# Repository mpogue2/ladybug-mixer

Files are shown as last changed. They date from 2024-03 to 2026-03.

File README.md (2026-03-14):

# ladybug-mixer
Second generation, portable, low-cost audio mixer for square dance callers and round dance cuers

**First pics of the LB-202 enclosure (powder-coated, laser-engraved lettering), and inside components**:

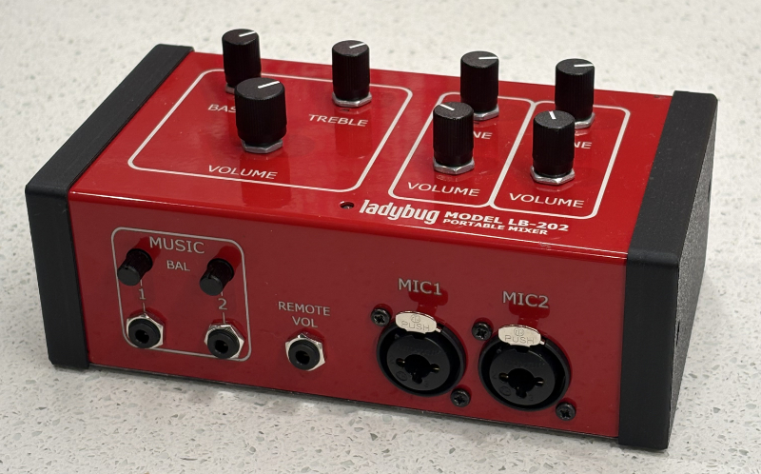
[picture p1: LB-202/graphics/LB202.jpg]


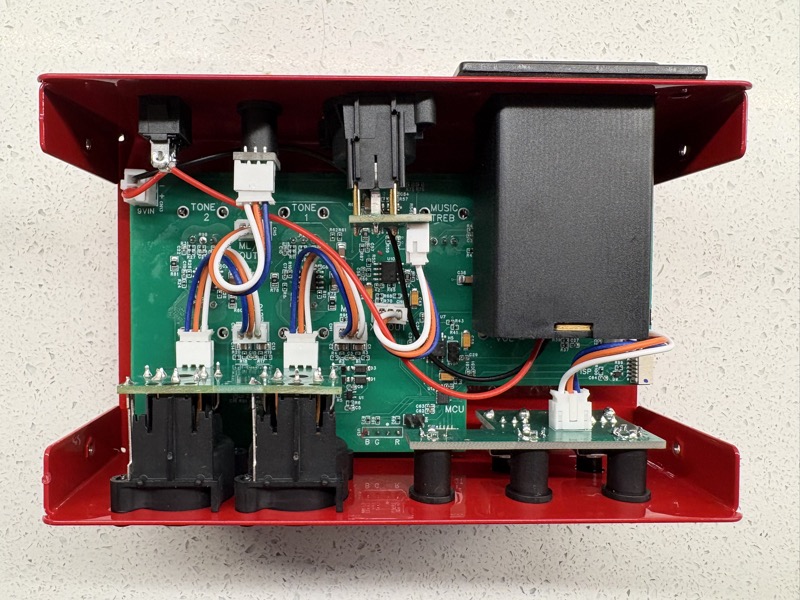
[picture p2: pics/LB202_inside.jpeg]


# Description

The Ladybug LB-202 Mixer is an inexpensive ($150 assembled) compact audio mixer, focused on the needs of beginning and intermediate square dance callers. With the addition of a high-quality dynamic microphone like a [Sennheiser e845 and cable, $100](https://www.amazon.com/Sennheiser-Cardioid-Handheld-Dynamic-Microphone/dp/B07CVK32VV), a [standard XLR mic cable for low-noise output, $10](https://www.amazon.com/dp/B01JNLTTKS), and a powered speaker like an [Alto TS-408, 2000W peak, $275](https://www.amazon.com/Alto-Professional-TS408-Bluetooth-Loudspeaker/dp/B0BB15J4TZ), a caller can provide high-quality sound for 8-10 squares for about $525.  If you have a small-to-medium-sized hall, the [Alto TX-408, 350W peak, $150](https://www.amazon.com/ALTO-Bluetooth-2-Channel-Musicians-Rehearsals/dp/B0DJT7DRHF) also works quite well, and is even less expensive.  These speakers are also chainable, using standard XLR cables, for sounding halls of just about any shape and size.

#### Compatibility with Hilton™-compatible mic cables
For compatibility with existing Hilton™-compatible microphone cables, the Ladybug Mixer provides two features:

1. Two "microphone combo jacks" that let you plug in a Hilton™-compatible 1/4" plug, OR a standard XLR cable (allows for a longer mic cable and best noise suppression, with no "dongle" required).
2. A 1/8" (3.5mm) jack for remote volume control (RVC).  The Ladybug RVC provides two volume-control curves:
    - a "Traditional" curve that matches the volume curve you get with a Hilton™ MA-220, or
    - a "Ladybug" curve that allows you to bring the volume all the way down to zero (MUTE).
   Which curve is in use is selected by using a SIM card tool to press an internal mode-switch button.
   
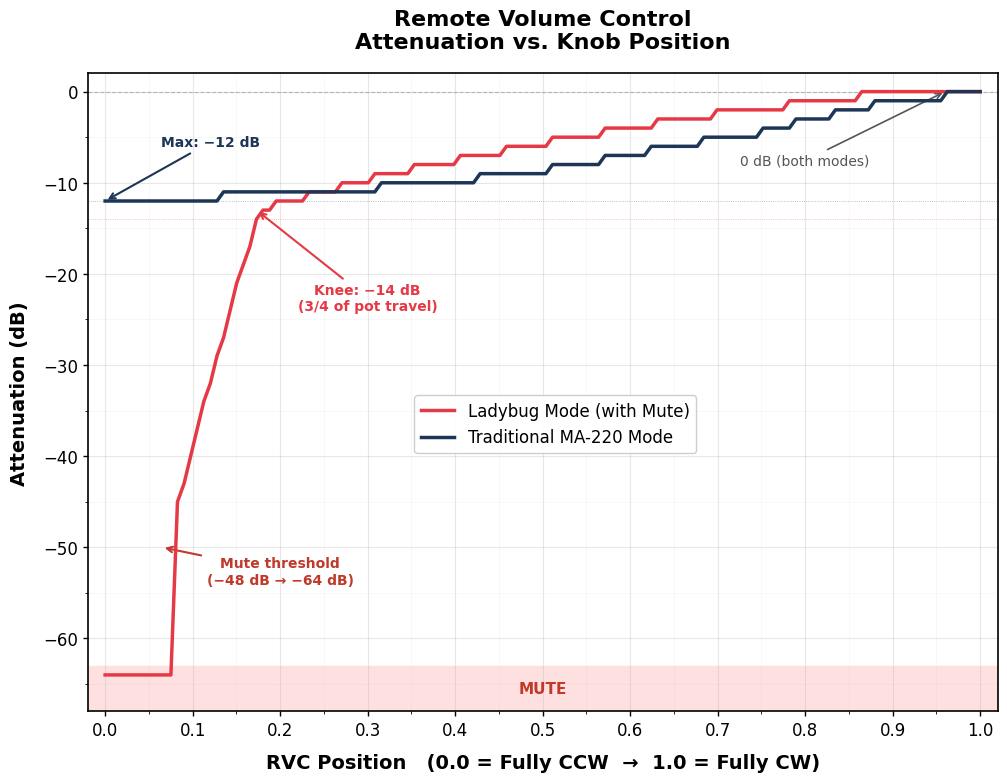
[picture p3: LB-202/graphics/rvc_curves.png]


#### RGB LED modes
The Ladybug LB-202 also provides several LED modes (selectable by using a SIM card tool to press an internal button) for use with the built-in RGB LED:

1. Battery Monitor (normally GREEN, changes to YELLOW, then dims and flashes RED when the battery is low)
2. VU Meter (pulses GREEN with the audio output, and changes to RED when clipping is present)
3. Solid colors (RED, GREEN, BLUE, or WHITE)

#### Long Battery Life
A single 9-volt alkaline battery provides power for lots of dances, and the Ladybug Mixer’s compact size makes it easy to carry. An off-the-shelf 9V alkaline battery ($1.50 from Amazon) will power the Ladybug mixer for about 90 hours (that's a lot of dances!), while a 9V lithium battery ($6.50 from Amazon) will probably last about 150 hours.

#### Open Source Design
The entire Ladybug Mixer design is available under an Open Source License, allowing anybody to modify the design to fit their specific needs. If anybody wants to build these commercially, they can do so, AS LONG AS any modifications they make are passed back to the community under the same licenses.  ***Let the creativity begin!***

> NOTE: The Ladybug LB-202 is a "mixer", and not a "mixer/amplifier".  A Hilton™ MA-220 is both a mixer and an amplifier, so it is able to send 220W of power to UN-powered speakers.  The Ladybug mixer is designed to send a "line-level" signal to speakers that are "powered", that is, the speaker has an amplifier built-in.  There are many popular "powered speakers" available nowadays, like the [Kustom PA-50](https://www.musiciansfriend.com/pro-audio/kustom-pa-pa50-personal-pa-system) (50 watts peak), the [Alto TS-408](https://www.sweetwater.com/store/detail/TS408--alto-ts408-2000-watt-8-inch-powered-speaker) (2000 watts peak), the [Bose L1 column speaker](https://www.bestbuy.com/site/bose-l1-pro8-portable-line-array-system-black) (300 watts peak), and many others.

The LB-202 mixer (shown above) uses a high-quality aluminum case (powder-coated in gloss red, and engraved with a 20W fiber laser), with an aluminum base panel, and black 3D-printed PLA side panels.

#### Differences from the First-generation LB-102 Mixer
| |  LB-102 |  LB-202 |
|---|:-:|:-:|
|  Music 1 vs 2 switch |  ✅ |  ❌ |
|  Music L/R Balance controls |  ❌ |  ✅ for cuers and split tracks |
|  LED |  white |  RGB |
| - VU Meter capability | ❌ | ✅ |
|  Mic tone controls |  12 o'clock position = FLAT EQ |  12 o'clock position matches MA-220 EQ (bass cut + treble boost) |
| Feature control | 2 internal jumpers | 2 user-accessible switches |
| Bottom panel | Black PLA | 5052 Aluminum |
| Firmware flash | Internal 0.1" pin header | Internal JST-SH connector |
| Future experimental features | ❌ | I2C via internal Stemma-QT connector |

# Specs
- 2 Music Inputs (1/8” stereo inputs), with balance controls for each
- 2 Combo Mic Inputs (Lo-Z XLR or Hi-Z [Hilton™-compatible](https://www.hiltonaudio.com/store/c3/Microphone_Cables.html) 1/4“ plug) 
- Remote Volume Control Input (20KΩ [Hilton™-compatible](https://www.hiltonaudio.com/store/c3/Microphone_Cables.html) 1/8” plug)
- Low-noise Balanced Output to powered speaker (XLR, +/- 10 volt differential swing at max volume)
- Separate Music (L) and Voice (R) out (1/8” stereo jack, +/- 2.5 volts swing max)
	- can use Music-only to a monitor speaker
    - can use Voice-only for hearing assist
- Uses a single 9V battery (no power supply to carry around, doesn't need a nearby power outlet)
	- Amazon Basics Alkaline ($1.50 ea. @ AMZN): about 90 hours
	- Tenergy Lithium ($7.00 ea. @ AMZN): about 150 hours
	- USB-rechargeable Lithium ($7.50 ea. @ AMZN): about 50 hours per charge
- RGB LED indicating power ON, battery level (pulses RED when low), and/or audio output level (VU Meter)
- Two pushbutton switches accessible via paperclip from the side, to select Remote Volume Control curve and LED function
- Low noise: -80dBfs
- Wide 3dB Bandwidth: Music 20Hz-20KHz, Voice 50Hz-20KHz
- Small size: about 6.2”W x 2.75”H x 3.8”D (157 x 70 x 97 mm)
- Light weight (with Alkaline battery): about 12.5oz (355g)
- Open Source Hardware, Software, and Mechanical Design (industry-standard open source licenses) = _anybody_ can build, customize, or service devices

# Files available under Open Source licenses
- SCH = schematic
- GERBER = PC board layout
- BOM = Bill of Materials (specifies which parts to place onto the board)
- CPL = "PickAndPlace" file, specifies where to place parts onto the board
- .xcs = xTool Studio files for the laser-engraved top/bottom/back/front
- .f3dz = compressed Fusion 360 files for enclosure and side panels
- .stl = 3D model for the 3D-printed side panels
- .asc/.asy/.pdf = simulation files for LTspice

# Open Source Licenses applying to all contents of this repository
- Hardware = CERN OHL-S (https://ohwr.org/cern_ohl_s_v2.txt)
- Software/Firmware = GNU General Public License version 3 (https://www.gnu.org/licenses/gpl-3.0.txt)
- Documentation = CC BY-SA License (https://creativecommons.org/licenses/by-sa/4.0/legalcode.txt)

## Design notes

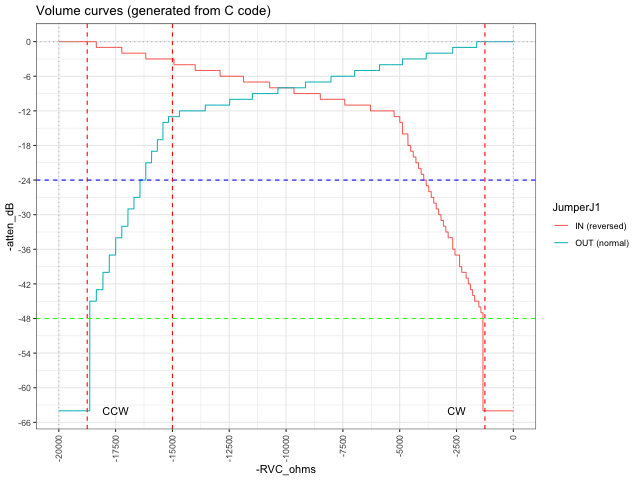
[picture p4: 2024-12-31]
LB-102/V4/Software/MCU_firmware/src/Ladybug RVC Volume Curve Design Target.png

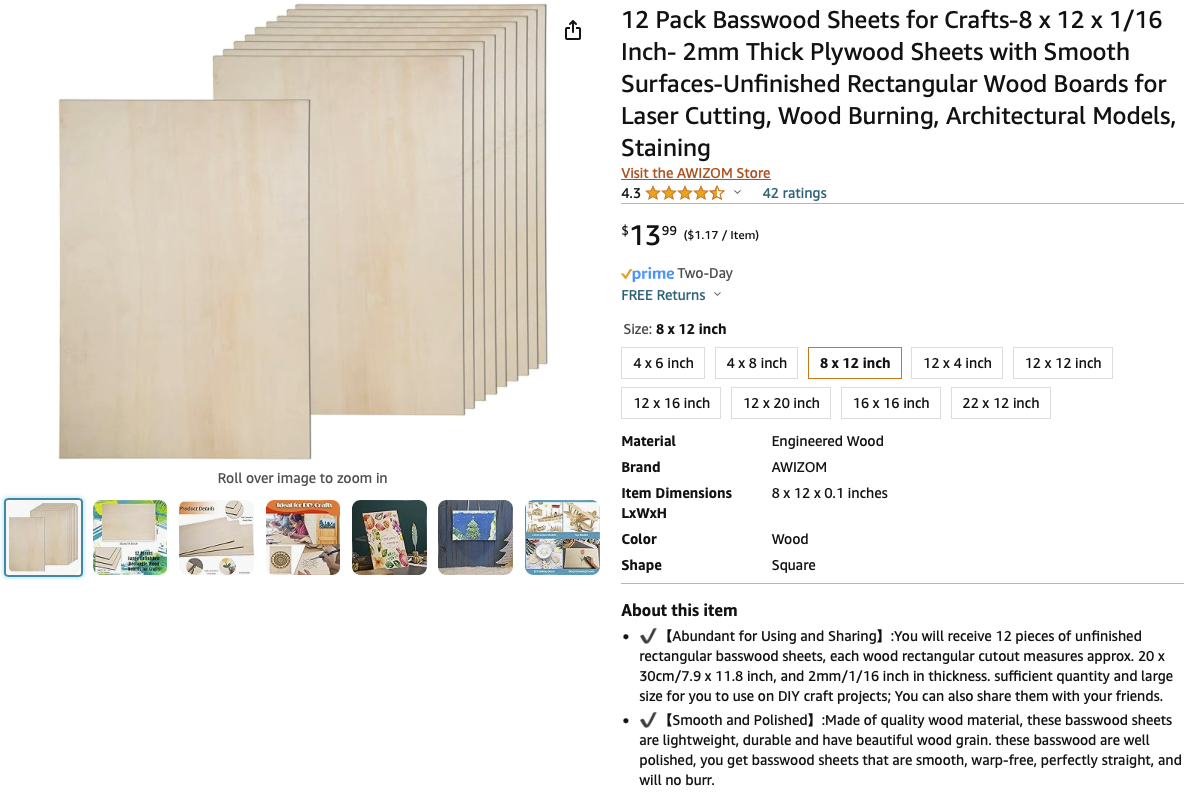
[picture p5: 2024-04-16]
docs/Basswood sheets for laser cut panels.png

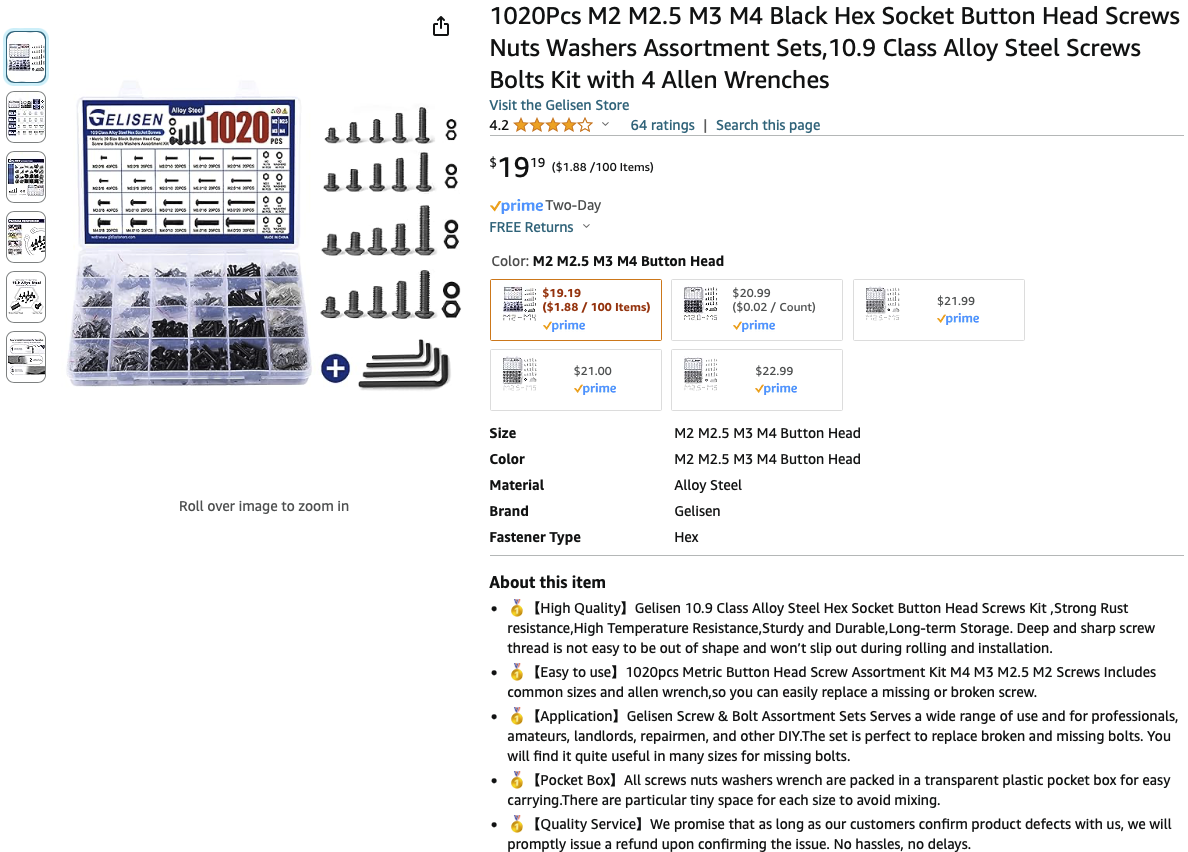
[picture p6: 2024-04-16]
docs/Black hex M2.5 and M2 screws.png

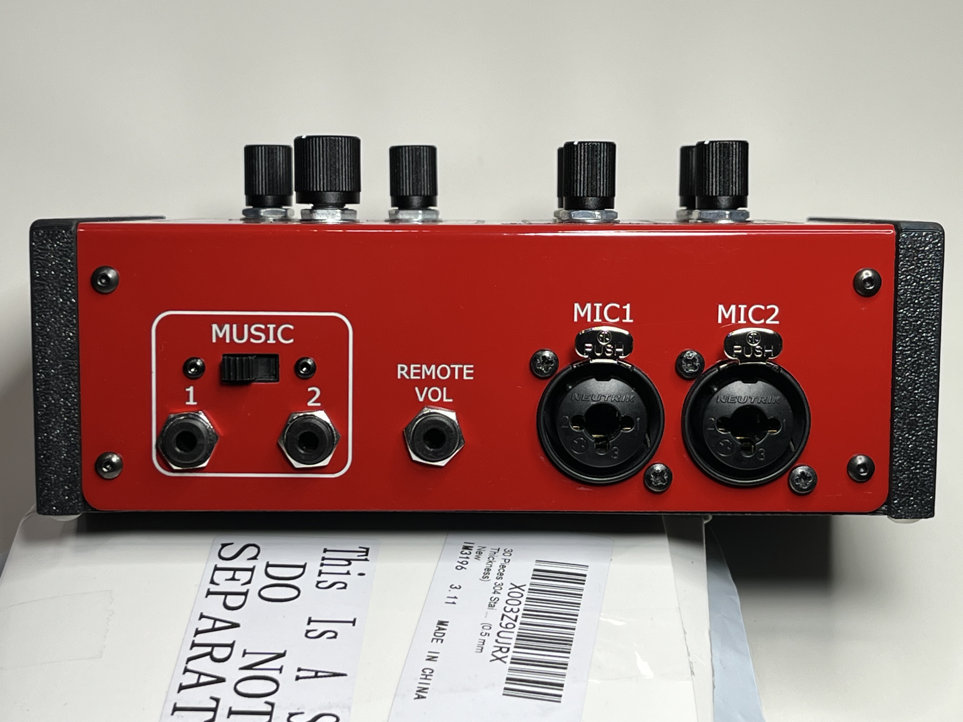
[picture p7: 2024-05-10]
pics/V3_Front.jpeg

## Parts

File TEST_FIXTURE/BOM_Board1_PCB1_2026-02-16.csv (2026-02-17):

No. | Quantity | Comment | Designator | Footprint | Value | Manufacturer Part | Manufacturer | Supplier Part | Supplier | JLCPCB Stock | JLCPCB Price | Add into BOM
1 | 1 | 22uF | C1 | CAP-SMD_L3.2-W1.6 | 22uF | CA45-A-16V-22uF-K | CEC(振华新云) | C782264 | LCSC | 42478 | 0.0231 | yes
2 | 1 | 100nF | C2 | C0402 | 100nF | CL05B104KO5NNNC | SAMSUNG(三星) | C1525 | LCSC | 36001098 | 0.0002 | yes
3 | 12 | 1uF | C3,C4,C5,C6,C15,C16,C17,C18,C19,C20,C21,C22 | C0402 | 1uF | GRM155R61C105KE01D | muRata(村田) | C77007 | LCSC | 587209 | 0.0006 | yes
4 | 8 | 22nF | C7,C8,C9,C10,C11,C12,C13,C14 | C0402 | 22nF | 0402B223K500NT | FH(风华) | C1532 | LCSC | 535509 | 0.0004 | yes
5 | 4 | 47pF | C23,C24,C25,C26 | C0402 | 47pF | 0402CG470J500NT | FH(风华) | C1567 | LCSC | 1735772 | 0.0002 | yes
6 | 4 | SJ-3523-SMT-TR | CN1,CN3,CN4,CN5 | AUDIO-SMD_SJ-3523-SMT-TR |  | SJ-3523-SMT-TR | CUI | C4991872 | LCSC | 880 | 0.2075 | yes
7 | 1 | HC-1.0-5PWT | CN2 | CONN-SMD_5P-P1.00_HCTL_HC-1.0-5PWT |  | HC-1.0-5PWT | HCTL(华灿天禄) | C2845364 | LCSC | 10988 | 0.014 | yes
8 | 1 | 1N5819WS | D1 | SOD-323_L1.8-W1.3-LS2.5-RD |  | 1N5819WS | Hottech(合科泰) | C191023 | LCSC | 2729513 | 0.0013 | yes
9 | 1 | PZ254V-11-02P | H1 | HDR-TH_2P-P2.54-V-M |  | PZ254V-11-02P | XFCN(兴飞) | C492401 | LCSC | 925157 | 0.0019 | yes
10 | 1 | KT-0805G | LED1 | LED0805-R-RD |  | KT-0805G | KENTO | C2297 | LCSC | 2333003 | 0.0024 | yes
11 | 1 | NCD0805R1 | LED2 | LED0805-RD |  | NCD0805R1 | 国星光电 | C84256 | LCSC | 8974619 | 0.002 | yes
12 | 1 | NC3FAH1 | PS1 | CONN-TH_NC3FAH1 |  | NC3FAH1 | NEUTRIK(优曲克) | C368476 | LCSC | 367 | 0.3147 | yes
13 | 1 | 0Ω | R1 | R0603 | 0Ω | 0603WAF0000T5E | UNI-ROYAL(厚声) | C21189 | LCSC | 4484188 | 0.0002 | yes
14 | 3 | 100Ω | R2,R27,R28 | R0402 | 100Ω | 0402WGF1000TCE | UNI-ROYAL(厚声) | C25076 | LCSC | 3925285 | 0.0002 | yes
15 | 9 | 20kΩ | R3,R4,R5,R6,R8,R9,R10,R11,R12 | R0402 | 20kΩ | 0402WGF2002TCE | UNI-ROYAL(厚声) | C25765 | LCSC | 1019773 | 0.0002 | yes
16 | 13 | 10kΩ | R7,R15,R16,R17,R18,R19,R20,R21,R22,R23,R24,R25,R26 | R0402 | 10kΩ | 0402WGF1002TCE | UNI-ROYAL(厚声) | C25744 | LCSC | 8086423 | 0.0002 | yes
17 | 2 | 1kΩ | R13,R14 | R0402 | 1kΩ | 0402WGF1001TCE | UNI-ROYAL(厚声) | C11702 | LCSC | 2605994 | 0.0002 | yes
18 | 1 | TS-1088-AR02016 | SW1 | SW-SMD_L3.9-W3.0-P4.45 |  | TS-1088-AR02016 | XUNPU(讯普) | C720477 | LCSC | 658938 | 0.007 | yes
19 | 1 | STC8G1K08-38I-QFN20 | U1 | TQFN-20L_L3.0-W3.0-P0.40-BL-EP |  | STC8G1K08-38I-QFN20 | STC | C521758 | LCSC | 3989 | 0.0969 | yes
20 | 1 | TPL0501-100DCNR | U2 | SOT-23-8_L3.0-W1.7-P0.65-LS2.8-BL |  | TPL0501-100DCNR | TI(德州仪器) | C131323 | LCSC | 6590 | 0.135 | yes
21 | 2 | NC3MAH | U3,U4 | CONN-TH_NC3MAH |  | NC3MAH | NEUTRIK(优曲克) | C5154126 | LCSC | 175 | 0.2863 | yes

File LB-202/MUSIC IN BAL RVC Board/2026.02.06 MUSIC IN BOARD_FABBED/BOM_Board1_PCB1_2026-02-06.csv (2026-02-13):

No. | Quantity | Comment | Designator | Footprint | Value | Manufacturer Part | Manufacturer | Supplier Part | Supplier | JLCPCB Stock | JLCPCB Price | Add into BOM
1 | 1 | 1nF | C1 | C0402 | 1nF | 0402B102K500NT | FH(风华) | C1523 | LCSC | 487032 | 0.0002 | yes
2 | 2 | 10kΩ | R1,R2 | SW-TH_PTV09A-4015F-B502 | 10kΩ | PTV09A-4220U-B103 | BOURNS | C7328484 | LCSC | 29 | 0.2049 | yes
3 | 2 | 1kΩ | R3,R4 | R0402 | 1kΩ | 0402WGF1001TCE | UNI-ROYAL(厚声) | C11702 | LCSC | 2915378 | 0.0002 | yes
4 | 1 | 47kΩ | R5 | R0402 | 47kΩ | 0402WGF4702TCE | UNI-ROYAL(厚声) | C25792 | LCSC | 2191944 | 0.0002 | yes

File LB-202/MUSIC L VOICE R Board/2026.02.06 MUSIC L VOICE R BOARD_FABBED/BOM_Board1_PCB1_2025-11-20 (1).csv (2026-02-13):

No. | Quantity | Comment | Designator | Footprint | Value | Manufacturer Part | Manufacturer | Supplier Part | Supplier | JLCPCB Stock | JLCPCB Price | Add into BOM
1 | 1 | PJ-31640 | CN1 | AUDIO-TH_XKB_PJ-31640 |  | PJ-31640 | XKB Connectivity(中国星坤) | C2879830 | LCSC | 922 | 0.0645 | yes
2 | 1 | B3B-PH-K-S(LF)(SN) | CN2 | CONN-TH_B3B-PH-K-S |  | B3B-PH-K-S(LF)(SN) | JST | C131339 | LCSC | 146729 | 0.0053 | yes

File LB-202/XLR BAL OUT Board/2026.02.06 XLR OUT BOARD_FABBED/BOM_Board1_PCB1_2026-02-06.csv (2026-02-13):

No. | Quantity | Comment | Designator | Footprint | Value | Manufacturer Part | Manufacturer | Supplier Part | Supplier | JLCPCB Stock | JLCPCB Price | Add into BOM
1 | 1 | B3B-PH-K-S(LF)(SN) | CN1 | CONN-TH_B3B-PH-K-S |  | B3B-PH-K-S(LF)(SN) | JST | C131339 | LCSC | 95840 | 0.0064 | yes
2 | 1 | NC3MAV-0 | PS1 | CONN-TH_NC3MAV-0 |  | NC3MAV-0 | NEUTRIK(优曲克) | C368527 | LCSC | 7 | 0.2969 | yes

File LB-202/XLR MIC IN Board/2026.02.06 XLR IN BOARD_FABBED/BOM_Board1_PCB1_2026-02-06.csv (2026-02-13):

No. | Quantity | Comment | Designator | Footprint | Value | Manufacturer Part | Manufacturer | Supplier Part | Supplier | JLCPCB Stock | JLCPCB Price | Add into BOM
1 | 2 | NCJ6FA-V | PS1,PS2 | CONN-TH_NCJ6FA-V |  | NCJ6FA-V | NEUTRIK(优曲克) | C368485 | LCSC | 103 | 0.4954 | yes

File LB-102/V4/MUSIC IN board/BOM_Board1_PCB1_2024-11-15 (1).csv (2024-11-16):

No. | Quantity | Comment | Designator | Footprint | Value | Manufacturer Part | Manufacturer | Supplier Part | Supplier | JLCPCB Stock | JLCPCB Price | Add into BOM
1 | 2 | PJ-31640 | CN1,CN2 | AUDIO-TH_XKB_PJ-31640 |  | PJ-31640 | XKB Connectivity(中国星坤) | C2879830 | LCSC | 221 | 0.4216 | yes
2 | 1 | B3B-PH-K-S(LF)(SN) | CN3 | CONN-TH_B3B-PH-K-S |  | B3B-PH-K-S(LF)(SN) | JST | C131339 | LCSC | 118662 | 0.0331 | yes
3 | 2 | A2005WV-5P | CN4,CN5 | HDR-TH_5P-P2.00-V-M |  | A2005WV-5P | CJT(长江连接器) | C225257 | LCSC | 275 | 0.0772 | yes

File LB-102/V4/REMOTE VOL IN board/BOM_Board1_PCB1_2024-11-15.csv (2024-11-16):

No. | Quantity | Comment | Designator | Footprint | Value | Manufacturer Part | Manufacturer | Supplier Part | Supplier | JLCPCB Stock | JLCPCB Price | Add into BOM
1 | 1 | PJ-31640 | CN1 | AUDIO-TH_XKB_PJ-31640 |  | PJ-31640 | XKB Connectivity(中国星坤) | C2879830 | LCSC | 221 | 0.4216 | yes
2 | 1 | B2B-PH-K-S(LF)(SN) | CN2 | CONN-TH_B2B-PH-K-S |  | B2B-PH-K-S(LF)(SN) | JST | C131337 | LCSC | 57141 | 0.029 | yes

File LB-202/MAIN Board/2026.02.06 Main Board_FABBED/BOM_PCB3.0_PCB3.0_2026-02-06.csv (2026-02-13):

No. | Quantity | Comment | Designator | Footprint | Value | Manufacturer Part | Manufacturer | Supplier Part | Supplier | JLCPCB Stock | JLCPCB Price | Add into BOM
1 | 4 | 22uF | C1,C2,C13,C14 | C0805 | 22uF | CL21A226MAQNNNE | SAMSUNG(三星) | C45783 | LCSC | 4498354 | 0.0039 | yes
2 | 6 | 10nF | C3,C9,C10,C15,C21,C22 | C0402 | 10nF | CL05B103KB5NNNC | SAMSUNG(三星) | C15195 | LCSC | 2679514 | 0.0003 | yes
3 | 13 | 20pF | C4,C5,C7,C11,C16,C17,C19,C23,C37,C54,C55,C56,C57 | C0402 | 20pF | 0402CG200J500NT | FH(风华) | C1554 | LCSC | 1390048 | 0.0002 | yes
4 | 14 | 100nF | C6,C8,C18,C20,C30,C31,C36,C39,C42,C48,C50,C51,C52,C62 | C0402 | 100nF | CL05B104KO5NNNC | SAMSUNG(三星) | C1525 | LCSC | 37249744 | 0.0002 | yes
5 | 5 | 10uF | C12,C24,C38,C40,C41 | C1206 | 10uF | CL31A106KBHNNNE | SAMSUNG(三星) | C13585 | LCSC | 877474 | 0.0087 | yes
6 | 1 | 47pF | C25 | C0402 | 47pF | 0402CG470J500NT | FH(风华) | C1567 | LCSC | 525192 | 0.0002 | yes
7 | 2 | 1uF | C27,C29 | C0402 | 1uF | CL05A105KA5NQNC | SAMSUNG(三星) | C52923 | LCSC | 5134488 | 0.0005 | yes
8 | 4 | 10uF | C32,C43,C44,C58 | CAP-SMD_L3.2-W1.6-RD-C7171 | 10uF | TAJA106K016RNJ | Kyocera AVX | C7171 | LCSC | 747405 | 0.0197 | yes
9 | 2 | 47nF | C33,C35 | C0603 | 47nF | CL10B473KB8NNNC | SAMSUNG(三星) | C1622 | LCSC | 2765952 | 0.0008 | yes
10 | 1 | 560pF | C34 | C0402 | 560pF | CC0402JRX7R9BB561 | YAGEO(国巨) | C541456 | LCSC | 7396 | 0.0003 | yes
11 | 1 | 10uF | C45 | CASE-B_3528 | 10uF | CA45-B-25V-10uF-K | CEC(振华新云) | C128259 | LCSC | 94160 | 0.0191 | yes
12 | 1 | 100nF | C46 | C0402 | 100nF | CL05B104KB54PNC | SAMSUNG(三星) | C307331 | LCSC | 45539919 | 0.0006 | yes
13 | 3 | 22uF | C47,C49,C53 | CAP-SMD_L3.2-W1.6 | 22uF | CA45-A-16V-22uF-K | CEC(振华新云) | C782264 | LCSC | 23782 | 0.0228 | yes
14 | 2 | 1nF | C61,C63 | C0402 | 1nF | 0402B102K500NT | FH(风华) | C1523 | LCSC | 487597 | 0.0002 | yes
15 | 5 | B3B-PH-K-S(LF)(SN) | CN1,CN2,CN3,CN5,CN6 | CONN-TH_B3B-PH-K-S |  | B3B-PH-K-S(LF)(SN) | JST | C131339 | LCSC | 95840 | 0.0064 | yes
16 | 1 | B2B-XH-A(LF)(SN) | CN13 | CONN-TH_B2B-XH-A-LF-SN |  | B2B-XH-A(LF)(SN) | JST | C158012 | LCSC | 360761 | 0.0054 | yes
17 | 1 | HCZZ0039-4 | CN14 | CONN-SMD_HCZZ0039-4 |  | HCZZ0039-4 | HC(虹成电子) | C7433440 | LCSC | 26349 | 0.0051 | yes
18 | 1 | HC-1.0-5PWT | CN15 | CONN-SMD_5P-P1.00_HCTL_HC-1.0-5PWT |  | HC-1.0-5PWT | HCTL(华灿天禄) | C2845364 | LCSC | 11042 | 0.0138 | yes
19 | 8 | 1N4004W | D1,D2,D3,D4,D5,D6,D7,D8 | SOD-123FL_L2.7-W1.8-LS3.8-RD |  | 1N4004W | R+O(宏嘉诚) | C18199087 | LCSC | 1900 | 0.0013 | yes
20 | 1 | 1N5819WS | D9 | SOD-323_L1.8-W1.3-LS2.5-RD |  | 1N5819WS | Hottech(合科泰) | C191023 | LCSC | 2832716 | 0.0013 | yes
21 | 1 | PZ254V-11-02P | H6 | HDR-TH_2P-P2.54-V-M |  | PZ254V-11-02P | XFCN(兴飞) | C492401 | LCSC | 842723 | 0.0019 | yes
22 | 8 | 160Ω | R1,R2,R3,R4,R17,R18,R19,R20 | R0402 | 160Ω | FRC0402F1600TS | FOJAN(富捷) | C2933075 | LCSC | 92191 | 0.0001 | yes
23 | 4 | 2.2kΩ | R5,R6,R21,R22 | R0402 | 2.2kΩ | 0402WGF2201TCE | UNI-ROYAL(厚声) | C25879 | LCSC | 1011850 | 0.0002 | yes
24 | 2 | 3.3kΩ | R8,R24 | R0402 | 3.3kΩ | 0402WGF3301TCE | UNI-ROYAL(厚声) | C25890 | LCSC | 853337 | 0.0002 | yes
25 | 3 | 15kΩ | R9,R25,R52 | R0402 | 15kΩ | 0402WGF1502TCE | UNI-ROYAL(厚声) | C25756 | LCSC | 437762 | 0.0002 | yes
26 | 4 | 20kΩ | R10,R26,R74,R76 | R0402 | 20kΩ | 0402WGF2002TCE | UNI-ROYAL(厚声) | C25765 | LCSC | 1133604 | 0.0002 | yes
27 | 12 | 22kΩ | R11,R16,R27,R32,R37,R40,R45,R48,R57,R58,R59,R87 | R0402 | 22kΩ | 0402WGF2202TCE | UNI-ROYAL(厚声) | C25768 | LCSC | 428385 | 0.0002 | yes
28 | 16 | 47kΩ | R12,R28,R39,R41,R43,R50,R55,R56,R71,R72,R75,R77,R93,R94,R95,R96 | R0402 | 47kΩ | 0402WGF4702TCE | UNI-ROYAL(厚声) | C25792 | LCSC | 2191869 | 0.0002 | yes
29 | 7 | 5.1kΩ | R14,R15,R30,R31,R73,R91,R92 | R0402 | 5.1kΩ | 0402WGF5101TCE | UNI-ROYAL(厚声) | C25905 | LCSC | 2518781 | 0.0002 | yes
30 | 6 | 1kΩ | R34,R62,R63,R69,R70,R104 | R0402 | 1kΩ | 0402WGF1001TCE | UNI-ROYAL(厚声) | C11702 | LCSC | 2916144 | 0.0002 | yes
31 | 9 | 10kΩ | R42,R47,R60,R61,R65,R66,R67,R68,R100 | R0402 | 10kΩ | 0402WGF1002TCE | UNI-ROYAL(厚声) | C25744 | LCSC | 9312414 | 0.0002 | yes
32 | 1 | 1MΩ | R49 | R0402 | 1MΩ | 0402WGF1004TCE | UNI-ROYAL(厚声) | C26083 | LCSC | 4490471 | 0.0002 | yes
33 | 3 | 11kΩ | R53,R54,R86 | R0805 | 11kΩ | 0805W8F1102T5E | UNI-ROYAL(厚声) | C17429 | LCSC | 113289 | 0.0003 | yes
34 | 1 | 47kΩ | R64 | R0805 | 47kΩ | 0805W8F4702T5E | UNI-ROYAL(厚声) | C17713 | LCSC | 1609920 | 0.0003 | yes
35 | 8 | 0Ω | R78,R79,R80,R81,R82,R83,R84,R85 | R0805 | 0Ω | 0805W8F0000T5E | UNI-ROYAL(厚声) | C17477 | LCSC | 4961409 | 0.0004 | yes
36 | 2 | 100kΩ | R97,R98 | R0402 | 100kΩ | 0402WGF1003TCE | UNI-ROYAL(厚声) | C25741 | LCSC | 6965776 | 0.0002 | yes
37 | 1 | 100Ω | R99 | R0402 | 100Ω | 0402WGF1000TCE | UNI-ROYAL(厚声) | C25076 | LCSC | 3836613 | 0.0002 | yes
38 | 1 | 0Ω | R101 | R0603 | 0Ω | 0603WAF0000T5E | UNI-ROYAL(厚声) | C21189 | LCSC | 5017889 | 0.0002 | yes
39 | 2 | 4.7kΩ | R102,R103 | R0402 | 4.7kΩ | 0402WGF4701TCE | UNI-ROYAL(厚声) | C25900 | LCSC | 6073212 | 0.0002 | yes
40 | 2 | TS-1084-AR03526 | SW1,SW2 | SW-SMD_TS-1084-AR03526 |  | TS-1084-AR03526 | XUNPU(讯普) | C720495 | LCSC | 6627 | 0.0104 | yes
41 | 2 | TLV6741DCKR | U1,U3 | SC-70-5_L2.0-W1.3-P0.65-LS2.1-BR |  | TLV6741DCKR | TI(德州仪器) | C2760465 | LCSC | 5939 | 0.1095 | yes
42 | 5 | MCP6002-I/SN | U2,U4,U5,U9,U10 | SOIC-8_L4.9-W3.9-P1.27-LS6.0-BL |  | MCP6002-I/SN | MICROCHIP(美国微芯) | C116706 | LCSC | 4310 | 0.0499 | yes
43 | 1 | LM1971MX/NOPB | U6 | SOIC-8_L4.9-W3.9-P1.27-LS6.0-BL |  | LM1971MX/NOPB | TI(德州仪器) | C129348 | LCSC | 97 | 0.2921 | yes
44 | 1 | MCP6001T-I/OT | U7 | SOT-23-5_L3.0-W1.7-P0.95-LS2.8-BR |  | MCP6001T-I/OT | MICROCHIP(美国微芯) | C116490 | LCSC | 99885 | 0.034 | yes
45 | 1 | HT7550-1 | U8 | SOT-89_L4.5-W2.5-P1.50-LS4.2-BR |  | HT7550-1 | UMW(友台半导体) | C347189 | LCSC | 410147 | 0.0059 | yes
46 | 1 | STC8G1K08-38I-QFN20 | U12 | TQFN-20L_L3.0-W3.0-P0.40-BL-EP |  | STC8G1K08-38I-QFN20 | STC | C521758 | LCSC | 4006 | 0.0957 | yes

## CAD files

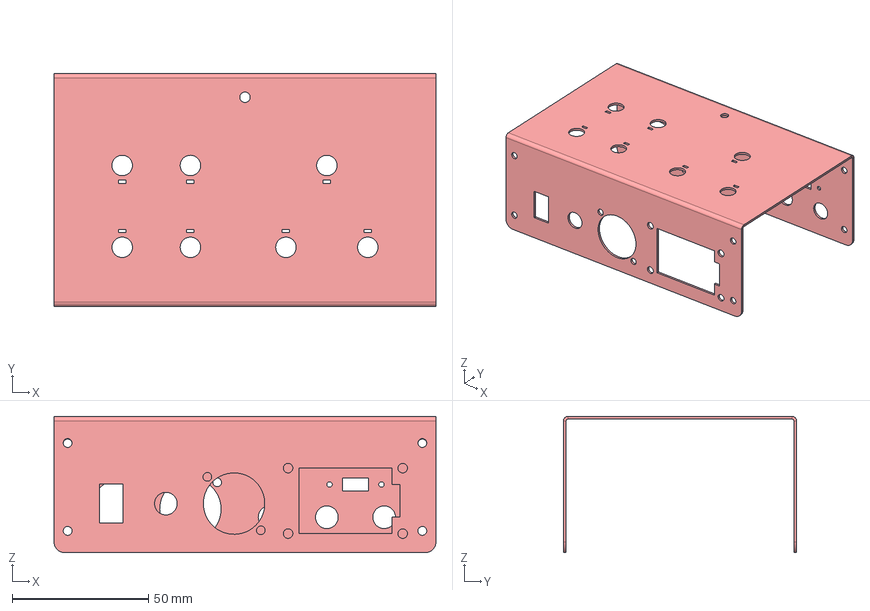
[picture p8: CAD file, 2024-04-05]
LB-102/V4/Enclosure/V3 Enclosure Simple v14_FABBED.step
140.0 x 85.5 x 50.0 mm

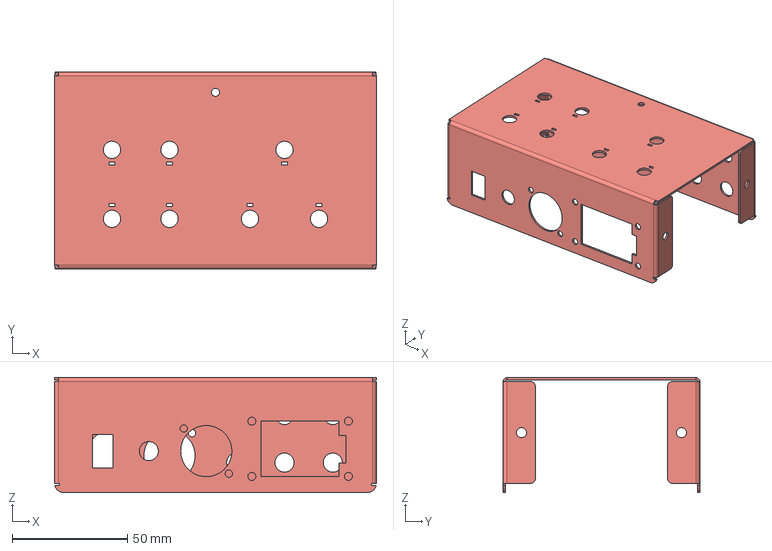
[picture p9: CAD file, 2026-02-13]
LB-202/Enclosure/Fabworks_FABBED/TOP_V11_2026.02.05.step
140.0 x 85.5 x 50.0 mm

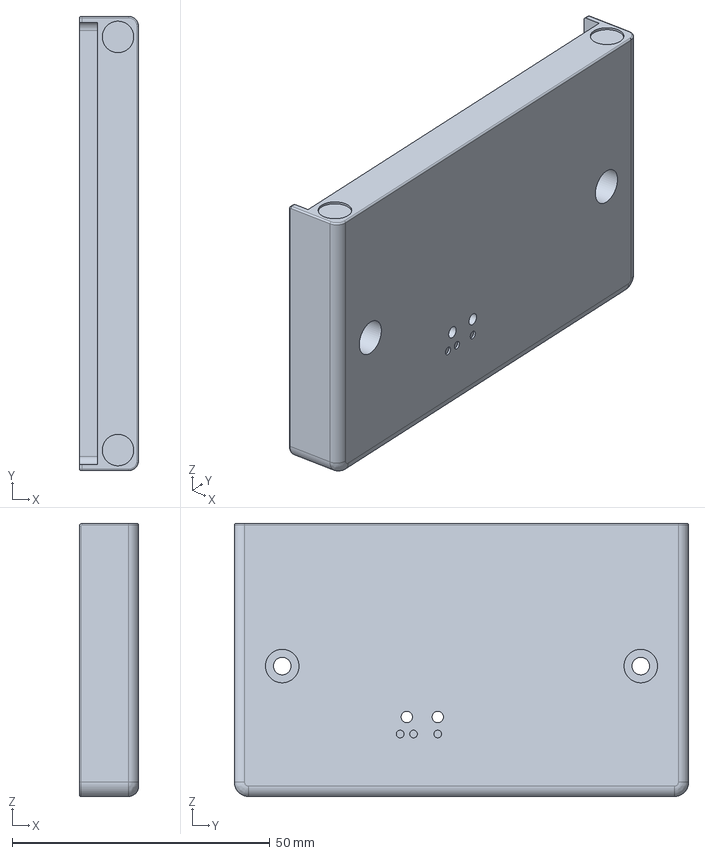
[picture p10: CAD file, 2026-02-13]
LB-202/Enclosure/Side Panels_FABBED/LEFT ENDCAP V18.step
11.5 x 88.1 x 53.0 mm

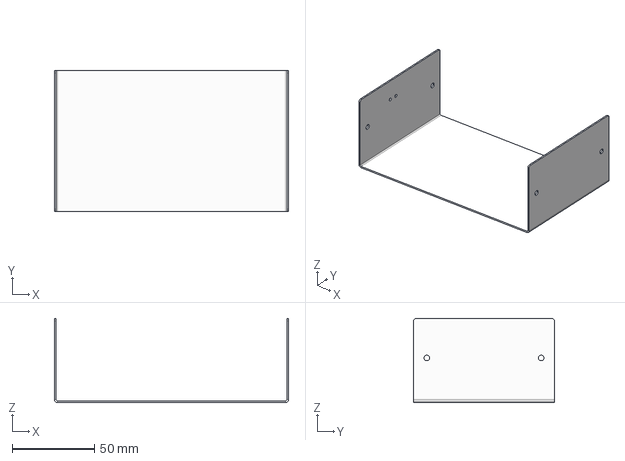
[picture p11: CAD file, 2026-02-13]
LB-202/Enclosure/Fabworks_FABBED/BOTTOM_V11_2026.02.05.step
142.2 x 85.5 x 51.1 mm

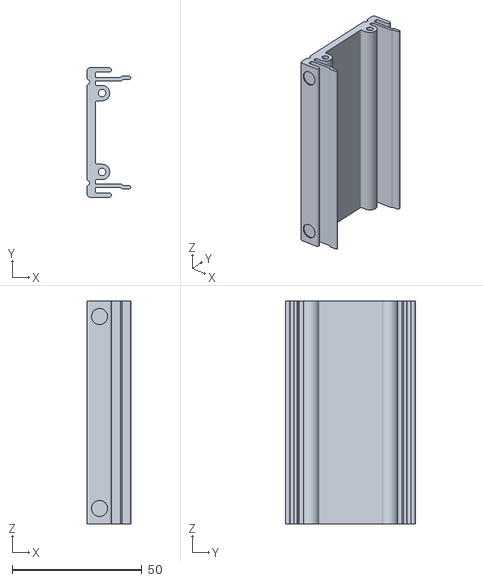
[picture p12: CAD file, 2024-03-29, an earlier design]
LB-102/V2/Enclosure/3DprintedSidePanels/sidePanel_V2 Body4.stl
16.8 x 50.0 x 86.0

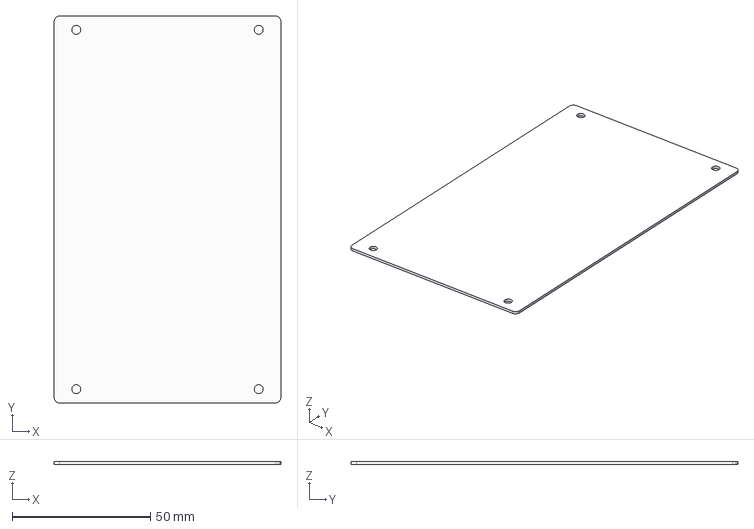
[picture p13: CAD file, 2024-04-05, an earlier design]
LB-102/V3/Enclosure/old/V3 Enclosure BOTTOM v4_FABBED.step
82.0 x 140.0 x 1.02 mm

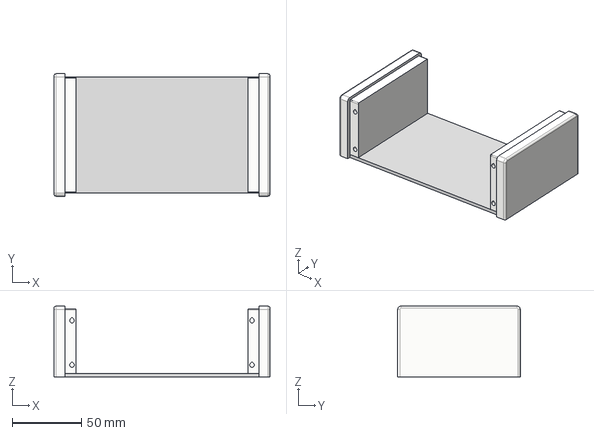
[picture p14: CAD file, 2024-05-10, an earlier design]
LB-102/V3/Enclosure/SidePanels/V3 U-shaped bottom + side panels v5.step
156.0 x 88.5 x 51.1 mm
V3 side panel x 2

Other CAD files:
LB-202/Enclosure/Side Panels_FABBED/RIGHT ENDCAP V9.step
LB-102/V2/Enclosure/3DprintedSidePanels/sidePanel_V2 v9 Fusion.f3d
LB-102/V3/Enclosure/SidePanels/V3 U-shaped bottom + side panels v5.f3z
LB-102/V3/Enclosure/V3 Enclosure Simple v14_FABBED.f3d
LB-102/V3/Enclosure/old/V3 Enclosure BOTTOM v4_FABBED.f3d
LB-102/V4/Enclosure/V3 Enclosure Simple v14_FABBED.f3d
V3/Enclosure/V3 Enclosure BOTTOM v4_FABBED.f3d

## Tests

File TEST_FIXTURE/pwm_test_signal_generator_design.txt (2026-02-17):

PWM Test Signal Generator Design Discussion
============================================
Date: February 16, 2026
Project: Ladybug Mixer Test Fixture

OVERVIEW
--------
Design of a PWM-based test signal generator using an STC8G1 MCU (24MHz)
to produce test tones for the Ladybug audio mixer's mic and music inputs.

MCU: STC8G1 @ 24MHz
PWM: 10-bit (1024 counts) → 23.4kHz PWM frequency
Signal: 1kHz sine tone

================================================================================
MIC OUTPUT SIDE
================================================================================

Target: ~2mV differential balanced output @ 1kHz

Circuit: PWM → 2-stage RC LPF → unbalanced-to-balanced voltage divider → XLR

Components:
  - R136: 10kΩ (filter stage 1)
  - C100: 22nF (filter stage 1)
  - R137: 10kΩ (filter stage 2)
  - C101: 22nF (filter stage 2)
  - R160: 10kΩ (divider, hot leg) — use 1% matched with R161
  - R163: 100Ω (divider, center)
  - R161: 10kΩ (divider, cold leg) — use 1% matched with R160
  - C76: 1µF (coupling cap, hot)
  - C77: 1µF (coupling cap, cold)
  - U15: NC3MAH XLR connector

Filter characteristics:
  - fc ≈ 720Hz per stage
  - Stage 1 attenuation at 1kHz: -4.7dB (×0.58)
  - Stage 2 attenuation at 1kHz (with 20.1kΩ divider load): -6dB (×0.49)
  - Divider ratio: 1/201 (-46dB, ×0.005)
  - Net attenuation: ×0.0014
  - At 56% duty cycle swing → 2mV differential output
  - PWM ripple at 23.4kHz: ~23µV differential (~1% of signal)

Notes:
  - Output impedance ~10kΩ per leg
  - Ladybug balanced mic input impedance ~2.8kΩ
  - Some signal loss to load expected; calibrate actual level with meter
  - Balance won't be perfect due to impedance mismatch, acceptable for functional testing
  - Not suitable for CMRR testing

================================================================================
MUSIC OUTPUT SIDE
================================================================================

Target: ~1-2V p-p unbalanced output @ 1kHz

Circuit: PWM → 2-stage RC LPF → coupling cap → output

Components:
  - Filter resistors: 10kΩ each stage
  - Filter caps: 22nF each stage
  - Coupling cap: 1µF series

Filter characteristics:
  - fc ≈ 720Hz per stage
  - At 1kHz: ~-6dB total (two stages)
  - ~2.5V available at full swing
  - Ladybug music input impedance ~70kΩ (minimal loading)

================================================================================
LADYBUG INPUT CIRCUITS (for reference)
================================================================================

Balanced Mic Input (TLV6741 difference amplifier):
  - Input resistors: R1+R3 = 160+160 = 320Ω per leg
  - Feedback resistors: R5 = R6 = 2.2kΩ
  - Gain: 2.2k/320 = 6.875 (+17dB)
  - Inverting leg impedance: ~320Ω
  - Non-inverting leg impedance: ~2.5kΩ
  - Differential input impedance: ~2.8kΩ

Music/RVC Input (MCP6002 buffer):
  - R34 (1kΩ) + R37 (22kΩ) + R39 (47kΩ) ≈ 70kΩ at audio

================================================================================
PWM RESOLUTION NOTES
================================================================================

STC8G1 PWM options (at 24MHz):
  - 6-bit:  64 counts,  375 kHz    — too few steps
  - 7-bit:  128 counts, 187.5 kHz  — poor resolution
  - 8-bit:  256 counts, 93.75 kHz  — usable
  - 10-bit: 1024 counts, 23.4 kHz  — chosen (good resolution)

At 10-bit:
  - ~82 usable duty cycle steps in ±4% range
  - ~23 samples per 1kHz sine cycle
  - Effective sine resolution: ~6.4 bits
  - THD after filtering: well under 1%

================================================================================
KEY DESIGN DECISIONS
================================================================================

1. 10-bit PWM chosen over 8-bit for better sine quality (82 vs 20 steps)
2. 22nF caps (not 220nF) to avoid excessive attenuation at 1kHz
3. 10kΩ/100Ω/10kΩ divider chosen as compromise between:
   - 100kΩ/1kΩ/100kΩ (too high output impedance for Ladybug input)
   - 1kΩ/10Ω/1kΩ (too much filter loading)
4. Same filter resistors (10kΩ) and caps (22nF) for both mic and music sides
5. Music side needs no voltage divider — just duty cycle adjustment

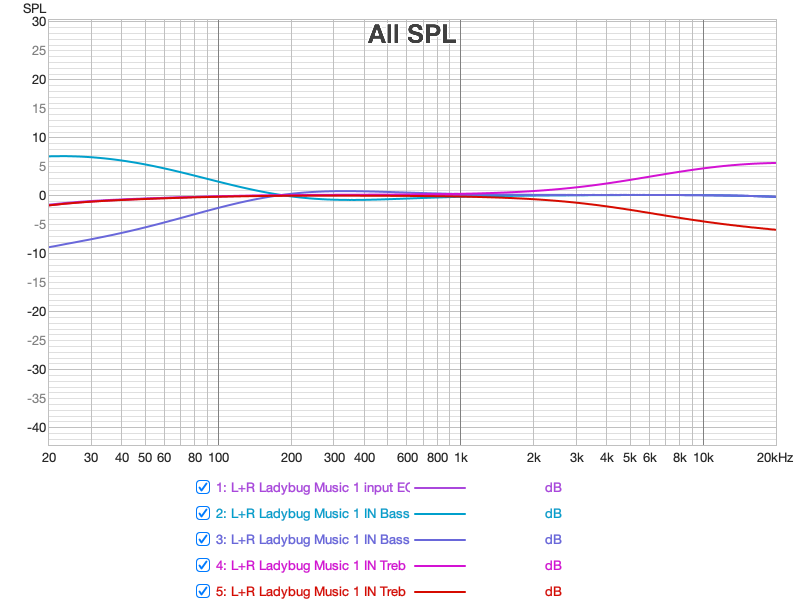
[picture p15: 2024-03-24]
tests/BandwidthAndEQ/V2_Music.png

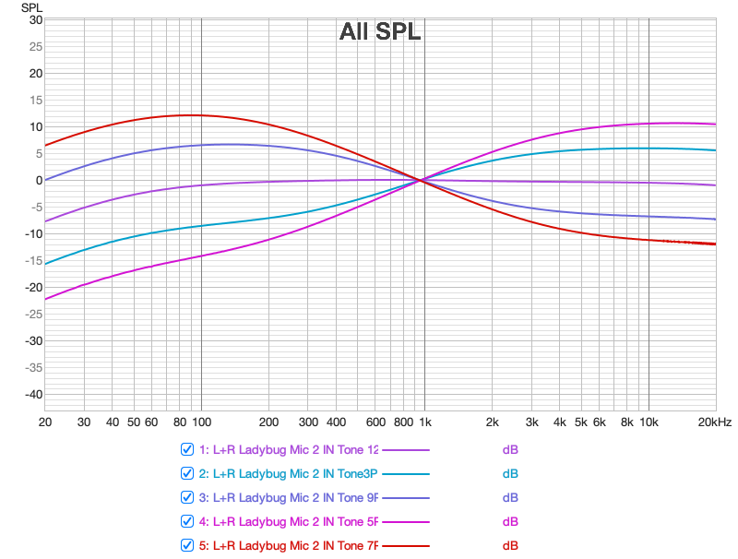
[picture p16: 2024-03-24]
tests/BandwidthAndEQ/V2_Mic2.png

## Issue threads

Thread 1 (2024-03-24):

TODO: V2 items for V3

mpogue2, 2024-03-24:
- add about 6dB of additional amplification (make sure does not exceed ±2.5V output for typical input though) **DONE**
- change tantalums to higher voltage to avoid future explosions  **DONE**
- move pots to after the tone controls to reduce noise when pots at min position  **DONE**
- eliminate JST PH connectors (next version can hard-wire, if appropriate)  **DONE**
- switch to single OP AMP (probably pick MIC 1 op amp, which has 3dB lower noise)  **DONE**
- add some jumpers to tell MCU some config info (might need diodes or resistors here)  **DONE**
  - Remote vol control direction is reversed from normal
  - Remove vol control goes all the way to zero (vs not)
  - LM1971 is not present (can this be figured out without a jumper via I2C -- nope, this cannot)
  - etc
- eliminate test jumpers, replace with pads + surface trace  **DONE**
- finalize the name (LB-102 vs  LB-201 etc.) - yeah, it's now LB-102  **DONE**
- add rear panel pics to the cut sheet

mpogue2, 2024-03-31:
Instead of jumpers, use 0 ohm resistors for test points.

mpogue2, 2024-04-01:
Replace LM1971 with C129348, which costs about $2.60 ea.
These are out of stock, but can be pre-purchased. Delay is <20 working days.  Then I can have them auto-assembled into boards.  I can also "consign" parts, that is, I buy the parts and send to them.

mpogue2, 2024-04-01:
**Pre-order**: https://jlcpcb.com/help/article/53-what-is-jlcpcb-parts-pre-order-service
**Consignment**: https://jlcpcb.com/help/article/245-how-to-consign-parts-to-jlcpcb

mpogue2, 2024-04-05:
LM1971MX/NOPB (Arrow) = Q10+ $1.32 ea.  These are C129348 in JLCPCB's numbering system.
This looks like the best Global Sourcing deal.  Takes 8-15 days, plus 1-2 days for review.
I'm gonna switch to this part, and mark it Do Not Populate for these first prototypes, but this will make it easier to order them for automated assembly next time.

mpogue2, 2024-04-05:
V3 boards (main board and XLR board) have been submitted to JLCPCB for fabrication.  Files have been posted to the repository.  Note that I could not do the manual op amp swap, because it generated an error and refused to populated the MCP6002s.  So, I went with the parts that I had in the schematic that are slightly more expensive, but should be identical.
The parts swap was only for testing (which is not needed for V3) and for cost reduction (minimal, so I gave up on it for V3).

V3 enclosure parts (5052-Al for top and bottom) have been submitted to Fabworks for fabrication. Files have been posted to the repository.

Closing this issue.

Closed 2024-04-05.

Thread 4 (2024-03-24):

Feature: FR-4 box

mpogue2, 2024-03-24:
in process
This will be sturdier than the laser-cut wood panels that I'm now using.  Silk-screened labels are also nice.  Can also use solder mask as part of the design.

mpogue2, 2024-04-05:
I'm gonna skip the FR-4 prototype box, and go right to the 5052-Al box with wood/3D-printed side panels.  It's not that expensive to do so, and it's a lot more sturdy, and more professional-looking.

Closed 2024-04-05.

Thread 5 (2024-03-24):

Feature: aluminum box with wood sides

mpogue2, 2024-03-24:
Like these, but perhaps powder coat in red, with silk screen or engraved labels, and use ebonized ash for the sides.  This should be fairly cheap, if we use one of the online CNC sheet metal houses (e.g. eMachineShop, fab works, SendCutSend, OSHcut, et.al.).  Engraving could be done by me via CNC mill or via laser engraver (MaxerNexus, maybe?).

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

mpogue2, 2024-03-29:
Hammond has some nice looking ones, but they are pricey (about $100 for this one, that is only 7"x5"x2")!
This might be nice for the next prototype, OR I could CNC mill + use Rubio Monocoat on the walnut sides, and have the sheet metal fabricated by one of the above service bureaus.

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

mpogue2, 2024-03-29:
I kinda like powder-coated red for the aluminum, rather than the natural aluminum finish, and perhaps ebonized ash for the sides....lettering would need to be engraved, though, perhaps by laser (unless one of the bureaus can do it)?

mpogue2, 2024-03-29:
**Fabworks**: Ventura, CA, does laser cutting (down to 0.040" 5052 Al), bending, powder coating, PEM insertion; prefers OnShape, but will take Fusion files too

**SendCutSend**: Nevada, laser cutting, bending, powder coating, PEM insertion; prefers SolidWorks, has excellent blog with lots of hints and tips articles, requires 0.063" thickness for powder coating (!)

**OSHcut**: Utah, laser cutting, bending, powder coating, NO PEM INSERTION;

NOTE: Hammond uses 0.040" = 18 gauge Al for their enclosures.

Most of these take DXF (unfolded) or STEP (FabWorks takes it folded, I think).

mpogue2, 2024-03-30:
Did a quick sheet metal mockup in Fusion 360, with holes in approximately the right places.  Quotes do not include wood or 3D-printed side panels, or a bottom aluminum panel.  These are NOT powder-coated, nor do they contain PEM hardware, so these are just cut and bend.

**FabWorks** (STEP format file): $17.12 ea, including shipping, ships in about 5 days
**SendCutSend**:
**OSHcut**:

mpogue2, 2024-03-30:
### Simplified design, without the two extra flanges for the bottom

**FabWorks**: **$12.09 ea Q2** deburred, $21.13 ea Q2 red $18.76 ea Q10 powder-coated
**OSHcut**: **$41 ea Q2** deburred, $93 ea Q2 red $38 ea Q10 powder-coated
**Ponoko**: **$47.42 ea Q2** NOT deburred, $18.21 ea Q10 NOT deburred

mpogue2, 2024-03-30:
**FabWorks** seems like the clear winner here, in terms of price, both for deburred and for red powder-coated aluminum parts.

**Fiber laser** seems like a good idea for making the markings on each side.  See [here](https://www.youtube.com/watch?v=5g_XDGyWqpY).  They use black in this video, but other sources suggested that red works as well.  Will need to test this.

mpogue2, 2024-03-30:
### XY Laser Cutters
**Maker Nexus**: $150/month -- 45W Epilog Helix, 100W Boss Laser LS2440, 100W "Red Laser bed"
**Hacker Dojo**: $150/month -- 100W Thunder Laser

mpogue2, 2024-03-31:
Here's a rendering of the V8 version of the simple (no bottom flanges) version of the V3 box design.
Sides will be 3D printed and/or ebonized ash wood.  This rendering is simulating a red anodized finish.  I'm also looking at a red powder-coated finish to keep the cost down.

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

Note the addition of a slide switch for music 1 vs 2, suggested by Mickey B at Callerlab.  This will prevent callers who are setting up from playing music when there is already a caller calling (yes, I have witnessed this!).

mpogue2, 2024-04-03:
### Wood prices

**Woodcraft** (S2S, 1/2"x3"x24" makes 6 side panels):
- Maple: $14.39
- Bloodwood: $21.79
- Purpleheart: $14.99
- Cherry: $16.79
- Gonzalo Alves: $15.49
- Walnut: $21.99 (about $3.70 each)

**Home Depot** (S4S, 1"x4"x8' times 2 boards):
- Walnut: $109 (makes about 200 side panels, so about $0.50 each))

### Finishes

**Rubio Monocoat** (Pure, 130ml): Amazon $36 (I don't know how much is used per side panel, though, probably not a lot)

mpogue2, 2024-04-06:
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

Fabworks 5052 Al pieces arrived about an hour ago…This is what they look like, with components installed.  These are unfinished, just deburred (checking for fit).

3 of each part, 5052 0.040” Aluminum, $43 and that included shipping.  Order placed Tuesday 4/2 @ 1AM, package arrived Friday 4/5 @ 7PM.  Can’t beat that price or that delivery time.

pkbott, 2024-04-06:
This is looking really goodReady to try something FUN, UNIQUE and ***@***.*** Square Dance Group:  https://www.facebook.com/groups/squaredanceforfun/On Apr 5, 2024, at 11:09 PM, Mike Pogue ***@***.***> wrote:
IMG_4219.jpeg (view on web)
Fabworks 5052 Al pieces arrived about an hour ago…This is what they look like, with components installed.  These are unfinished, just deburred (checking for fit).
3 of each part, 5052 0.040” Aluminum, $43 and that included shipping.  Order placed Tuesday 4/2 @ 1AM, package arrived Friday 4/5 @ 7PM.  Can’t beat that price or that delivery time.

—Reply to this email directly, view it on GitHub, or unsubscribe.You are receiving this because you are subscribed to this thread.Message ID: ***@***.***>

mpogue2, 2024-04-06:
I'm also working on 3D printed side panels, but I really want to make some walnut ones... :-)

mpogue2, 2024-04-06:
Today I also tested using brass threaded inserts into the PLA side panels, as a way to get a tighter screw connection from the front/top/rear/bottom panels into the side panels.

**Notes**:
- Different vendors' inserts needed different hole sizes.
- Inserts on the top require a different hole size (and shape) from inserts on the side of a PLA print.  This is because of the way slicing works -- layers are built up one at a time from bottom up.
- My daughter Amber's threaded inserts had the least squeeze out, and therefore the easiest insertion (no trimming required, took up less space than the threaded inserts I had bought).  I'll try to get a part number for these (box was unbranded).
- All of these results were with Fusion 360 modeling, printed a test block with Black Basic PLA from Bambu.

**Results**:
- For M3xH5.7 screws on the TOP, use a 4.1mm hole.
- For M3xH5.7 screws on the SIDE, use a 3.8mm hole with a teardrop shape (pointy end up, avoids needing supports)
- For M2.5xH6 screws on the TOP, use a 3.3mm hole.
- For M2.5xH6 screws on the SIDE, use a 3.1mm hole.
- For M2xH6 screws on the SIDE, use a 3.0mm hole.
- For all inserts, used a fairly pointy Weller-compatible tip, and 450˚F temperature setting.  I went slow but steady, and did not have a jig (just angled the iron vertically, pushed the insert into the hole, relatively tight fit, and inserted the tip of the iron and pushed straight down slowly, until the head went just under the surface).
- With the right size hole, no trimming was needed.
- I got very weak holes with just 2 loop walls in the slicer (the default).  All the tests above were done with 4 loop walls, which seemed like it resulted in a much stronger and more repeatable part.

Weller tip I used:
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

Amber's inserts:
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

mpogue2, 2024-04-06:
TODO (next version of Aluminum front/top/rear bracket):
- the hole for the LED is a little too big.  Reduce size, or use a plastic.grommet
- the rocker switch is way too loose in the hole.  I think the 0.040" thickness of 5052-Al is probably not the panel thickness this switch is designed for.  Either make the hole smaller, or make 1mm gasket to hold it firmly in place.
- double check for interference with the XLR PCB at front XLR installation time
- consider making the screw holes smaller, since I've now converged on M2.5 screws (instead of M3)

TODO (next version of Aluminum bottom panel):
- the small side needs to be a bit bigger, because the bends took less space away form the top's dimension than expected
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
mpogue2, 2024-05-03:
I got a 20 watt ComMarker B4 fiber laser yesterday, and I ran a couple of tests today.  **There's a clear winner!**

In each case, these are the Ladybug logo (the word "ladybug" is 5.57mm tall), the Model Number (which is 2.5mm tall), the generic name ("PORTABLE MIXER" is 1.5mm tall), and the word "VOLUME" is 3.07mm tall.  In all cases, the laser parameters were:

- 500 mm/sec
- 100% power
- 30KHz frequency
- Fill
- .02 mm line spacing
- 6 passes

Here is that test pattern engraved on Brushed 5052 Aluminum.  This is the best lighting I could do to make it readable.  Many other positions of the light made the light gray color blend into the background, and so the lettering was not legible from all angles!

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

Here is the same engraved on Powder Coated 1018 Steel.  The color of the lettering is grey, so the contrast is not great with the background.  Better than the brushed aluminum, though!

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

Here is same test engraved on Powder Coated 5052 Aluminum.  This one came out nice!  Crisp, clean edges, nice contrast between lettering and background, and readable at all angles.  This is the winner!

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

By the way, in that last picture, if you look at the Material Test over to the left (5x5 matrix of squares), it has letters that are only about 0.5 mm tall!  I can just barely read it without a magnifying glass....this fiber laser marker is pretty amazing!

I have one more test to run here, which is to use the CerMark spray on the Aluminum, and see if I can get dark black lettering.  I could also consider mixing white lettering and black lettering (perhaps for the "bug" part of the logo?)

mpogue2, 2024-05-04:
Did a lot of trial and error with the fiber laser today.  It really likes bolder fonts, and larger fonts.
Thin parts of a glyph don't get really white.  And, the centers of glyphs like "P" and "R" and "A" are
often missing, when the font is small.

After a large number of tries of settings, fonts, and font sizes, I found some combinations that I think will work pretty well.
Hopefully these are the final settings for the fiber laser for this version of the mixer, at least:

Material: 5052-H32 Al with red gloss powder coating, from Fabworks
Settings: 1000/100%/30K/0.02/4 Passes

Font sizes:
- "ladybug": Grayson 7mm
- "MODEL LB-102": Verdana Bold 3.0mm
- "PORTABLE MIXER": Verdana Bold 2.0mm

Result:
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

mpogue2, 2024-05-04:
For the record, at least with the settings I tried, the CerMark test didn't come out all that much better than before with Rich's CO2 laser.  Maybe it needs different settings, but for now, I think the "brushed aluminum" option is tabled.

mpogue2, 2024-05-04:
FYI -- It looks like I can specify a frequency << 20KHz in the Materials Test in Lightburn, and the labels on the resulting set of squares claims to do it.  But, in actuality, this fiber laser can't go below 20KHz.  That explains why all the tiny squares in the image above look about the same.

FYI: Lower KHz frequencies represent more aggressive cutting.

mpogue2, 2024-05-06:
The top of the enclosure is wide enough, that I have to engrave the lettering in 2 passes.  I split into the Left half, and the Right half, and I have "Tool" layers (that don't engrave, they just mark the pot hole locations) to help line up each pass manually.  I decided that I did not need a fancy fixture, just a horizontal plexiglass bar (included with the fiber laser), and a manual slide of the part to horizontally get it to the right position.  I can do something fancier later.

This test plate was powder-coated, but not laser cut, so it has no holes.  It's just for testing the engraving.

Here's how it came out:

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

mpogue2, 2024-05-06:
The bottom panel and side panels are 3D printed right now, using Bambu PLA Matte Black.
Here's what fiber laser (ComMarker B4 w/110mm lens) engraving on the flat bottom panel looks like:

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

It's hard to see in this pic, but the bottom one (2 passes instead of one) has a darker outline, so it's more readable.  However, I do see that this engraving is light-direction-sensitive, so it can be read way better at certain angles, and way worse at others.  Despite that limitation, I think it will be fine for now.

Note: XH = Cross Hatch ON

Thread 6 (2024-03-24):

Feature: PCB for the front XLR connectors

mpogue2, 2024-03-24:
Might make it easier to wire up, at minimal cost.

mpogue2, 2024-04-01:
OK, I designed the PCB for the front XLR Combo jacks.  This will probably save me about 1/2 hour of time per box wiring up the combo jacks (which was a PITA).

Board looks like this (and, JLCPCB can assemble the Neutrik connectors too!):

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

The JST PH connectors are NOT populated in the shipped version.  Will just be stranded wires from those pads to the main PCB, saving a bit of cost.

The price for the connectors is pretty good, too, compared to Full Compass.
**JLCPCB**: $91 FOR 10 boards (including 20 connectors and assembly) and shipping and tax = **$9.10 per board**
**Full Compass components price**: $38 for 20 connectors alone, plus shipping and tax is about $20, so $58 roughly.

And, just for the boards and having _me_ do assembly would be about:
**Full Compass + me doing assembly**: 58 + $4 (5 boards) = **$5.90 per board**

So, the added cost for just the added PCB is about $4/5 = ~$1 per device, but it saves about 1/2 hour of assembly time per device.  Well worth it, I think.

mpogue2, 2024-04-01:
I don't think it's worth it to make a PCB for the output XLR connector, since it's just 3 wires, with no funky wiring between the pins (as is done for the front XLR combo jacks).

mpogue2, 2024-04-05:
Submitted for fabrication and assembly at JLCPCB.  The added cost for assembling them there was pretty minimal.

Therefore, closing this issue.

Closed 2024-04-05.

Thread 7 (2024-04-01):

Problem: JLCPCB is out of the header pins

mpogue2, 2024-04-01:
Can't reorder either of the previous main boards, because of this shortage.  I have plenty of those here, it's just the time it takes to solder them, and the time to remove those pins from the BOM.

mpogue2, 2024-04-05:
They are out of the 2-pin headers, but the 2x2 and the 1x4 headers are still very in-stock.
Designed out the 2-pin headers, and replaced with 0805 0Ω resistors, acting as removable jumpers and test points.

Closed 2024-04-05.

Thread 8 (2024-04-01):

TODO: run battery test on the Tencent lithium 9V battery

mpogue2, 2024-04-01:
Test is running now...I expect it will run for about 2 weeks or so.

mpogue2, 2024-05-09:
Done.  It's about 300 hours.

pkbott, 2024-05-09:
Is this continuous use?Ready to try something FUN, UNIQUE and ***@***.*** Square Dance Group:  https://www.facebook.com/groups/squaredanceforfun/On May 9, 2024, at 5:08 AM, Mike Pogue ***@***.***> wrote:
Done.  It's about 300 hours.

—Reply to this email directly, view it on GitHub, or unsubscribe.You are receiving this because you are subscribed to this thread.Message ID: ***@***.***>

mpogue2, 2024-05-09:
@pkbott Yes.  Here is the graph of my testing, done with 3 different battery technologies.  These were run continuously, while recording the battery voltage every 2 minutes.  I consider a battery "done", when it gets down to 5.5 volts.  The mixer will still run below that voltage, but you'll start to get audio clipping at higher volumes.

This is the reason why I removed the 12V jack (for an external wall-wart style power supply).  When a single alkaline battery lasts 170 hours (that's probably about 50 dances), it doesn't make sense to have to plug it into an outlet.  I worked very hard to keep the power consumption this low, and excellent battery life is the result! :-) :-)

Remember that this is a mixer, and the signal must be sent to a powered speaker (which has the power amplifier inside).
So, the mixer part doesn't actually need much power at all!

I'm also investigating some very inexpensive power amplifiers, perhaps for a future version.  Adding a power amp would definitely require using an external power supply.

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

The horizontal red dashed line is where I declare the battery to be "done".  The horizontal dotted green line is where I start notifying the user of low battery, by starting to blink the LED on the front panel.  The lower the battery voltage, the longer the front panel LED will be OFF.  When the battery gets down to the horizontal dotted red line, the front panel LED is on only 1/10 of the time, indicating that battery should be replaced soon.  The LED won't go lower than off 9/10 + on 1/10 of the time, just to make sure that the user sees that the battery is low.  This is all done in software by the microprocessor, which monitors the battery voltage and controls the LED.

Closed 2024-10-04.

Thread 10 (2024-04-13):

BUGS/FEATURES: Main Mixer Board V2.2

mpogue2, 2024-04-13:
Bugs found (or other changes needed) for the Main Mixer Board V2.2 will be added here in this ticket.

### Bugs:
- **Missing a trace from ground to R72, C49, C50**
  - this wire was accidentally deleted at some point from the PCB (it was obviously there before)
  - it was not discovered, because it appears that I didn't do a final DRC, which DID detect the problem
  - temporary fix (until next PCB spin): solder a small wire between pin 1 (GND) of U8 to the - pin of C49.

### Features or other changes to make:
- **make the order of the wires match the order of the XLR board**, so that wires don't cross (minor)

mpogue2, 2024-10-04:
FIXED in V2.4

Closed 2024-10-04.

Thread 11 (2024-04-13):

FEATURE: bringup progress on Mixer Board V2.2

mpogue2, 2024-04-13:
- **MIC inputs**
  - MIC1 and MIC 2 generate reasonable output with XLR cable [PASS]
  - MIC1 and MIC 2 generate reasonable output with Hilton-compatible cable [PASS]
  - MIC vol and EQ controls work reasonably [PASS]
- **MUSIC inputs**
  - MUSIC1 and MUSIC2 generate reasonable output [PASS]
  - MUSIC vol and EQ controls work reasonably [PASS]
  - can switch between MUSIC1 and MUSIC2 with slide switch [PASS]
- **Output signals**
  - Balanced output to Alto TS-408 works [PASS]
  - 3.5mm output jack signal is reasonable
    - Music L [PASS]
    - Voice R [PASS]
  - very little pop when powering on mixer [PASS]
- **MCU programming**
  - ISP programming works reliably [PASS]
- **Jumpers**
  - MCU can sense the jumpers (J1 and J2) at power-on time, and can decode them correctly [PASS]
- **Remote Volume Control**
  - MCU can sense the remote volume control pot correctly [PARTIAL PASS; design was 0 - 2.5V to ADC3, and I'm getting 0 - 4.7V, possibly the 4.1K resistor is turned on by accident? The math works out for that...It does seem reliable right now, although it might be consuming slightly more power than expected.]
  - LM1971 is installed [YES]
  - MCU can control the LM1971 for remote volume control [PASS]
  - Volume is down at least 60dB in the MUTE state [PASS, 60dB is as low as Audacity can measure]
  - Volume changes are without audible pops [PASS, for regular music and a sine wave]
  - Volume goes to FULL, when there is no Remote Vol Control plugged in [PASS]

mpogue2, 2024-04-14:
TO BE FIXED for next version of the main board:
- add in the GND wire for U8, re-run ground plane update, and re-run DRC
- add a 10µF 6 to 10VDC cap for the Vrefin on the LM1971 (I can prototype this, because I have the caps in 0805 form)

mpogue2, 2024-10-04:
This is all DONE.

Closed 2024-10-04.

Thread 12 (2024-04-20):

FEATURE: next generation feature list

mpogue2, 2024-04-20:
Now that the first generation is almost complete, it's time to start thinking about the second generation mixer design:

### Possible next gen features:
- 4 mic channels (up from 2)
- 4 remote volume controls (up from 1)
- 4 mute controls (up from 0)
- balance and overall gain controls (up from 0)
- USB interface
  - for power
  - for recording/playback to/from a laptop
  - for control of a music player from a bluetooth dongle
- 2 balanced outputs (up from 1; one for the powered speaker, one for connecting to a Williams transmitter)
- 2 LEDs (up from 1)
  - red peak-reading LED
  - white normal peak-reading LED
  - or a VU-meter style LED array
  - or a small bright display
- 32-bit MCU (e.g. STM32)
  - compression/decoding to/from an SD card
- boost power supply (e.g. 9V -> +/-15V) for increased output
- separate Treble/Bass for Mic channels (e.g. concentric pots)

mpogue2, 2024-05-10:
From Ett:
- Is it possible to add-on a USB plug both the USB C the usb traditional rectangular so we can charge our devices while using this mixer? (This idea would require powering from a wall socket...)

mpogue2, 2025-01-04:
NOTES:  STM32G431CBU6 looks pretty good.

- WeAct Studio has a nice module that is about $3.  JLCPCB carries it for a couple of dollars.
- This STM32 is 32-bit, up to 170Mhz, has FPU, has ADC and DAC, lots of GPIO.
- Has [platform.io support](https://github.com/platformio/platform-ststm32/tree/master/examples?utm_source=platformio.org&utm_medium=docs), with several platforms:
    - Arduino
    - CMSIS (which has DSP functions)
    - libopencm3
    - mbed
    - stm32cube
    - Zephyr

mpogue2, 2025-01-04:
### Various STM32 resources

- Tutorial on [setting up CMSIS-DSP in the STM32Cube IDE](https://community.st.com/t5/stm32-mcus/configuring-dsp-libraries-on-stm32cubeide/ta-p/49637).

- Tutorial on [getting started with I2C on STM32](https://wiki.st.com/stm32mcu/wiki/Getting_started_with_I2C#Generate_source_code_and_edit_main-c)

- [Datasheet](https://www.st.com/resource/en/datasheet/stm32g431c6.pdf) on the CPU

- CMSIS [main page](https://arm-software.github.io/CMSIS_5/General/html/index.html), includes RTOS, DSP, etc.

mpogue2, 2025-01-04:
- [Getting Started](https://junctionbyte.com/getting-started-with-stm32cubeide-and-stm32g4/) guide

pkbott, 2025-02-03:
1.  Bluetooth capabilities for cordless usage with computer.
2. Amplified option that is cost effective with passive speakers.

mpogue2, 2025-02-03:
@pkbott What kind of passive (non-powered) speakers do you have?  A lot of callers have Yaks, or Hilton Directors, or Linn-Ron's.

pkbott, 2025-02-03:
Just sold my Director and using a Palmetto Pak from Joe Arnold regularly. Ready to try something FUN, UNIQUE and ***@***.*** Square Dance Group:  https://www.facebook.com/groups/squaredanceforfun/On Feb 3, 2025, at 3:56 AM, Mike Pogue ***@***.***> wrote:
@pkbott What kind of passive (non-powered) speakers do you have?  A lot of callers have Yaks, or Hilton Directors, or Linn-Ron's.

—Reply to this email directly, view it on GitHub, or unsubscribe.You are receiving this because you were mentioned.Message ID: ***@***.***>

mpogue2, 2025-02-05:
Got another vote for a power amplifier, for people wanting to keep their Yaks, but travel lighter than with an MA-220.

Another suggestion was for a three-position switch to be able to play (L, R) or (R, L) or (L+R, L+R).  Cuers might want to reverse the channels, if their software doesn't do it.

Another vote was to remember to do hearing enhancement.  With what I'm thinking, it would be something a little better than what we have now (Music L/Voice R), e.g. a three-position switch that would do (Music L/Voice R) or (Music R/Voice L) or (Music+Voice/Music+Voice).

pkbott, 2025-02-06:
Interesting comment above about making it modular.  I'm not sure how I feel about that but it may work out well.  I just worry about to many components to carry around personally.  I love the idea of a smaller lighter version of the MA-220.  Of course it should be red too!  I also think that maybe having BlueTooth might be a good option for less cords to the computer.

mpogue2, 2025-03-10:
From Parkers:
Be able to connect two units (with more than a 1/8" cable?) to link them.
One rvc per mic.
Make the mic tone controls more like MA (center position is 4dB treble boost and 8dB bass cut)

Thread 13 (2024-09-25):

DOCS: how to build and flash

mpogue2, 2024-09-25:
Output of the BUILD step:

```
 *  Executing task in folder BlinkTest: platformio run

Processing STC8G1K08A (platform: intel_mcs51; board: STC8G1K08A)
-------------------------------------------------------------------------------------------
Verbose mode can be enabled via `-v, --verbose` option
CONFIGURATION: https://docs.platformio.org/page/boards/intel_mcs51/STC8G1K08A.html
PLATFORM: Intel MCS-51 (8051) (2.1.0) > Generic STC8G1K08A
HARDWARE: STC8G1K08A 11MHz, 1.25KB RAM, 8KB Flash
PACKAGES:
 - toolchain-sdcc @ 1.40200.0 (4.2.0)
LDF: Library Dependency Finder -> https://bit.ly/configure-pio-ldf
LDF Modes: Finder ~ chain, Compatibility ~ soft
Found 1 compatible libraries
Scanning dependencies...
Dependency Graph
|-- FwLib_STC8
Building in release mode
Compiling .pio/build/STC8G1K08A/src/main.rel
Compiling .pio/build/STC8G1K08A/liba4a/FwLib_STC8/fw_adc.rel
Compiling .pio/build/STC8G1K08A/liba4a/FwLib_STC8/fw_i2c.rel
Compiling .pio/build/STC8G1K08A/liba4a/FwLib_STC8/fw_mem.rel
Compiling .pio/build/STC8G1K08A/liba4a/FwLib_STC8/fw_spi.rel
Compiling .pio/build/STC8G1K08A/liba4a/FwLib_STC8/fw_sys.rel
Compiling .pio/build/STC8G1K08A/liba4a/FwLib_STC8/fw_tim.rel
Compiling .pio/build/STC8G1K08A/liba4a/FwLib_STC8/fw_uart.rel
Compiling .pio/build/STC8G1K08A/liba4a/FwLib_STC8/fw_usb.rel
Compiling .pio/build/STC8G1K08A/liba4a/FwLib_STC8/fw_util.rel
Archiving .pio/build/STC8G1K08A/liba4a/libFwLib_STC8.lib
Indexing .pio/build/STC8G1K08A/liba4a/libFwLib_STC8.lib
Linking .pio/build/STC8G1K08A/firmware.hex
Checking size .pio/build/STC8G1K08A/firmware.hex
Advanced Memory Usage is available via "PlatformIO Home > Project Inspect"
Flash: [=         ]  13.6% (used 1112 bytes from 8192 bytes)
=============================== [SUCCESS] Took 1.37 seconds ===============================
 *  Terminal will be reused by tasks, press any key to close it.
```

mpogue2, 2024-09-25:
Output of the UPDATE (flash) step:

TBP

mpogue2, 2024-09-25:
Hardware needed:
STC Auto Programmer USB-TTL

```
GROUND: pin 1 on STC programmer goes to ISP connector pin 4 (next to the ISP label)
RxD: pin 3 on STC programmer goes to ISP connector pin 2
TxD: pin 5 on STC programmer goes to ISP connector pin 3 (through a DPST switch)
+5: pin 7 on STC programmer goes to ISP connector pin 1 (through a DPST switch)
```

The DPST switch is needed to interrupt power going to the MCU from the STC programmer, which keeps it in RUN mode, instead of powering up in PROGRAM mode.

To flash:
- Start with those two pins DISCONNECTED/INTERRUPTED
- start the Upload from Visual Studio Code
- flip the switch to CONNECT those 2 pins
- wait 5 seconds for flashing to finish
- NOTE: if there's an LED installed in the board, it will start flashing, telling you that the battery voltage is low, in this case from the STC programmer)
- flip the switch to turn off power to the MCU
- disconnect from the STC programmer.

mpogue2, 2024-09-25:
Setup needed in Visual Studio Code's view of `platformio.ini`
- do `ls -al /dev/tty.usb*` to find the STC programmer's name
- put it into L18 of `platformio.ini`, like this: `upload_port = /dev/tty.usbserial-110`
- hit Save
- Flashing should now work, and won't give you a port error

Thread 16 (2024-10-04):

Feature: Could lower power consumption more (SLEEPY mode messes up ADC)

mpogue2, 2024-10-04:
Symptoms:
- I don't get 0x3X or 0x4X values if SLEEPY mode is on.
- The voltage is higher than I expected (with 20K resistor), get 4.4V instead of 2.5V, as if there's a 4.7K pull-up enabled (there isn't near as I can tell.  Measured with Fluke right across the terminals of the RVC jack.

Turning off SLEEPY mode changes power consumption from 4.4mA to 7.5mA, which decreases battery life from about 130 hrs to about 76 hrs.  But, then the ADC works as expected.  So, I've turned it off for now.

It would be good to fix this to get power consumption back down.

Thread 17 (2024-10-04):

Feature: dynamically find the MAX ADC value

mpogue2, 2024-10-04:
There is a tolerance on the Hilton pot's resistance.  That's gonna shift the zero dB point up and down.
Right now, the algorithm is:

max(min(80 - (ADC/3), 64),0)

The max/min gives us some tolerance for pots that aren't exactly 20K, but maybe we should dynamically see what the actual max is, and always be rescaling to that?

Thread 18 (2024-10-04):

Feature: reprogram without opening the case

mpogue2, 2024-10-04:
Right now it's 8 screws, and a specialized programmer dongle.  It would be nice to be able to reprogram on the fly, without opening the case.

Perhaps USB, or USB + button to get into programming mode (accessible through a small hole?)

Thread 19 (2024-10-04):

Bug: hole in ADC space

mpogue2, 2024-10-04:
Gives us a sudden jump in volume, when in NORMAL (not Left-handed) mode.

Turns out, this is related to SLEEPY mode, which causes the ADC to act really weird.

mpogue2, 2024-10-04:
Fixed by: 73daf3f3223871cb7561f735e8664252fe7807b9

mpogue2, 2024-12-27:
Music output when changing the RVC still not quite as smooth as I would like it to be.

Right now, with the latest version of firmware, a rapid move of the RVC will cause the step size to be between 2 and 3dB, which is more audible than necessary.

**Current firmware:**
- checks every 70ms: a sleepy-like delay of 50ms and worktime of 20ms (no actual CPU sleep time)
- if during the check there is a change of more than 1 step, make all the steps sequentially, separated by 50µs delay.

**OPTION A:**
- check continuously, every ~20ms (zero delay in sleepUntilTimeToWakeup())
- need to readjust battery slot sizes, but that's not a big deal
- PRO: all steps would probably be 1dB, which makes the steps more frequent, and each one would be 1/2 to 1/3 the disruption of the waveform compared to now
- PRO: can't increase battery usage, because we are already running at 100% (due to the SLEEPY problem that messes up the ADC, the 50ms delay in sleepUntilTimeToWakeup() is CPU active time)

**OPTION B:**
- if a volume change is detected, check continuously every ~20ms (zero delay in sleepUntilTimeToWakeup()), until there is no volume change.  Then change 20ms to 50ms.
- need to readjust battery slot sizes, but that's not a big deal
- PRO: almost all steps would probably be 1dB
- CON: first step could be large, if the RVC was moved quickly
- PRO: can't increase battery usage, because we are already running at 100% (due to the SLEEPY problem that messes up the ADC, the 50ms delay in sleepUntilTimeToWakeup() is CPU active time)

**OPTION C:**
- same as OPTION B, but actually put the CPU to sleep when the RVC is not in use (this is non-trivial, due to the ADC problem)
- PROS/CONS: same as OPTION B (still has one potentially-larger step size)
- PRO: lowers power consumption (if we can solve the ADC problem)

For now, OPTION A looks to be the best short-term approach.

**Longer term OPTION D:**
- do all dB changes at a zero crossing (requires a HW change to monitor the music output)
- true CPU sleep
- This option is probably best left for LB-104, which will use a different CPU that has more ADC channels.

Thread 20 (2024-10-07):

Comments from Jubilee

mpogue2, 2024-10-07:
1. Remote Volume Control has about the right sensitivity.
2. Remote Volume Control is too sensitive.
3. RVC goes down all the way to Mute (which Hilton doesn't do) is good.
4. RVC goes down all the way to Mute is not good.  Allows user to have no output, and not know why.
5. Tone control for mics is not exactly like Hilton, seems either muffled or too brassy.
6. It would be nice to have buttons on the mic side to control laptop.
7. Oooh, it's really small!

mpogue2, 2024-10-07:
8. Wouldn't it be nice to have a soft zipper bag for each one?

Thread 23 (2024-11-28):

Bug: need to put 1.5mm hole in middle of PCB for 3.5mm jacks

mpogue2, 2024-11-28:
JLCPCB forgot to do so, so this needs to be done manually.

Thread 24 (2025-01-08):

Bug/feature request: 60Hz pickup with long unused cable

mpogue2, 2025-01-08:
If the music switch is set to Music 1 or 2, and that jack has a cable in it that is NOT plugged into a laptop,
the cable seems to act like an antenna, and it picks up 60Hz noise.  We might be able to do some suppression of this pickup in the next version of Ladybug.

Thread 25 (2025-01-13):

Feature: Cases for Ladybug LB-102

mpogue2, 2025-01-13:
I'm looking at some from Aliexpress:

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

mpogue2, 2025-01-13:
I also really like the idea of Shadow Foam (aka Kaizen Foam, aka Laminated Foam):

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

or

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

mpogue2, 2025-01-13:
Or here:

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

pkbott, 2025-01-13:
Personally, I like a case that has room for a microphone and cable as well as maybe a few extra cables/cords that I might need. The perfect case for me would also hold my laptop so it's all in one.

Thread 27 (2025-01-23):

Shielding technologies for the PLA base

mpogue2, 2025-01-23:
To better shield the base to protect from cell phone interference (e.g. within 6").

Regular PLA base (no shielding): about $2

Copper tape:
- 3" x 275" = $15 => 23 bases = + $0.65/base
- base is 3.25", so need to test whether 3" of coverage helps enough

MG 831WB (water-based) coating:
- 150ml = 5370 cm**2 => 832 in**2 => 21 bases => + $2/base
- can be painted edge-to-edge
- if 2 coats required, + $4/base

Aluminum base:
- Fabworks: + $9 ea

Conductive PLA:
- test: https://www.osti.gov/servlets/purl/1464468
- Cryfokt (1.4 ohm-cm) = $32 for 200gm = 2 bases (minus $2 for unshielded base) = + $14/base

mpogue2, 2025-02-08:
Some results from testing with copper tape (75mm wide, with conductive adhesive):

I ran a bunch of tests with and without Cu foil, and with and without a 4mm gap at front and back.
In my first test I turned the Ladybug upside down, and laid the phone directly on top of it, which seemed to create LOTS of pickup.   In a second test, I tried to maximize the pickup, and found it highest when I held the phone vertically near the Left side.

Below are all relative measurements.

**TEST 1:**
without Cu foil + phone laid directly on bottom = let’s call this our first reference (0dB)
with 75mm foil + phone laid directly on bottom = about 30 dB down from this first reference
with 83mm foil + phone laid directly on bottom = about 30 dB down from this first reference (maybe it’s a bit better than that, hard to tell)

**TEST 2:**
without Cu foil + phone vertical on LHS = let’s call this our second reference (0dB)
with 83mm foil + phone vertical on LHS = about 20dB down from the second reference

CONCLUSIONS:
So, I’d say that Cu foil on the inside of the base gives us “about 20-30dB of attenuation of the cell signal”.

WiFi didn’t seem to be a problem, it was always the reconnect-to-cell-tower that seemed to cause the noise.  I figured this out by turning off Wi-Fi, and putting the iPhone in and out of Airplane Mode.  When it reconnected to the cell tower, I would see noise pickup, which would then calm down after about 10 seconds.

20-30dB measured above represents 3 to 5 doublings of distance.  So, for example, if somebody places their iPhone such that they get pickup at a distance of 12 inches or less WITHOUT Cu foil, they should be able to get as close as (1/8 to 1/32) * 12” = let’s just call it “roughly 1 inch”, before they’ll get the same level of pickup WITH Cu foil.

ACTION:
I'll be adding Cu tape to future 3D printed bases, just to prevent most stray pickup from cell phones.  Most callers won't notice, but there are a few callers who use their cell phone as music player, with a very short cable (say 6"), who will likely hear pickup (depending on where they are relative to their cell towers).

I'll also investigate going to sheet aluminum bases for future designs.

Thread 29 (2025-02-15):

Future: STM32 tests

mpogue2, 2025-02-15:
Test STM32G474CEU6 Core Board (Long version)

- Follow instructions at https://junctionbyte.com/getting-started-with-stm32cubeide-and-stm32g4/
  - Download and Install STM32CUBE IDE on M1 MacBook Air
  - setup clock tree as shown
  - type in Blinky code
  - Build (for debug)
- Follow instructions at https://www.youtube.com/watch?v=VlCYI2U-qyM
  - Download and install STM32 CUBE Programmer
- Download code to Core Board
  - Connect USB C cable, press BOOT0 and RESET, let RESET go, wait 1s, let BOOT0 go (blue LED on solid and dim)
  - Navigate to workspace_1.17.0/BlinkTest1/Debug
  - Open File: BlinkTest1.elf
  - click DOWNLOAD
  - press RESET button on core board
- Expected: blue LED blinks slowly, but when PC13 pressed, blue LED blinks quickly

mpogue2, 2025-02-15:
STM32 Tutorial on DSP/CMSYS/FMAC/etc:

https://www.youtube.com/watch?v=SVT7n7hSzJU

mpogue2, 2025-02-18:
**Test setup:**
- M1 MacBook Air
- UGREEN 4-port USB C Hub (soon)
- Digilent Discovery 3 + Digilent Breadboard Adapter (2ch waveform generator + 2ch scope)
- WeAct Long Type STM32G474CEU6
- ST-Link V2 (automatic download to device + live debugging, unlike the USB connection)
- JSAUX USB C to USB 3.0 Adapter
- STM32CUBEIDE + CMSIS DSP

**Test Software:**
- 1ch ADC @ 44.1KHz -> IIR_LPF(1KHz) -> 1ch DAC @ 44.1KHz
- 170Mhz default CPU clock
- T7 prescaler/counter = 15/257 --> 44.1KHz
- LPF design: https://arachnoid.com/BiQuadDesigner/index.html
- LPF: filter goes direct from ADC -> DAC buffer (not a DC-blocking filter right now)

mpogue2, 2025-02-20:
Dual mode output from DAC1 (this will be used for Music L and Voice R:

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

The blue trace is the RIGHT half of the word (12b R-justified in the RIGHT 16-bit half word), and the orange trace is the LEFT half of the word (12b R-justified in the LEFT 16-bit half word).

This is DAC1 only, no ADC1 input (although that is correctly running in parallel during this test).

mpogue2, 2025-02-21:
Perhaps something like this:

```
static inline float int_to_subnormal(uint32_t val) {
    // Mask to ensure only bottom 12 bits are used (OPTIONAL)
    val &= 0xFFF;

    // Extract whether val >= 2048 into a mask (all 1s or all 0s)
    uint32_t high_mask = -((val >> 11) & 1);

    // For high values (>=2048): we want (val - 2048)
    // For low values (<2048): we want (2047 - val)
    uint32_t mantissa = ((val - 2048) & high_mask) | ((2047 - val) & ~high_mask);

    // Sign bit is 1 for low values, 0 for high values
    uint32_t sign_bit = (~high_mask) & 0x80000000;

    union {
        uint32_t I;
        float f;
    } u;

    u.i = sign_bit | mantissa;

    return u.f;
}
```

I suppose we could also scale it on the way in, to avoid losing precision for small values of the filter coefficients, and we would only lose a cycle or two.  But, only up to 4 bits of shift, otherwise, we might make the converse harder to implement?

And maybe this is the converse:

```
static inline uint16_t subnormal_to_int(float f) {
    union {
        float f;
        uint32_t i;
    } u;
    u.f = f;

    // Extract sign bit and mantissa
    uint32_t sign = u.i >> 31;
    uint32_t mantissa = u.i & 0x7FF;

    // If sign is 1 (negative), output is 2047 - mantissa
    // If sign is 0 (positive), output is mantissa + 2048
    uint32_t result = ((2047 - mantissa) & -sign) | ((mantissa + 2048) & ~-sign);

    return (uint16_t)result;
}
```

mpogue2, 2025-02-21:
And here's a saturating converse, again with bit operations and no branches, so it should be pretty fast.

static inline uint16_t subnormal_to_int(float f) {
    union {
        float f;
        uint32_t i;
    } u;
    u.f = f;

    // Extract sign bit and full mantissa (23 bits)
    uint32_t sign = u.i >> 31;
    uint32_t mantissa = u.i & 0x7FFFFF;

    // Check if mantissa has any bits set beyond bit 11
    // This creates all 1s if any high bits are set, all 0s if not
    uint32_t overflow = -((mantissa & 0x7FFFF800) >> 11);

    // For non-overflow case, use only lower 11 bits of mantissa
    uint32_t normal_result = ((2047 - (mantissa & 0x7FF)) & -sign) |
                            (((mantissa & 0x7FF) + 2048) & ~-sign);

    // Saturate to 4095 for positive overflow, 0 for negative overflow
    uint32_t saturated = (4095 & ~-sign) | (0 & -sign);

    // Select between normal result and saturated value
    uint32_t result = (normal_result & ~overflow) | (saturated & overflow);

    return (uint16_t)result;
}

mpogue2, 2025-02-22:
Time to process 2 channels (1 MIC + 1 MUSIC) of 96 samples (@ 44.1KHz) for subnormal numbers vs regular floats:

| segment | reg float (µs) |      subnormal float (µs)      |
|---------|:--------------:|:------------------------------:|
| 1       |       320      |               110              |
| 2       |       25       |               25               |
| 3       |       25       |               25               |
| 4       |       40       |               40               |
| 5       |       300      |               130              |
| TOTAL   |       710      |               330              |
| Out of  |      2200      |              2200              |
| %CPU    |       33%      | 15% (roughly a doubling of battery life) |

mpogue2, 2025-02-22:
**Binary sizes (128K available):**
- Debug: 40K
- Release (-Os): 30K
- Release (-O3): 32K

mpogue2, 2025-02-23:
Time to process 2 channels (1 MIC + 1 MUSIC) of 96 samples (@ 44.1KHz) for subnormal numbers vs regular floats:

| segment | subn+comb4/5+-O3+forceInline's (µs) |
|:---------|:--------------:|
| 1       |       **20**      |
| 2       |       22       |
| 3       |       22       |
| 4       |       ---       |
| 5       |       **55**      |
| TOTAL   |       120      |
| Out of  |      2200      |
| %CPU    |       5.4% (6X battery life)      |

mpogue2, 2025-02-23:
Example of 2ch input and 2ch output (output shown, stair stepping is due to the DAC having no output filtering):

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

mpogue2, 2025-02-24:
Initial power measurements:
39mA 170Mhz + no sleep
20mA 170Mhz + w/Sleep

Current 170MHz clocks:

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

Timer7 (170MHz clocks):

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

mpogue2, 2025-02-24:
16MHz low power clock:
==> 5.1mA with sleepytime

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

Timer7:
(prescalar: 3) + (counter: 121) = 16 / 3 / 121 = 44077Hz (0.05% off from 44.1KHz)

mpogue2, 2025-02-24:
When putting it to 16MHz or back to 170MHz, I had to flash it a couple of times AND press the NRST button.  Then it worked.

mpogue2, 2025-02-24:
Expanding segment 1 by manually loop unrolling (see below) time for that segment goes up from 18µs to 41µs.

```
#define M1(x) mic_buffer[MIC0][start + x] = int32_to_myfloat(*p++);
#define M2(x) music_buffer[MUSIC0][start + x] = int32_to_myfloat(*p++);
#define M(x) M1(x) M2(x)

	M(0) // ---
	M(1)
	M(2)
	M(3)
	M(4)

```

mpogue2, 2025-02-24:
No savings to partial unrolling:

```
	for (int i = start; i < start + length; i+=2) {
		mic_buffer[MIC0][i] =     int32_to_myfloat(*p++);
		music_buffer[MUSIC0][i] = int32_to_myfloat(*p++);
		mic_buffer[MIC0][i+1] =     int32_to_myfloat(*p++);
		music_buffer[MUSIC0][i+1] = int32_to_myfloat(*p++);
	}

```

mpogue2, 2025-02-24:
This is slower (23µs):

```
	// METHOD C:
	for (int i = start; i < start + length; i++) {
		mic_buffer[MIC0][i] =     int32_to_myfloat(*p);
		p += 2;
	}
	uint32_t *p3 = &adc_buffer[start][1];  // point at very first sample in the block (12bR format) for music
	for (int i = start; i < start + length; i++) {
		music_buffer[MUSIC0][i] = int32_to_myfloat(*p3);
		p3 += 2;
	}

```
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
mpogue2, 2025-03-04:
Can we use PWM channels for the LED's?  I bet we can.  And, I can probably offset their phases, so that we smooth out access to the battery.

mpogue2, 2025-03-04:
Fraction saving for fixed point: https://github.com/ARM-software/CMSIS_5/issues/477

mpogue2, 2025-03-08:
Today I built a pipeline using Qt Creator C++ to simulate what will run on the STM32G474, to make sure that:
- my conversion to and from subnormal floats was working properly, and
- my SVF filter was working properly

**So far:**
- simulates 4X over-sampling (14-bits per sample)
- creates a 384K sample per second chirp, from 20Hz to 20KHz
- runs low and high shelf filters, using subnormal floats (float32_t), and with variable Fcorner and gain
- outputs 12-bits, scaled-to-16-bits-needed-by-WAV to a WAV file, which is then used with an R script to generate a Bode plot

Outputs look like this:

**LOW SHELF**

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

**HIGH SHELF**

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

I am going with SVF so that I can retain stability and correctness while changing the filter parameters in real time (biquads would struggle with that).  Timing is almost identical to a biquad.

mpogue2, 2025-03-08:
**Ideas:**
- I can use the PGA in the STM32 to ensure that we are using the full 16-bits of the ADC, even when the input is at a low level, and we can scale it back at the DAC conversion stage to the 12-bit output required.  This is because I know what the volume pot is set to (it's probably discrete 0.25 or 0.5dB steps), and I know what all the EQ knobs are set to (also probably discrete 0.25 or 0.5dB steps), so I can adjust the PGA gain accordingly by calculation to ensure no clipping.  So, I don't have to use a scale factor of 0.25 all the time, just so that we don't clip with 4 mics active -- with only 1 mic in use, we get full-scale ADC, and with 2/3/4 mics etc.
- And, note that mics that have VOL == 0 don't have to be digitized at all, thereby saving lots of CPU cycles (and increasing battery life).  The 90% case is probably 1 mic.
- I could also do dynamic compression.  Knowing what the max was in the previous 5ms frame, I could reduce the volume to avoid clipping in the next 5ms frame, and make it up at the DAC output stage.  This would benefit distortion, at the expense of some possible surprising effects if the user turns the eq way up, expecting clipping/overload.  Let's say that the bass is turned up way high, which would normally clip.  With this kind of compression, the bass would stop increasing and further turning it up would decrease the treble.

mpogue2, 2025-03-08:
**TODO (Simulator):**
- add noise shaping
- add dither (is this needed?)

**TODO (STM32):**
- live input instead of a chirp
- live pots to control low/high-shelf gains
- live output

mpogue2, 2025-03-09:
Added noise shaping (fraction saving). Cost was 2 SLOC.

I'm gonna skip adding dither for now, because I suspect we have more than 1 LSB of gaussian noise on the ADC side already, which should be equivalent to adding a dither manually.

mpogue2, 2025-03-09:
Hmmm...with 14-bit subnormals and the Cytomic 2021 equations (as well as with the Cytomic 2013 equations), there is some choppiness at very low frequencies:

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

that is not present when floats are used:

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

mpogue2, 2025-03-09:
This "choppiness" goes away when I oversample 16X instead of 4X.

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

So, I'll try to oversample by 16X to get 16-bit samples.  This might require bumping up the clock speed, which will be a tradeoff with battery life.

mpogue2, 2025-03-10:
Added a single pot (B100K: 3V3, GND, wiper to PC4).  At SysClk of 170Mhz, it takes 360ns to sample the pot's value to 12bR.

mpogue2, 2025-03-24:
Tested SVF @ 170MHz, and with a single SVF the processing time is about 53µs.  This is consistent with what I was seeing before @ 16Mhz with biquads.

I tested both High and Low Shelf filters, and they both seem to be working correctly.

But, the updatePotentiometers() is taking a lot longer now, probably because it's setting up the SVF, and that involves taking a square root.  I'll at least optimize so that if the pot value has not changed, we will skip that.

mpogue2, 2025-03-24:
Changed sqrt() to sqrtf() and the time to process the SVF_highShelf() went from 126µs to 116µs.

mpogue2, 2025-03-24:
Should I be using subnormal floats at all, if it takes only a single cycle to convert from uint to float32_t?

mpogue2, 2025-03-24:
Stairstepping at DAC output, need an RC or an RCRC filter:

**RC filter, 10dB per decade**
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

**RCRC filter, 20dB per decade**

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

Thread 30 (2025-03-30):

DAC Reconstruction filter

mpogue2, 2025-03-30:

mpogue2, 2025-03-30:
This is a 3rd order Sallen-Key filter, with fc = 15KHz, gain = 1.0, designed here:
http://sim.okawa-denshi.jp/en/Sallen3tool.php

We might want to move that corner frequency even a little lower, because the attenuation of HF @ 15KHz is only about 1dB (and nobody in our age bracket can hear a 1dB difference @ 15KHz anyway).

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

mpogue2, 2025-03-31:
### I decided to go with a Multiple Feedback LPF.

It's with unity gain because LPFs need 40dB of BW above their gain to function properly.  Therefore because MCP600X has GBW = 1MHz, it has much less than 40dB available at 15KHz, when we use it for 25dB of gain (25dB for Stage 1, 25dB for Stage 2 is what I was shooting for).  So, I might as well use a second MCP600X (same as LB-102) just for gain, and then use a unity gain filter for the ADC filter going into the STM32.

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

### The resulting mic channel looks like this:

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

### And the Bode plot then looks like this:

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

### VOLUME POT FOR THE MIC CHANNEL
NOTE: The volume pot needs to go between Stage 1 and Stage 2, because after stage 2, if there is clipping, the volume control can't be backed off to stop it.  But, between Stage 1 and Stage 2, the signal is about 2mV + 22dB = 2mV * 12.5 = 25mV.  After Stage 2, we have about 25mV + 26dB = 500mV, which is well under the 3V max of the ADC input.

Conversely, if we have a 10mV mic, we end up with 10mV + 48dB = 2.5V swing, which is about the max we can take without clipping.

mpogue2, 2025-03-31:
TODO: Can we stick a PGA on the ADC input from the mic channel?  One more factor of 2 here might be good.

mpogue2, 2025-04-01:
And, here it is with the Mic Volume control added (with an added resistor to approximate log response curve):

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

Current schematic for the Mic Channel:

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

I think I want to pull in the corner frequency a bit, so that suppression of the 44.1KHz steps is higher than now.  This will compromise us a bit at the high end near 20KHz, but nobody can hear that anyway.... :-)

mpogue2, 2025-04-01:
Frequency response of the Sennheiser e945 is about 10dB down at 15KHz, so we can probably afford to cut a lot of the frequencies beyond 15KHz:

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

And, here's what human voices use in terms of frequencies.  Nothing beyond 15KHz is needed:

https://flypaper.soundfly.com/produce/eqing-vocals-whats-happening-in-each-frequency-range-in-the-human-voice/

mpogue2, 2025-04-01:
### ADC Anti-aliasing filter design

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

### Resulting Bode plot, with corner freq pulled way in to 8KHz (approx 3dB BW remaining = 15Hz - 15KHz)

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

### Schematic (QSpice simulator)

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

### Design notes

- Max gain is about 50dB, which is about right: 2mV * 316 = 632mV; 10mV * 316 = 3.16V (clips at 3V)
- It's impossible to clip at the input to the volume control
- Volume control has about 40dB of range, and it's roughly logarithmic (which sounds correct to the ear)
- This is for each Mic channel, so we can detect clipping just by looking at the ADC input (if it hits 0 or 4095).

mpogue2, 2025-04-01:
### Power supplies adjusted to ±1.5v, 10mV sine wave applied, time domain simulation

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

### Time domain plot, clipping expected at higher volume levels

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

mpogue2, 2025-04-01:
#### White noise BEFORE DAC reconstruction filter

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

#### White noise AFTER DAC reconstruction filter (approximately the same Y axis)

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

#### White noise AFTER DAC reconstruction filter (full range Y axis)

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

mpogue2, 2025-04-04:
Choices for the initial buffer amp:

| Part    | uA | noise (nV/sqrt(Hz) | 1st stage SNR (dB vs 2mV mic signal) | GBW (MHz) | Qavail |
| -------- | ------- | -------- | ----- | ----- | --- |
| TLV6741  | 890    | 3.5 | 73 | 10 | 225 |
| TLV9061 | 540     | 10 | 64 | 10 | 18K |
| LMV651  | 120    | 17 | 60 | 12 | 1K |
| MCP6001 | 100  | 28 | 55 | 1.0 | 10K |

Per mic channel current (affects battery life):
- Option A (today): 1 * TLV6741 + 2 * MCP6001 = 890 + 2*100 = 1090uA (72dB SNR)
- Option B: 1 * TLV9061 + 2 * MCP6001 = 740uA (64dB SNR)
- Option C: 1 * LMV651 + 2 * MCP6001 = 320uA (60dB SNR)
- Option C: 3 * MCP6001 = 300uA (55dB SNR)

I think I will stick with the TLV6741 for now, to keep noise low, and I'll live with the decreased battery life compared to the other options.

mpogue2, 2025-10-07:
Yes, as of 10/06/25, it looks like LMV651 + 2 * MCP6001 is still a good choice for mic channel.
Other options looked at:
- LM321 = 100uA, 1.2MHz, 48nV/aqrt(Hz)
- OPA196 = 140uA, 2.5MHz, 15nV/sqrt(Hz)
- OPA837 = 600uA, 50MHz, 4.7nV/sqrt(Hz)

mpogue2, 2025-10-07:
Probably should switch to Butterworth (fc = 18Khz), instead of Bessel (fc = 8Khz).  I chose 8KHz to line up the Bessel with the attenuation of the Butterworth for the higher frequencies.

Pros:
- Butterworth has a much sharper corner, and so has a flatter passband out to 18KHz
- Butterworth heads downward sooner (right at corner frequency) vs Bessel

Cons:
- Butterworth has more of a frequency-dependent phase delay (Bessel is more focused on time domain/phase preservation)

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

Claude:

This reveals a crucial trade-off:
Looking at the graph, you can see that the Bessel (purple) and Butterworth filters now have similar attenuation in the transition region (around 18-30 kHz), BUT:

The Bessel had to be set to 8 kHz - less than half the Butterworth's 18 kHz cutoff
Lost passband: Everything from 8-18 kHz is being attenuated by the Bessel, even though it's still "passband" for the Butterworth
Same stopband attenuation requires sacrifice: To get similar high-frequency rejection, the Bessel gives up a huge chunk of usable bandwidth

Real-world implication: If you need to pass audio up to 18 kHz cleanly while rejecting ultrasonic noise:

Butterworth @ 18kHz: Audio passes cleanly, ultrasonic gets rejected
Bessel @ 8kHz: You'd lose the upper audio range (8-18kHz gets attenuated)
Bessel @ 18kHz: Audio passes with excellent phase, but poor ultrasonic rejection

This is why Bessel filters are chosen when phase linearity matters MORE than frequency selectivity (like video or pulse signals), while Butterworth is preferred when you need good frequency separation (like audio crossovers or anti-aliasing).

mpogue2, 2025-10-07:
```
import React, { useState } from 'react';
import { LineChart, Line, XAxis, YAxis, CartesianGrid, Tooltip, Legend, ResponsiveContainer } from 'recharts';

const RCFilterGraph = () => {
  const [r1, setR1] = useState(884);
  const [c1, setC1] = useState(0.00000001); // 10nF
  const [multiplier, setMultiplier] = useState(10);

  // Calculate frequency response
  const calculateResponse = () => {
    const data = [];

    // Stage values with multiplier scaling
    const r2 = r1 * multiplier;
    const r3 = r2 * multiplier;
    const c2 = c1 / multiplier;
    const c3 = c2 / multiplier;

    // Corner frequencies for each stage
    const fc1 = 1 / (2 * Math.PI * r1 * c1);
    const fc2 = 1 / (2 * Math.PI * r2 * c2);
    const fc3 = 1 / (2 * Math.PI * r3 * c3);

    // For Butterworth, use the same cutoff frequency as the RC filter
    const fcButterworth = fc1;

    // Frequency range from 10 Hz to 100 kHz (logarithmic)
    for (let i = 1; i <= 500; i++) {
      const f = Math.pow(10, 1 + (i / 500) * 4); // 10 Hz to 100 kHz

      // RC Filter Transfer function for each stage: H(jω) = 1 / (1 + jωRC)
      // Magnitude: |H| = 1 / sqrt(1 + (ωRC)²)
      const omega = 2 * Math.PI * f;

      const h1 = 1 / Math.sqrt(1 + Math.pow(omega * r1 * c1, 2));
      const h2 = 1 / Math.sqrt(1 + Math.pow(omega * r2 * c2, 2));
      const h3 = 1 / Math.sqrt(1 + Math.pow(omega * r3 * c3, 2));

      // Total RC response is product of all stages
      const hTotal = h1 * h2 * h3;

      // 3rd-order Butterworth filter response
      // |H(jω)| = 1 / sqrt(1 + (ω/ωc)^(2n)) where n=3
      const omegaC = 2 * Math.PI * fcButterworth;
      const hButterworth = 1 / Math.sqrt(1 + Math.pow(omega / omegaC, 6));

      // 4th-order Butterworth filter response - same cutoff as RC filter
      // |H(jω)| = 1 / sqrt(1 + (ω/ωc)^(2n)) where n=4
      const fcButterworth4 = fc1;
      const omegaC4 = 2 * Math.PI * fcButterworth4;
      const hButterworth4 = 1 / Math.sqrt(1 + Math.pow(omega / omegaC4, 8));

      // 3rd-order Bessel filter response - LOWER cutoff (8 kHz) to match Butterworth transition
      // For 3rd-order Bessel, denominator polynomial: 15 + 15s + 6s² + s³
      // At s = jω, we need to evaluate the magnitude
      const fcBessel = 8000; // 8 kHz - lower than other filters
      const omegaCBessel = 2 * Math.PI * fcBessel;
      const s = omega / omegaCBessel;

      // For s = jω: s² = -ω², s³ = -jω³
      const s2 = -s * s;  // s² becomes negative (imaginary squared)
      const s3 = -s * s * s; // s³ becomes negative imaginary

      // Real part of denominator: 15 + 6s²
      const realPartBessel = 15 + 6 * s2;
      // Imaginary part of denominator: 15s + s³
      const imagPartBessel = 15 * s + s3;

      // Magnitude: |D(jω)| = sqrt(real² + imag²)
      const magSquaredBessel = realPartBessel * realPartBessel + imagPartBessel * imagPartBessel;
      const hBessel = 15 / Math.sqrt(magSquaredBessel);

      // 2nd-order Sallen-Key (unity gain Butterworth) - same cutoff as RC filter
      // This is a single 2nd-order stage, Q = 0.707 (Butterworth)
      // Transfer function: H(s) = ωc² / (s² + √2·ωc·s + ωc²)
      // Magnitude: |H(jω)| = 1 / sqrt((1 - (ω/ωc)²)² + 2(ω/ωc)²)
      const fcSallenKey = fc1;
      const omegaCSK = 2 * Math.PI * fcSallenKey;
      const omegaRatio = omega / omegaCSK;
      const hSallenKey = 1 / Math.sqrt(Math.pow(1 - omegaRatio * omegaRatio, 2) + 2 * omegaRatio * omegaRatio);

      // Convert to dB
      const hTotalDb = 20 * Math.log10(hTotal);
      const h1Db = 20 * Math.log10(h1);
      const h2Db = 20 * Math.log10(h2);
      const h3Db = 20 * Math.log10(h3);
      const hButterworthDb = 20 * Math.log10(hButterworth);
      const hButterworth4Db = 20 * Math.log10(hButterworth4);
      const hBesselDb = 20 * Math.log10(hBessel);
      const hSallenKeyDb = 20 * Math.log10(hSallenKey);

      data.push({
        frequency: f,
        total: hTotalDb,
        butterworth: hButterworthDb,
        butterworth4: hButterworth4Db,
        bessel: hBesselDb,
        sallenkey: hSallenKeyDb,
        stage1: h1Db,
        stage2: h2Db,
        stage3: h3Db,
        fc1: fc1,
        fc2: fc2,
        fc3: fc3
      });
    }

    return data;
  };

  const data = calculateResponse();
  const fc1 = data[0]?.fc1 || 0;
  const fc2 = data[0]?.fc2 || 0;
  const fc3 = data[0]?.fc3 || 0;

  const formatXAxis = (value) => {
    if (value >= 1000) return `${(value / 1000).toFixed(0)}k`;
    return value.toFixed(0);
  };

  // Generate X-axis tick values: 10k, 20k, 30k, ..., 100k
  const generateXTicks = () => {
    const ticks = [];
    for (let i = 10000; i <= 100000; i += 10000) {
      ticks.push(i);
    }
    return ticks;
  };

  const xAxisTicks = generateXTicks();
  const yAxisTicks = [-80, -75, -70, -65, -60, -55, -50, -45, -40, -35, -30, -25, -20, -15, -10, -5, 0, 5];

  return (
    <div className="w-full h-full p-6 bg-gray-50">
      <div className="bg-white rounded-lg shadow-lg p-6">
        <h2 className="text-2xl font-bold mb-4 text-gray-800">3-Stage Cascaded RC Low-Pass Filter</h2>
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

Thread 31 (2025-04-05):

LEDs

mpogue2, 2025-04-05:
### Brightness
With both 5mm and kybd LEDs, they seem to be plenty bright when driven by 3v3 with 2.2K ohm resistors.  They are plenty bright, and can probably be further dimmed down further with PWM.

### Evenness of illumination
The 5mm RGB LEDs are OK for displaying a single at a time, but with more than 1 active LED color, the dome is not evenly illuminated.  You can't see this in a photograph of the LED, but it's clearly visible to the human eye.  It's kind of an interesting rainbow effect, but that's not what I'm looking for here.

The domes of the "mechanical keyboard LEDs" appear to be fairly evenly illuminated, no matter which LEDs are on.

### Current consumption
Both 5mm and kybd LEDs draw about 0.5mA per color.  The 5mm are marked 2-2.2V (R), 3-3.2V (B/G) @ 20mA, and I suspect that the same die are used in the kybd LEDs.  0.5mA * 2.2K = about 1.1V, so with 2.2K resistors we're driving R/G/B all at about 2.1V.

### Mechanical considerations
The kybd LEDs are 3mm (vs the 5mm LEDs above), so they will take up less space than the 5mm.

Only disadvantage of the kybd LEDs (that I can think of) is that they appear to be designed to sit in pairs right next to each other and so each dome has a tiny flat spot on one side. The flat spot is not very visible from the top of the powder-coated Ladybug LB-102 enclosure when I tried it.  But, the current power LED hole is just a tiny bit too small for the dome to be seated all the way.  The current power LED hole is 3.2mm.  So, for the Mechanical Kybd LEDs we should try 3.3mm.

mpogue2, 2025-04-08:
Charlieplexing (https://en.wikipedia.org/wiki/Charlieplexing) can reduce the number of pins needed and the number of traces, but at the cost of not being able to use the STM32's PWM drivers.

However, PWM on the STM32G431 is only 8 channels max, so we could not assign one PWM channel per LED anyway, even if we went down to 2 LEDs per channel (R and G).

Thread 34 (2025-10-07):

NEXT GEN: Bass suppression for some powered speakers

mpogue2, 2025-10-07:
Kip suggests:

- Since Ladybug is used with a lot of powered speakers that have TOO MUCH BASS, provide a way
to suppress that:
  - for example, tilt both Music and Voice channels away from the bass

This might be better done with the DSP approach, which won't be in LB-202, but might be in LB-204.

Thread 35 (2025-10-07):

NEXT GEN: lower aluminum section of enclosure

mpogue2, 2025-10-07:
How to make prototype enclosures out of 0.032 chipboard.  Good!

https://www.youtube.com/watch?v=kMjmMJSLYhk

We might do something like this to increase shielding.

mpogue2, 2025-10-07:
Source for chipboard:

- https://www.amazon.com/Craftelier-Chipboard-Thickness-Lignin-Free-Scrapbooking/dp/B0DKXTKK6F
- $20 for 50 12x12" (304x304mm) sheets, 1mm thick

NOTE: LB-102 sheet metal size: 182x140mm = 7.2"H x 5.5"W

So a base or a top should be doable with a single 12x12" sheet of chipboard.
Using 1mm thick chipboard is the same thickness as the actual aluminum enclosure for LB-102.

We can use this to prototype LB-104, too.  Each additional microphone channel adds 25mm to the 140mm number.
So, LB-104 sheet metal will be (approximately) aluminum 0.040" (1mm) 182 x 190mm = 7.2"H x 7.5" wide, which fits on a 12x12" chipboard sheet.

mpogue2, 2025-10-07:
GOOD U-shaped enclosure (exactly what we need): https://www.youtube.com/watch?v=aYnfChI_G9g

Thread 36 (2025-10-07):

NEXT GEN: Non-DSP solution

mpogue2, 2025-10-07:
<head></head><p style="caret-color: rgb(0, 0, 0); color: rgb(0, 0, 0); font-style: normal; font-variant-caps: normal; font-weight: 400; letter-spacing: normal; orphans: auto; text-align: start; text-indent: 0px; text-transform: none; white-space: normal; widows: auto; word-spacing: 0px; -webkit-text-stroke-width: 0px; text-decoration: none;">Ah! Now I understand! You're using the TLV6741 in a<span class="Apple-converted-space"> </span><strong>differential amplifier configuration</strong><span class="Apple-converted-space"> </span>with the RC HPF integrated into the feedback network. That's clever!</p><p style="caret-color: rgb(0, 0, 0); color: rgb(0, 0, 0); font-style: normal; font-variant-caps: normal; font-weight: 400; letter-spacing: normal; orphans: auto; text-align: start; text-indent: 0px; text-transform: none; white-space: normal; widows: auto; word-spacing: 0px; -webkit-text-stroke-width: 0px; text-decoration: none;">Let me address this properly:</p><hr style="font-style: normal; font-variant-caps: normal; font-weight: 400; letter-spacing: normal; orphans: auto; text-align: start; text-indent: 0px; text-transform: none; white-space: normal; widows: auto; word-spacing: 0px; -webkit-text-stroke-width: 0px; text-decoration: none;"><h2 style="caret-color: rgb(0, 0, 0); color: rgb(0, 0, 0); font-style: normal; font-variant-caps: normal; letter-spacing: normal; orphans: auto; text-align: start; text-indent: 0px; text-transform: none; white-space: normal; widows: auto; word-spacing: 0px; -webkit-text-stroke-width: 0px; text-decoration: none;"><strong>Understanding Your Current Design:</strong></h2><p style="caret-color: rgb(0, 0, 0); color: rgb(0, 0, 0); font-style: normal; font-variant-caps: normal; font-weight: 400; letter-spacing: normal; orphans: auto; text-align: start; text-indent: 0px; text-transform: none; white-space: normal; widows: auto; word-spacing: 0px; -webkit-text-stroke-width: 0px; text-decoration: none;"><strong>You have a single TLV6741 configured as:</strong></p><ul style="caret-color: rgb(0, 0, 0); color: rgb(0, 0, 0); font-style: normal; font-variant-caps: normal; font-weight: 400; letter-spacing: normal; orphans: auto; text-align: start; text-indent: 0px; text-transform: none; white-space: normal; widows: auto; word-spacing: 0px; -webkit-text-stroke-width: 0px; text-decoration: none;"><li>Differential amplifier (balanced input)</li><li>With RC high-pass filtering in the feedback</li><li>+17 dB gain</li><li>All in ONE op-amp!</li></ul><p style="caret-color: rgb(0, 0, 0); color: rgb(0, 0, 0); font-style: normal; font-variant-caps: normal; font-weight: 400; letter-spacing: normal; orphans: auto; text-align: start; text-indent: 0px; text-transform: none; white-space: normal; widows: auto; word-spacing: 0px; -webkit-text-stroke-width: 0px; text-decoration: none;"><strong>This is possible and common!</strong></p><hr style="font-style: normal; font-variant-caps: normal; font-weight: 400; letter-spacing: normal; orphans: auto; text-align: start; text-indent: 0px; text-transform: none; white-space: normal; widows: auto; word-spacing: 0px; -webkit-text-stroke-width: 0px; text-decoration: none;"><h2 style="caret-color: rgb(0, 0, 0); color: rgb(0, 0, 0); font-style: normal; font-variant-caps: normal; letter-spacing: normal; orphans: auto; text-align: start; text-indent: 0px; text-transform: none; white-space: normal; widows: auto; word-spacing: 0px; -webkit-text-stroke-width: 0px; text-decoration: none;"><strong>The Problem: 2nd-Order HPF with Differential Amp</strong></h2><p style="caret-color: rgb(0, 0, 0); color: rgb(0, 0, 0); font-style: normal; font-variant-caps: normal; font-weight: 400; letter-spacing: normal; orphans: auto; text-align: start; text-indent: 0px; text-transform: none; white-space: normal; widows: auto; word-spacing: 0px; -webkit-text-stroke-width: 0px; text-decoration: none;"><strong>You're right - this is NOT straightforward!</strong></p><p style="caret-color: rgb(0, 0, 0); color: rgb(0, 0, 0); font-style: normal; font-variant-caps: normal; font-weight: 400; letter-spacing: normal; orphans: auto; text-align: start; text-indent: 0px; text-transform: none; white-space: normal; widows: auto; word-spacing: 0px; -webkit-text-stroke-width: 0px; text-decoration: none;"><strong>Standard Sallen-Key requires:</strong></p><ul style="caret-color: rgb(0, 0, 0); color: rgb(0, 0, 0); font-style: normal; font-variant-caps: normal; font-weight: 400; letter-spacing: normal; orphans: auto; text-align: start; text-indent: 0px; text-transform: none; white-space: normal; widows: auto; word-spacing: 0px; -webkit-text-stroke-width: 0px; text-decoration: none;"><li>Two op-amps (or complex single-stage topology)</li><li>Single-ended input</li><li>Doesn't integrate well with differential configuration</li></ul><p style="caret-color: rgb(0, 0, 0); color: rgb(0, 0, 0); font-style: normal; font-variant-caps: normal; font-weight: 400; letter-spacing: normal; orphans: auto; text-align: start; text-indent: 0px; text-transform: none; white-space: normal; widows: auto; word-spacing: 0px; -webkit-text-stroke-width: 0px; text-decoration: none;"><strong>Options for balanced 2nd-order HPF:</strong></p><h3 style="caret-color: rgb(0, 0, 0); color: rgb(0, 0, 0); font-style: normal; font-variant-caps: normal; letter-spacing: normal; orphans: auto; text-align: start; text-indent: 0px; text-transform: none; white-space: normal; widows: auto; word-spacing: 0px; -webkit-text-stroke-width: 0px; text-decoration: none;"><strong>Option A: Accept 1st-Order RC (Your Current Design)</strong></h3><pre style="caret-color: rgb(0, 0, 0); color: rgb(0, 0, 0); font-style: normal; font-variant-caps: normal; font-weight: 400; letter-spacing: normal; orphans: auto; text-align: start; text-indent: 0px; text-transform: none; widows: auto; word-spacing: 0px; -webkit-text-stroke-width: 0px; text-decoration: none;"><code>Balanced XLR → [TLV6741 Differential + RC HPF, +17dB] → Stage 2

Pros:
✅ One op-amp (PCB space limited!)
✅ True balanced input
✅ Excellent noise (3.5 nV/√Hz)
✅ Simple, works great
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

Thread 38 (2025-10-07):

NEXT GEN: Design for Manufacturability

mpogue2, 2025-10-07:
It was about 4 hours per device of my time in Batch #1.  Gotta get that down to 1/2 hour per device MAX.

- use DTP UV printing instead of laser engraving for the enclosure (it's multi-color, too!)
- sides 3D printed should be smaller, if the underside is now aluminum
- Fewer screws for the enclosure (8 -> 6)
- Use 3-pin JST-SH everywhere, instead of soldering all those tiny boards and stripping and soldering all those tiny wires
- Maybe replace the slide switch with a push button switch + 2 LEDs, and have a small board to hold them all?

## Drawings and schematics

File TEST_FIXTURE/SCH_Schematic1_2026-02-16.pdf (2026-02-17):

# MUS 1 OUT

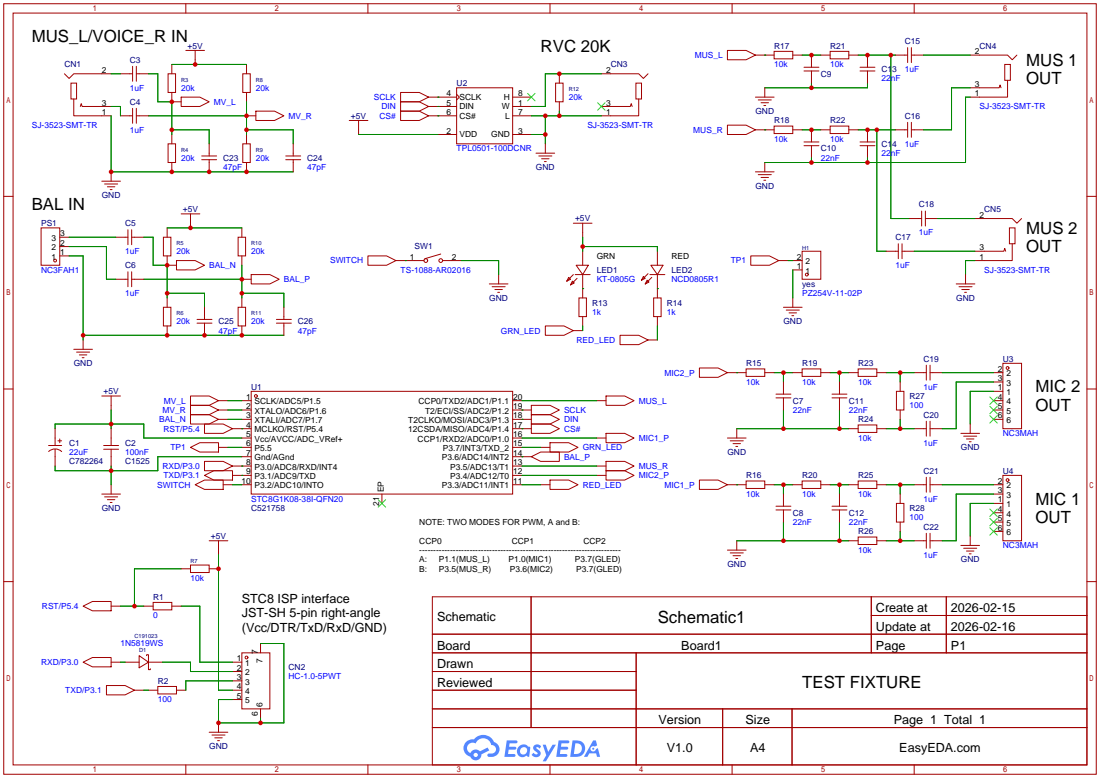
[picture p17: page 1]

NOTE: TWO MODES FOR PWM, A and B:

STC8 ISP interface
JST-SH 5-pin right-angle
(Vcc/DTR/TxD/RxD/GND)

Schematic | Schematic1 | Create at | 2026-02-15

Update at | 2026-02-16

Board | Board1 | Page | P1

Version | Size | Page 1 Total 1
V1.0 | A4 | EasyEDA.com

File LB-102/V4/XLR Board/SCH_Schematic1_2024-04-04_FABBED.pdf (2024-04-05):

# XLR wiring PCB

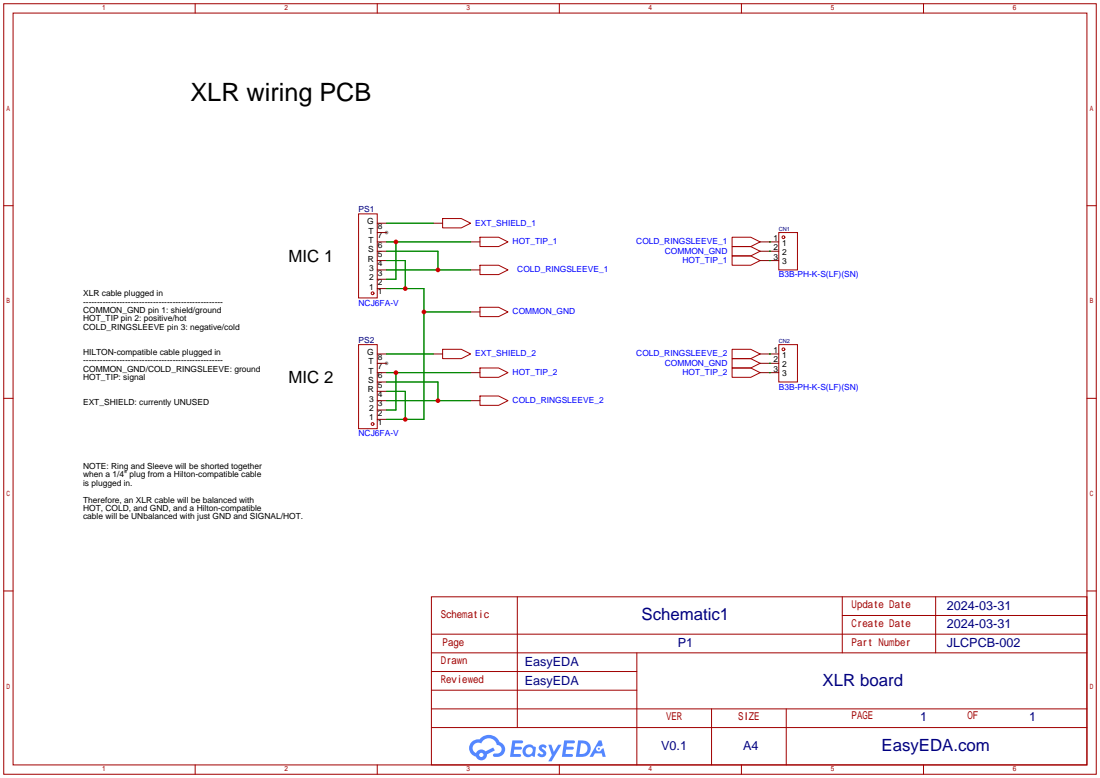
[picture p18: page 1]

XLR cable plugged in
COMMON_GND pin 1: shield/ground
HOT_TIP pin 2: positive/hot
COLD_RINGSLEEVE pin 3: negative/cold

NOTE: Ring and Sleeve will be shorted together
when a 1/4" plug from a Hilton-compatible cable
is plugged in.
Therefore, an XLR cable will be balanced with
HOT, COLD, and GND, and a Hilton-compatible
cable will be UNbalanced with just GND and SIGNAL/HOT.

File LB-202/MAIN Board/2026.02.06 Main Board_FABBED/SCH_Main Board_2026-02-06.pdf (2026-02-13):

# Microphone preamp, Mic #1

# Single "Tilt" (+/-16dB) with pre-tilt

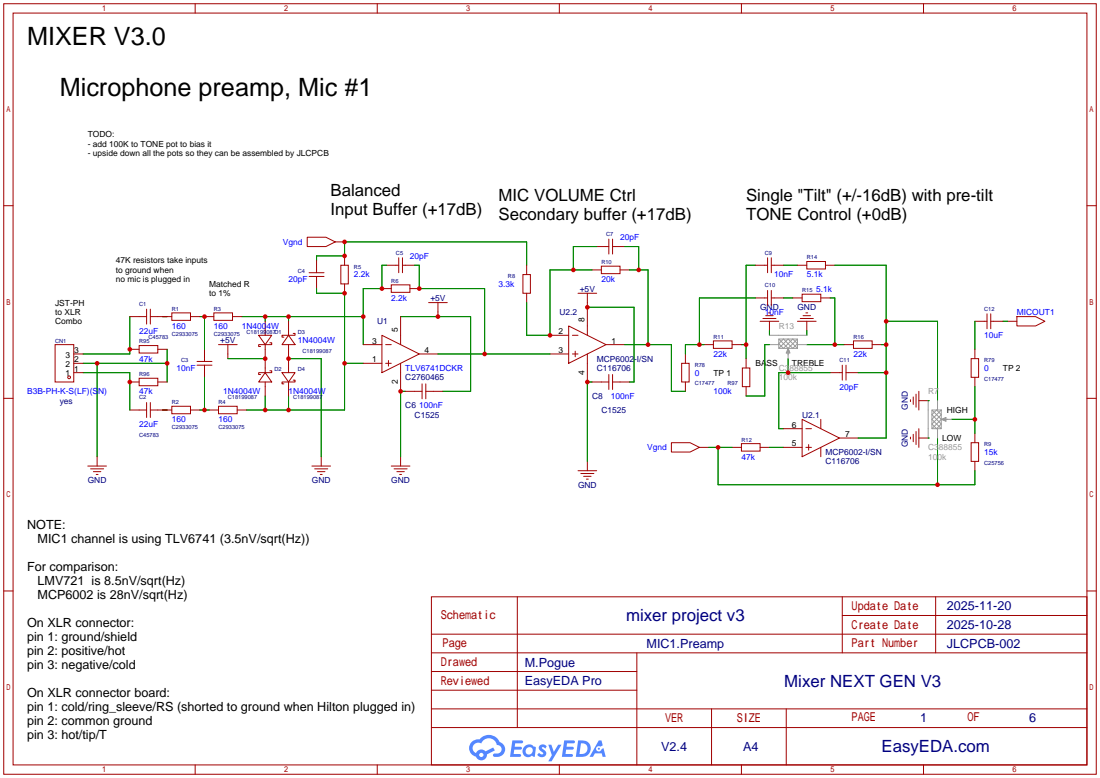
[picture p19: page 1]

TODO:
- add 100K to TONE pot to bias it
- upside down all the pots so they can be assembled by JLCPCB

47K resistors take inputs
to ground when
no mic is plugged in

NOTE:
MIC1 channel is using TLV6741 (3.5nV/sqrt(Hz))
For comparison:
LMV721 is 8.5nV/sqrt(Hz)
MCP6002 is 28nV/sqrt(Hz)
On XLR connector:
pin 1: ground/shield
pin 2: positive/hot
pin 3: negative/cold
On XLR connector board:
pin 1: cold/ring_sleeve/RS (shorted to ground when Hilton plugged in)
pin 2: common ground
pin 3: hot/tip/T

# Microphone preamp, Mic #2

# MIC VOLUME Ctrl

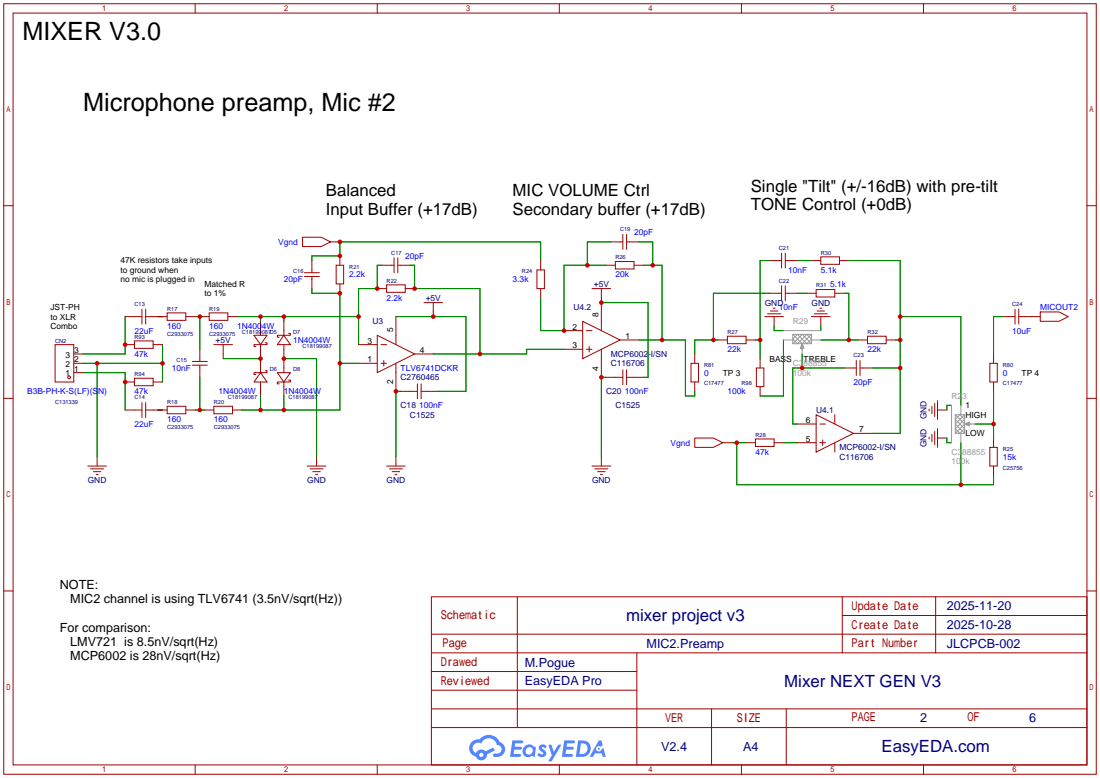
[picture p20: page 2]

Single "Tilt" (+/-16dB) with pre-tilt
TONE Control (+0dB)

47K resistors take inputs
to ground when
no mic is plugged in

NOTE:
MIC2 channel is using TLV6741 (3.5nV/sqrt(Hz))
For comparison:
LMV721 is 8.5nV/sqrt(Hz)
MCP6002 is 28nV/sqrt(Hz)

# Music Mixer/Preamp/Remote Vol/Main Vol Control

(source: https://www.ti.com/lit/ug/tidu034/tidu034.pdf, https://sound-au.com/project01.htm,

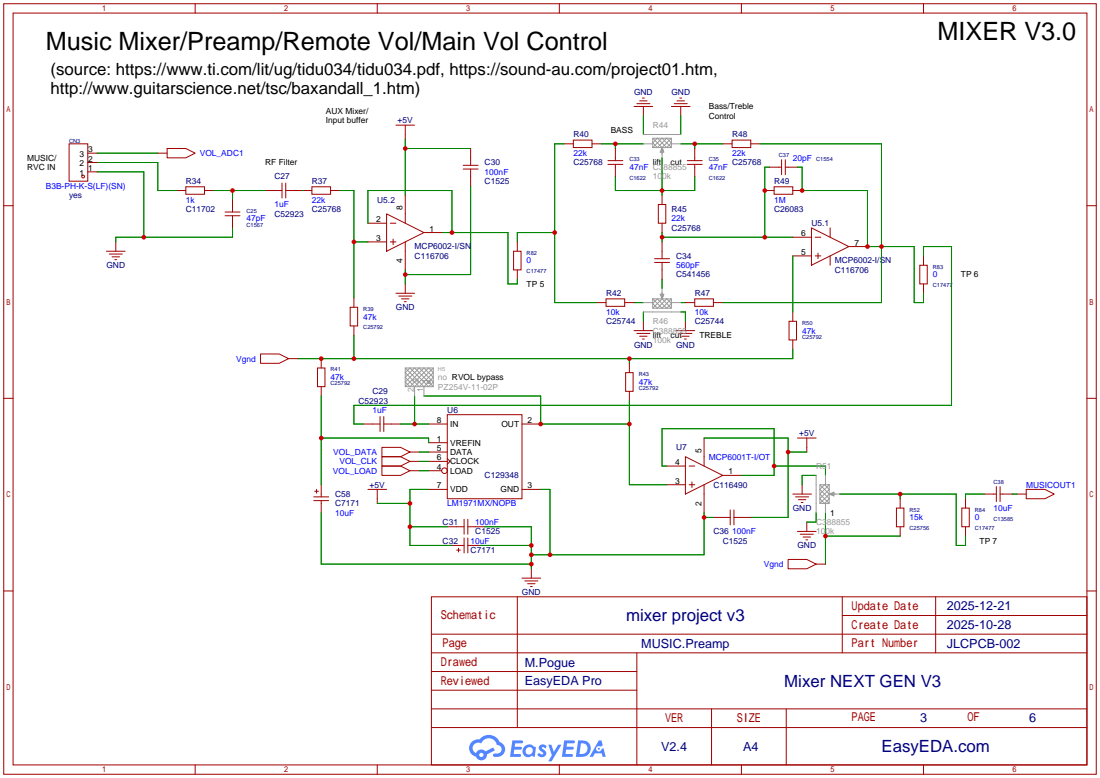
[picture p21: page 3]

http://www.guitarscience.net/tsc/baxandall_1.htm)

# Final Mixer/Balanced output driver

# Voice/Music Mixer Voice Mixer &

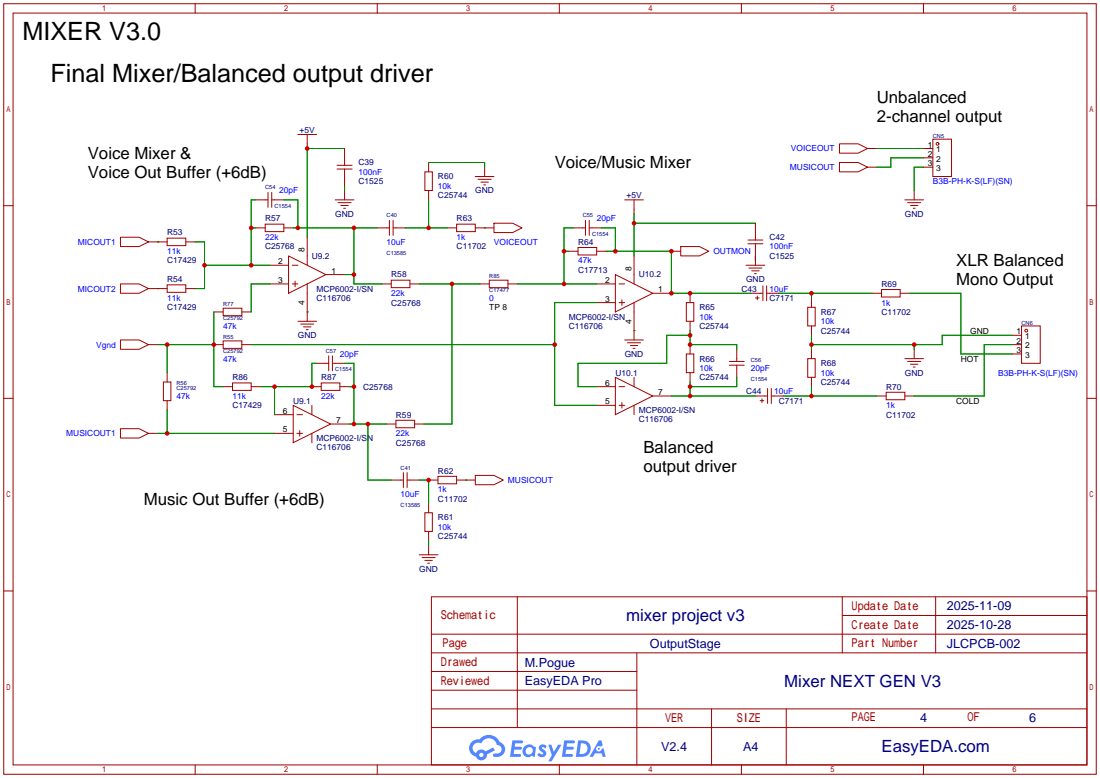
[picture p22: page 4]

# Input Power Management

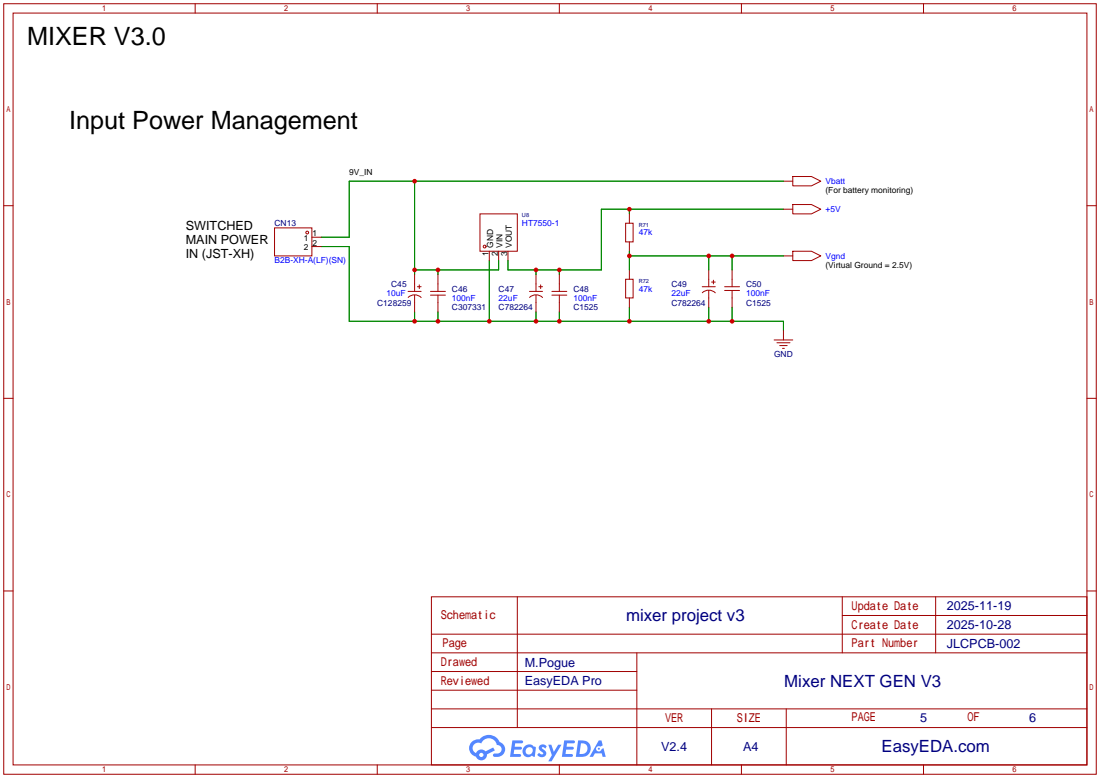
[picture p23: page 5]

# MCU (Battery Monitor, Remote Vol Ctrl)

## Battery

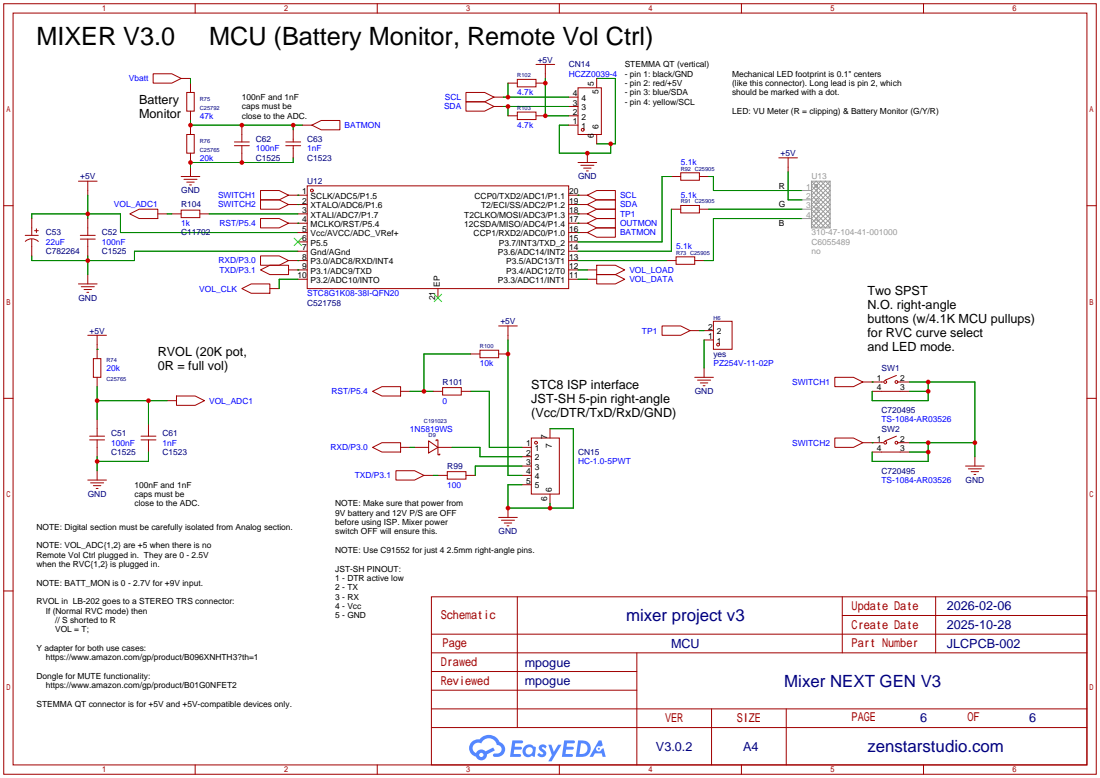
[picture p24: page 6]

Mechanical LED footprint is 0.1" centers
(like this connector). Long lead is pin 2, which
should be marked with a dot.
LED: VU Meter (R = clipping) & Battery Monitor (G/Y/R)

100nF and 1nF
caps must be
close to the ADC.

Two SPST
N.O. right-angle
buttons (w/4.1K MCU pullups)
for RVC curve select
and LED mode.

STC8 ISP interface
JST-SH 5-pin right-angle
(Vcc/DTR/TxD/RxD/GND)

NOTE: Make sure that power from
9V battery and 12V P/S are OFF
before using ISP. Mixer power
switch OFF will ensure this.
NOTE: Use C91552 for just 4 2.5mm right-angle pins.
JST-SH PINOUT:
1 - DTR active low
4 - Vcc
5 - GND

NOTE: Digital section must be carefully isolated from Analog section.
NOTE: VOL_ADC{1,2} are +5 when there is no
Remote Vol Ctrl plugged in. They are 0 - 2.5V
when the RVC{1,2} is plugged in.
NOTE: BATT_MON is 0 - 2.7V for +9V input.
RVOL in LB-202 goes to a STEREO TRS connector:
If (Normal RVC mode) then
// S shorted to R
VOL = T;
Y adapter for both use cases:
https://www.amazon.com/gp/product/B096XNHTH3?th=1
Dongle for MUTE functionality:
https://www.amazon.com/gp/product/B01G0NFET2
STEMMA QT connector is for +5V and +5V-compatible devices only.

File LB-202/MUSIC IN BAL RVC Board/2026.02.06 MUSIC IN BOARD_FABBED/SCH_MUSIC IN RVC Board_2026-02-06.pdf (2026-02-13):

# MUSIC IN

V3.0

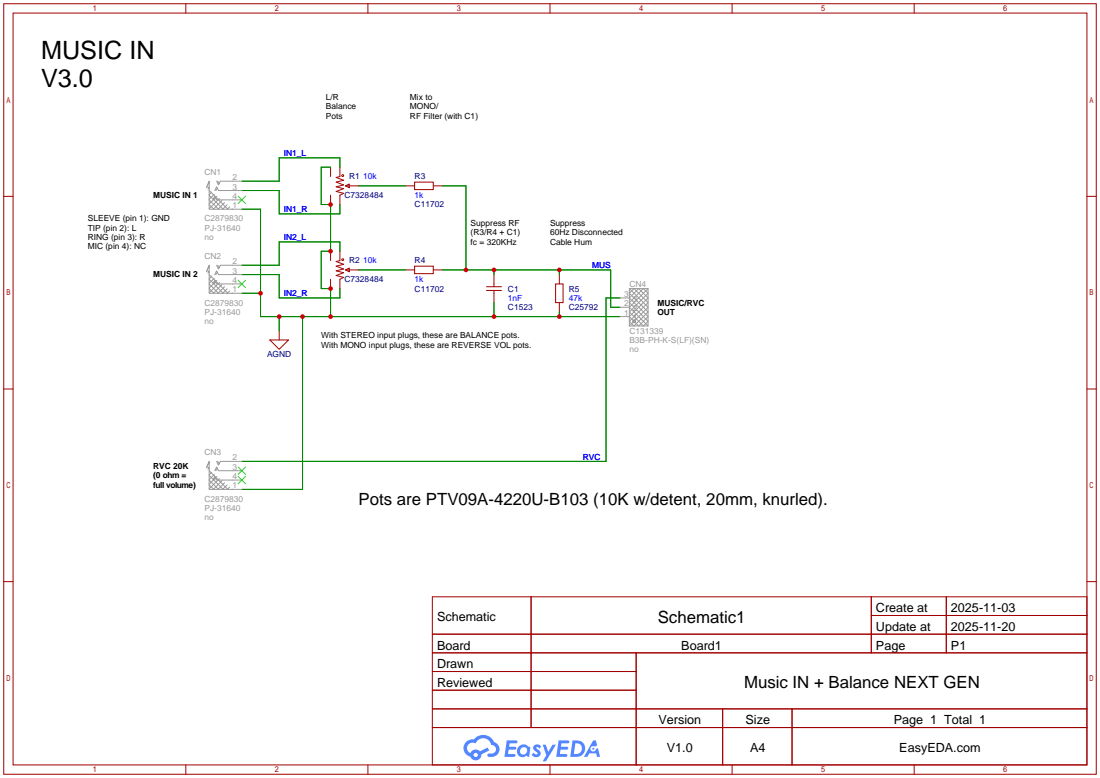
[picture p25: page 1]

With STEREO input plugs, these are BALANCE pots.
With MONO input plugs, these are REVERSE VOL pots.

Pots are PTV09A-4220U-B103 (10K w/detent, 20mm, knurled).

Schematic | Schematic1 | Create at | 2025-11-03

Update at | 2025-11-20

Board | Board1 | Page | P1
Drawn | | Music IN + Balance NEXT GEN
Reviewed

Version | Size | Page 1 Total 1
V1.0 | A4 | EasyEDA.com

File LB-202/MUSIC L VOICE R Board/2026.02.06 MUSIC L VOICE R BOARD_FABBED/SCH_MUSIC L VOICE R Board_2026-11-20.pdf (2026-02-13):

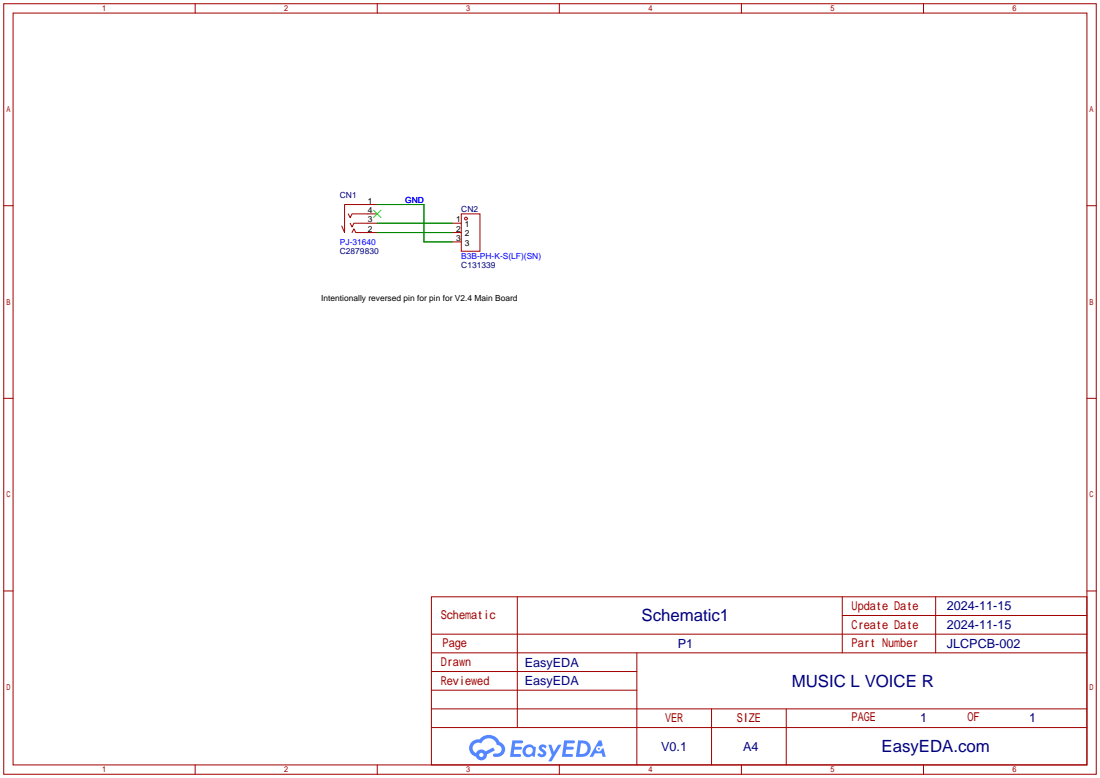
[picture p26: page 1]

Intentionally reversed pin for pin for V2.4 Main Board

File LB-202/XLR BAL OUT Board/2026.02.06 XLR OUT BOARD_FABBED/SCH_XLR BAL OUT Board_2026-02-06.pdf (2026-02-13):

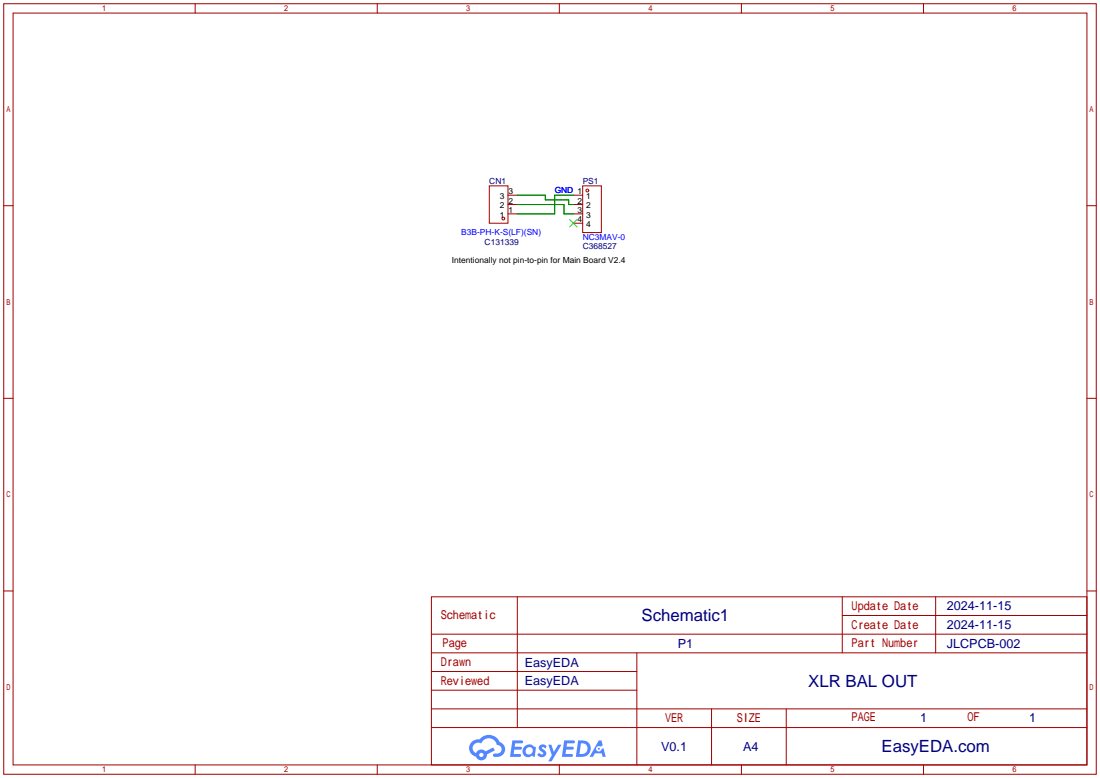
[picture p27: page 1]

Intentionally not pin-to-pin for Main Board V2.4

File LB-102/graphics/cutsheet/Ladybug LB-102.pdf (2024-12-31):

Ladybug LB-102 PORTABLE MIXER

The Ladybug LB-102 Mixer is an inexpensive (about $100), compact audio mixer, focused on the needs of beginning and intermediate square dance callers. It works with all powered speakers (those that have a built-in amplifier).
Add a dynamic microphone ($80), 2 XLR cables ($10 ea.), and an Alto TX308 powered speaker (350W, $120), to can provide high-quality sound for up to 4 squares for about $225. Or, swap in an Alto TS408

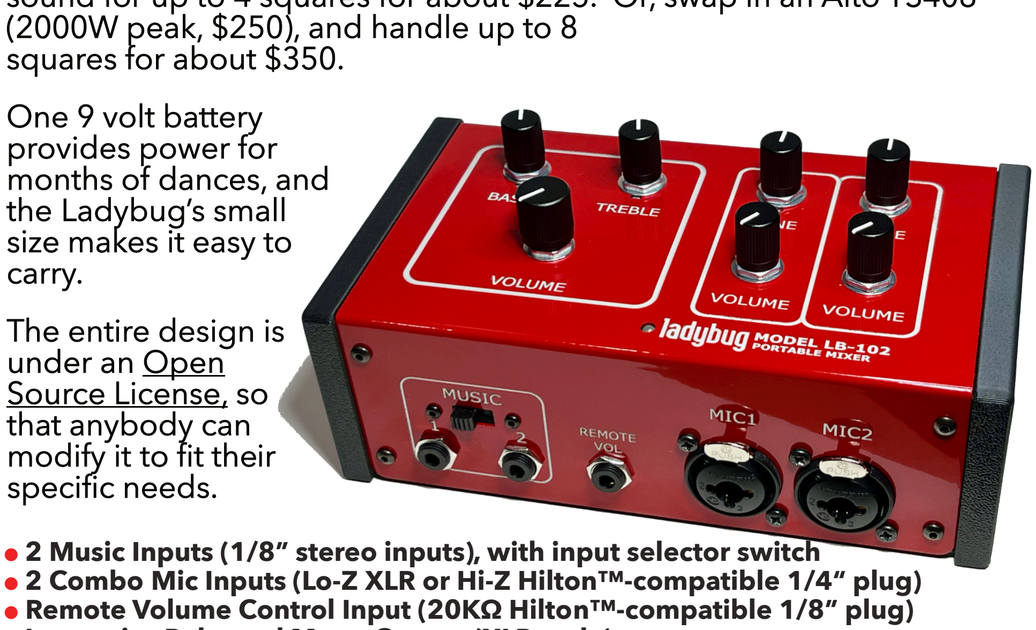
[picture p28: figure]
(2000W peak, $250), and handle up to 8 squares for about $350. One 9 volt battery provides power for months of dances, and the Ladybug’s small size makes it easy to carry. The entire design is under an Open Source License, so that anybody can modify it to fit their specific needs.

- 2 Music Inputs (1/8” stereo inputs), with input selector switch
- 2 Combo Mic Inputs (Lo-Z XLR or Hi-Z Hilton™-compatible 1/4“ plug)
- Remote Volume Control Input (20KΩ Hilton™-compatible 1/8” plug)
- Low-noise Balanced Mono Output (XLR male)
- Separate Music (L) and Voice (R) out (1/8” stereo jack)
- Music-only for a monitor speaker, or use Voice-only for hearing assist
- Uses a single 9V battery
- Amazon Basics Alkaline ($1.50): about 90 hours, OR
- Tenergy Lithium ($6.50): about 150 hours
- Low noise: -80dBfs
- Wide 3dB Bandwidth: Music 20Hz-20KHz, Voice 50Hz-20KHz
- Small size: 6.9”W x 2.5”H x 3.75”D (175 x 65 x 95 mm)
- Light weight (with battery): 12.5oz (355g)
- Open Source Hardware, Software, and Mechanical Design

https://github.com/mpogue2/ladybug-mixer

Follow the project progress at:

V1.2

## Typical 2-caller setup for large hall

Hiltontm Mic Cable; XLR; 3.5mm stereo audio cable; Dynamic microphone #1; Laptop computer #1; FRONT; TOP; REAR; Laptop computer #2; Dynamic microphone #2; Standard XLR Mic Cable; Ladybug LB-102 Mixer; XLR Female; XLR Male

one XLR mic cable + one Hiltontm-compatible mic cable
TS408 powered speaker (2000W peak output)

Standard XLR Mic Cable


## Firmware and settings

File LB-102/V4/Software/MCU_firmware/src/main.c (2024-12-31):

// +-----------------------------------------------+
// | BLINKTEST: Firmware for Mixer Board V2.4      |
// |                                               |
// | Copyright (c) 2024, Michael Pogue             |
// | License: GPL V3                               |
// +-----------------------------------------------+

#include <stdbool.h>
#include <stdint.h>
#include <stdio.h>

#include "fw_hal.h"

// GLOBALS =============================
int LEDCounter = 0;

uint8_t firmwareMajorVersion = 1; // NOTE: Increments infrequently
uint8_t firmwareMinorVersion = 2; // NOTE: Increments every new version

uint8_t jumperADC = 0;
bool    jumperJ1_IN = false; // if IN, then REVERSE DIRECTION on Remote Volume Ctrl
bool    jumperJ2_IN = false; // unassigned right now

uint8_t res = 0;          // attenuation result
uint8_t previousRes = 0;  // previous attenuation result

// SLEEPY: minimize power, but doesn't allow automatic Upload from programmer @ CTL-OPT-U time
// NOTE: Sleepy currently messes up the ADC, so turning it OFF for now
//#define SLEEPY 1

// DEBUG_OUTPUT: enable UART, uses power and cpu cycles, but easier to debug
//  On Mac, use SerialTools set to usbserial-110 (or similar), 115200/8/N/1.
//  NOTE: we have to click Disconnect in SerialTools before we can program the MCU via ISP.
// #define DEBUG_OUTPUT

// ==========================================================
// UTILS ================================
#define nop() __asm__(" nop");

// ==========================================================
// JUMPER READ AT POWER ON TIME =============================
#define ADCCHANNEL_JUMPER 0x01

void initJumperRead() {
    // one-time read of the jumper ADC value, which tells us which
    //   of J1/J2 are in/out.  After read at powerup time, 
    //   we don't need to access ADC1 anymore.

    // NOTE: IF THE STC PROGRAMMER IS CONNECTED, THE ADC READ WILL
    //  ALWAYS BE HIGH, AND BOTH JUMPERS WILL APPEAR TO BE IN.

    // init ADC for JUMPER READ, P3.1/ADC1 -----
    GPIO_P3_SetMode(GPIO_Pin_1, GPIO_Mode_Input_HIP);  // Set ADC1(GPIO P3.1) HIP
    ADC_SetClockPrescaler(0x01);    // ADC Clock = SYSCLK / 2 / (1+1) = SYSCLK / 4
    ADC_SetResultAlignmentLeft();   // Left alignment, high 8-bit in ADC_RES
    ADC_SetPowerState(HAL_State_ON); // Turn on ADC power

    // READ ADC1 value --------
    ADC_SetChannel(ADCCHANNEL_JUMPER);  // Channel: ADC1
    ADC_Start();
    nop();
    nop();

    while (!ADC_SamplingFinished());  // WAIT...

    ADC_ClearInterrupt();
    jumperADC = ADC_RES;

    //             measured
    // J1     J2     out     threshold
    // ===============================
    // out    out     77
    //                   ----- 95
    // out     in    112
    //                   ----- 120
    //  in    out    129
    //                   ----- 140
    //  in     in    150
    //
    // therefore threshold values to split 
    //   into 4 buckets are:  95, 120, 140
    //
    // NOTE: IF THE STC PROGRAMMER IS CONNECTED, THE ADC READ WILL
    //  ALWAYS BE HIGH, AND BOTH JUMPERS WILL APPEAR TO BE IN.
    
    jumperJ1_IN = false;
    jumperJ2_IN = false;
    if (jumperADC > 120) {
        jumperJ1_IN = true;
        if (jumperADC > 140) {
            jumperJ2_IN = true;
        }
    } else {
        // we know that J1 is OUT
        if (jumperADC > 95) {
            jumperJ2_IN = true;
        }
    }
}

// ==========================================================
// BATTERY MONITOR AND LED ==================================
#define PIN_LED P55
#define PIN_BATTMON P54
#define ADCCHANNEL_BATTMON 0x04

#define TURN_LED_ON(x)  { PIN_LED = RESET; }
#define TURN_LED_OFF(x) { PIN_LED = SET;   }

void initBatteryMonitorAndLED() {
    // init LED -----
    GPIO_P5_SetMode(GPIO_Pin_5, GPIO_Mode_InOut_OD); // LED = open drain
    TURN_LED_OFF()

    // init ADC for Battery Monitor -----
    GPIO_P5_SetMode(GPIO_Pin_4, GPIO_Mode_Input_HIP);  // Set ADC4(GPIO P5.4) HIP
    ADC_SetClockPrescaler(0x01);    // ADC Clock = SYSCLK / 2 / (1+1) = SYSCLK / 4
    ADC_SetResultAlignmentLeft();   // Left alignment, high 8-bit in ADC_RES
    ADC_SetPowerState(HAL_State_ON); // Turn on ADC power
}

void showFirmwareVersion() {
    // Flash the LED "firmwareMinorVersion" number of times
    //  to indicate which version we are running...
    // Right now, we're NOT going to flash for firmwareMajorVersion (that's
    //   for future expansion)
    TURN_LED_OFF()
    SYS_Delay(500); // wait 1/2 sec (in total) for everything to settle

    // NOTE: one extra flash for reversed RVC -------
    uint8_t numFlashesAtPowerup = firmwareMinorVersion + (jumperJ1_IN ? 0 : 1); // IN/NORM = 2, OUT/REV = 3 flashes
    for (uint8_t i = 0; i < numFlashesAtPowerup; i++) {
        // blink
        SYS_Delay(100);
        TURN_LED_ON()
        SYS_Delay(100);
        TURN_LED_OFF()
    }
    SYS_Delay(500); // wait 1/2 sec (in total) for everything to settle
}

inline void serviceBatteryMonitorAndLED() {
    // READ ADC4 value --------
    ADC_SetChannel(ADCCHANNEL_BATTMON);  // Channel: ADC4
    ADC_Start();
    nop();
    nop();

    while (!ADC_SamplingFinished());  // WAIT...

    ADC_ClearInterrupt();
    uint8_t result = ADC_RES;

    // battery voltage = 0 - 12vdc, divider = 20Kohm/67Kohm = 0.3
    //   so, battery voltage 12v maps to (12 * 0.3)/5 * 255 => 184
    //   so, battery voltage  9v maps to ( 9 * 0.3)/5 * 255 => 138

    //   so, battery voltage  7v maps to ( 7 * 0.3)/5 * 255 => 107
    //   so, battery voltage  6v maps to ( 6 * 0.3)/5 * 255 =>  91
    
    //   so, battery voltage  4.6v maps to ( 4.6 * 0.3)/5 * 255 => 70 ( I get 70!) <-- USB Stick case

    // Here's our design choice:
    // 107 ==> 7.0V = HIGH WATER MARK = LED ON (below this, light starts flashing)
    //  91 ==> 6.0V = LOW WATER MARK = LED OFF 90%/ON 10%

    // actually measured on the Mixer V2.2 board: flashing starts at 7.2V (which is fine,
    //   there's always a little uncertainty in the ADC measurement)
    //
    // Measurements predict that once flashing begins, 
    //   the AMZN Alkaline will die in about 40 hours
    //   the Tencent Lithium will die in about 18 hours
    // As battery exhaustion gets closer, the LED will be on less and less.
    //
    // NOTE: the rechargeable USB lithium batteries will die without any warning!

    // // DEBUG DEBUG DEBUG JUMPER ************
    // if (!jumperJ1_IN) {
    //     if (!jumperJ2_IN) {
    //         result = 0; // both out
    //     } else {
    //         result = 110; // just J2 in
    //     }
    // } else {
    //     if (!jumperJ2_IN) {
    //         result = 120;  // just J1 in
    //     } else {
    //         result = 130; // both in
    //     }
    // }
    // // DEBUG DEBUG DEBUG JUMPER ************

    // LED ----------------------
    // counter goes from slot 0 - 9 over 2 seconds (200ms per slot)
    int lastSlot; // slot (0-9) which is last ON slot, others are OFF
    if (result < 91) {
        lastSlot = 0;  // this is as low as we can go, LED is never fully OFF
                       // but, LED dims and MCU stops working at Battery = 3.0VDC
    } else if (result > 108) {
        lastSlot = 10; // always ON
    } else {
        // result = 91 to 108 maps to => 0 - 17 maps to => lastSlot = 1 to 9
        // 0/1 = 1
        // 2/3 = 2
        // 4/5 = 3
        // 6/7 = 4
        // 8/9 = 5
        // 10/11 = 6
        // 12/13 = 7
        // 14/15 = 8 // flashing starts here at 91+15 = 106 => 7.0 volts
        // 16/17 = 9 // still fully ON
        lastSlot = ((result - 91) >> 1) + 1; // fast integer division by 2
    }

    // example: if lastSlot is 8, turn OFF if we're in slot 9.
    if (LEDCounter > lastSlot) {
        TURN_LED_OFF()
    } else {
        TURN_LED_ON()
    }

    // LEDCounter = 0 - 9
    if (++LEDCounter >= 10) {
        LEDCounter = 0;
    }

#ifdef DEBUG_OUTPUT
    // PRINT IT -----
    // UART1_TxString("ADC=0x");
    // UART1_TxHex(result & 0xFF);
    UART1_TxHex(jumperADC & 0xFF); // print out the jumper value
    // UART1_TxString("\r\n");
    UART1_TxString(",");
#endif
}

// ==========================================================
// REMOTE VOLUME CONTROL ===========================
// ADC3 on P3.3
// VOL_CLK on P3.0
// VOL_DATA on P3.1
// VOL_LOAD on P3.2

#define PIN_ATTEN_CLK  P30
#define PIN_ATTEN_DATA P31
#define PIN_ATTEN_LOAD P32

// --------------------------------------------------------
// 0 = 0dB attenuation, >=63 = MUTE
void setAttenuation(uint8_t attenInDB) {
    // Expanding all loops so that the entire cycle takes the minimal time
    //   to set the attenuation.  This completely eliminates popping!
    // This also allows us to return from servicing ASAP, to reduce power consumption.
    PIN_ATTEN_CLK = 0;
    PIN_ATTEN_DATA = 0;
    PIN_ATTEN_LOAD = 0; // SPEC: CLOCK must go down before LOAD goes down (2 cycles = 84ns)
    nop();
    nop();
    nop();
    nop();
    nop();
    nop();

    // ADDRESS = 0x00 ----------------------
    // SPEC: LOAD LOW to CLOCK HIGH >200ns ( 6 * 42 = 252ns)
    // SPEC: DATA VALID to CLOCK HIGH > 100ns ( 7 * 42 = 294ns)
    PIN_ATTEN_CLK = 1; // A7 
    nop(); // these might not be strictly necessary, but it makes them more visible on Saleae
    PIN_ATTEN_CLK = 0;
    nop();
    PIN_ATTEN_CLK = 1; // A6
    nop();
    PIN_ATTEN_CLK = 0;
    nop();
    PIN_ATTEN_CLK = 1; // A5
    nop();
    PIN_ATTEN_CLK = 0;
    nop();
    PIN_ATTEN_CLK = 1; // A4
    nop();
    PIN_ATTEN_CLK = 0;
    nop();
    PIN_ATTEN_CLK = 1; // A3
    nop();
    PIN_ATTEN_CLK = 0;
    nop();
    PIN_ATTEN_CLK = 1; // A2
    nop();
    PIN_ATTEN_CLK = 0;
    nop();
    PIN_ATTEN_CLK = 1; // A1
    nop();
    PIN_ATTEN_CLK = 0;
    nop();
    PIN_ATTEN_CLK = 1; // A0
    nop(); // SPEC: DATA HOLD TIME > 50ns (2 cycles = 84ns)

    // DATA -----------------------------
    PIN_ATTEN_CLK = 0; // CLK low
    PIN_ATTEN_DATA = (attenInDB & 0x80) >> 7;
    nop();
    nop();
    nop(); // SPEC: DATA SETUP TIME > 100ns ( 3 cycles = 120ns)
    PIN_ATTEN_CLK = 1; // CLK high <-- data on positive edge
    nop(); // SPEC: DATA HOLD TIME > 50ns (2 cycles = 84ns)

    PIN_ATTEN_CLK = 0; // CLK low
    PIN_ATTEN_DATA = (attenInDB & 0x40) >> 6;
    nop();
    nop();
    nop(); // SPEC: DATA SETUP TIME > 100ns ( 3 cycles = 120ns)
    PIN_ATTEN_CLK = 1; // CLK high <-- data on positive edge
    nop(); // SPEC: DATA HOLD TIME > 50ns (2 cycles = 84ns)

    PIN_ATTEN_CLK = 0; // CLK low
    PIN_ATTEN_DATA = (attenInDB & 0x20) >> 5;
    nop();
    nop();
    nop(); // SPEC: DATA SETUP TIME > 100ns ( 3 cycles = 120ns)
    PIN_ATTEN_CLK = 1; // CLK high <-- data on positive edge
    nop(); // SPEC: DATA HOLD TIME > 50ns (2 cycles = 84ns)

    PIN_ATTEN_CLK = 0; // CLK low
    PIN_ATTEN_DATA = (attenInDB & 0x10) >> 4;
    nop();
    nop();
    nop(); // SPEC: DATA SETUP TIME > 100ns ( 3 cycles = 120ns)
    PIN_ATTEN_CLK = 1; // CLK high <-- data on positive edge
    nop(); // SPEC: DATA HOLD TIME > 50ns (2 cycles = 84ns)

    PIN_ATTEN_CLK = 0; // CLK low
    PIN_ATTEN_DATA = (attenInDB & 0x08) >> 3;
    nop();
    nop();
    nop(); // SPEC: DATA SETUP TIME > 100ns ( 3 cycles = 120ns)
    PIN_ATTEN_CLK = 1; // CLK high <-- data on positive edge
    nop(); // SPEC: DATA HOLD TIME > 50ns (2 cycles = 84ns)

    PIN_ATTEN_CLK = 0; // CLK low
    PIN_ATTEN_DATA = (attenInDB & 0x04) >> 2;
    nop();
    nop();
    nop(); // SPEC: DATA SETUP TIME > 100ns ( 3 cycles = 120ns)
    PIN_ATTEN_CLK = 1; // CLK high <-- data on positive edge
    nop(); // SPEC: DATA HOLD TIME > 50ns (2 cycles = 84ns)

    PIN_ATTEN_CLK = 0; // CLK low
    PIN_ATTEN_DATA = (attenInDB & 0x02) >> 1;
    nop();
    nop();
    nop(); // SPEC: DATA SETUP TIME > 100ns ( 3 cycles = 120ns)
    PIN_ATTEN_CLK = 1; // CLK high <-- data on positive edge
    nop(); // SPEC: DATA HOLD TIME > 50ns (2 cycles = 84ns)

    PIN_ATTEN_CLK = 0; // CLK low
    PIN_ATTEN_DATA = (attenInDB & 0x01);
    nop();
    nop();
    nop(); // SPEC: DATA SETUP TIME > 100ns ( 3 cycles = 120ns)
    PIN_ATTEN_CLK = 1; // CLK high <-- data on positive edge
    nop(); // SPEC: DATA HOLD TIME > 50ns (3 cycles = 120ns)
    nop();

    // finish up ------
    PIN_ATTEN_LOAD = 1; // SPEC: CLOCK TO LOAD HIGH > 50ns (2 cycles = 84ns)
    PIN_ATTEN_DATA = 1; // DATA high
}

// --------------------------------------------------------
void initRemoteVolumeControl() {
    GPIO_P3_SetMode(GPIO_Pin_3, GPIO_Mode_Input_HIP);  // Set ADC3(GPIO P3.3) High-impedance InPut
    GPIO_SetPullUp(GPIO_Port_3, GPIO_Pin_3, HAL_State_OFF);    // ensure NO PULLUP RESISTOR
    GPIO_P3_SetMode(GPIO_Pin_0|GPIO_Pin_1|GPIO_Pin_2, GPIO_Mode_Output_PP); // VOL_* are Push-Pull outputs

    PIN_ATTEN_LOAD = 1; // LOAD
    PIN_ATTEN_CLK  = 1; // CLK
    PIN_ATTEN_DATA = 1; // DATA

    // TODO: These should already be set elsewhere, so comment out
    ADC_SetClockPrescaler(0x01);    // ADC Clock = SYSCLK / 2 / (1+1) = SYSCLK / 4
    ADC_SetResultAlignmentLeft();   // Left alignment, high 8-bit in ADC_RES
    ADC_SetPowerState(HAL_State_ON); // Turn on ADC power

    setAttenuation(15); // low output until AFTER the firmware version flashes, then RVC-specified output
}

// --------------------------------------------------------
void serviceRemoteVolumeControl(bool force) {
#define ATTEN_STEP_DELAY_US 50
    
    ADC_SetChannel(0x03);           // RVC channel = ADC3
    ADC_Start();
    nop();
    nop();

    while (!ADC_SamplingFinished());  // WAIT...

    ADC_ClearInterrupt();
    uint8_t RVCval = ADC_RES;

// #ifdef DEBUG_OUTPUT
//     // PRINT IT -----
//     UART1_TxHex(RVCval); // print out the remote volume control value
//     UART1_TxString(",");
// #endif    

    // At this point, we know what the remote volume control is set to.
    // "RVCval" at this point will be:
    //
    //    open (no RVOL) = 0xFF
    //    full CCW = 0xD3 <-- NOTE: this is wrong now, should be about 133 now
    //    full CW  = 0x00
    //
    // Most right-handed users will turn the pot CW to increase volume.
    // Some users (perhaps left-handed) might prefer to push the pot CCW to increase volume.
    //
    // Jumper J1 (read at power up time) selects between the two:
    //
    //             J1 IN          J1 OUT
    //             left-handed    right-handed
    //           +--------------+--------------+
    //   Pot CW  | VOL DOWN     | VOL UP       |
    //   Pot CCW | VOL UP       | VOL DOWN     |
    //           +--------------+--------------+
    //
    // We could use the other jumper to decide whether the min volume is ZERO (e.g.
    //   in place of the MUTE function that some Hilton cables have), or the min
    //   volume should be say 20% of the max volume (which I have heard some
    //   callers prefer).  For the moment, J2 is currently UNASSIGNED.
    //

    if (RVCval > 0xE0) {
        // no Remote Volume Control at all, so result attenuation (res) is 0dB
        res = 0;
    } else {
        // we have a Remote Volume Control plugged in

        // RVCval range = {0, 133 or so (depends on tolerance of pot)}
        uint16_t top = (RVCval << 8) - RVCval; // (RVCval * 255)
        uint16_t bot = (255 - RVCval);         // (255 - RVCval)
        uint16_t linearPotVal = top/bot;  // range: {0, 256}
            // NOTE: this divide should be fast, because STC8G1K08A has MCU16 HW divider

        if (linearPotVal > 255) {
            linearPotVal = 255; // cap this, just in case
        }

// NO SLEEPY RANGE: 0 - 133

// -----------------------
// PICK EXACTLY ONE:
//#define CURRENTALGORITHM
#define NEWALGORITHM
// -----------------------

#ifdef CURRENTALGORITHM
    uint16_t q1 = linearPotVal/3;
    if (q1 >= 80) {
        // don't allow attenuations of less than 0
        q1 = 80;
    }

    res = 80 - q1;
    if (res > 64) {
        // don't allow attenuations of more than 64dB
        res = 64;
    }

    // RESULTING ATTENUATION = res, range: 0 - 64

#endif

#ifdef NEWALGORITHM
        /* ******************** NEW ALGORITHM ******************** */
        // ***** J1 IN = LEFT-HANDED or "REVERSED" VOL CTRL DIRECTION
        uint8_t A = 3*64; // turn pot 3/4 of the way
        uint8_t B = 14;   //  to attenuate by 12dB @ knee of the curve
        uint8_t C = 48;   // then drop to mute
        uint8_t D = 236;  //  at the end of the pot travel (guard band)
        uint8_t E = 6;      //  at the beginning of the pot travel (guard band)

        if (!jumperJ1_IN) {
            // ***** J1 OUT = RIGHT-HANDED or "NORMAL" VOL CTRL DIRECTION
            // A = 3*64;  // these are the same for both cases, so commented them out
            // B = 14;
            // C = 48;
            // D = 236;
            E = 11;
            linearPotVal = 255 - linearPotVal; // 255 - 0
        }

        // the newest algorithm -----------------
        if (linearPotVal < E) {
            res = 0; // result = no attenuation
        } else if (linearPotVal > D) {
            res = 64; // attenuation = MAX
        } else if (linearPotVal <= A) {
            // intermediate result = uint16, attenuation is positive
            res = ((linearPotVal - E) * B)/A;
        } else { // x > A
            // intermediate result = uint16, attenuation is positive
            res = B + ((uint16_t)(linearPotVal-A) * (uint8_t)(C-B))/(uint8_t)(D-A);
        }
        /* ******************** END NEW ALGORITHM ******************** */
#endif

    } // end else

    if (force) {
        setAttenuation(res); // one time force
    } else {
        // step it up or down in increments of 1 dB to avoid zipper effect
        if (previousRes < res) {
            // step UP to get to correct level of attenuation
            for (uint8_t a = previousRes+1; a < res; a++) {
                setAttenuation(a);
    #if ATTEN_STEP_DELAY_US > 0
                SYS_DelayUs(ATTEN_STEP_DELAY_US);
    #endif            
            }
            setAttenuation(res);
        } else if (res < previousRes) {
            // step DOWN to get to correct level of attenuation
            for (uint8_t a = previousRes-1; a > res; a--) {
                setAttenuation(a);
    #if ATTEN_STEP_DELAY_US > 0
                SYS_DelayUs(ATTEN_STEP_DELAY_US);
    #endif            
            }
            setAttenuation(res);
        } else { 
            // else do nothing if old and new attenuation values are equal
            // setAttenuation(res);  // DEBUG DEBUG DEBUG
        }
    }
    previousRes = res; // remember where we are now (regardless of force or not)
}

// ==========================================================
// UART ==========================
#ifdef DEBUG_OUTPUT
void initUART() {
    // UART1_Config8bitUart(UART1_BaudSource_Timer1, HAL_State_ON, 115200); // 115200/8/N/1
    // UART1_Config8bitUart(UART1_BaudSource_Timer1, HAL_State_ON, 115200); // 115200/8/N/1
    UART1_Config8bitUart(UART1_BaudSource_Timer1, HAL_State_ON, 174563); // =115200/8/N/1  FIX FIX FIX: slow MCU clock
}
#endif

// ==========================================================
// POWER CONTROL ==================
#define M_PD 0x2
void enterPowerDownMode() {
	PCON |= M_PD;
	nop();
	nop();
}

void initSleepControl() {
#ifdef SLEEPY
    // ENABLE WATCHDOG WAKEUP -----
    // see section 6.6.1 of the STC8G-EN.pdf manual for a table of these

    // WKTCL = 0x01;
    // WKTCH = 0x80;   // wake up every 1ms (1000X/sec), good for 1:16 PWM on LED

    WKTCL = 0x63;
    WKTCH = 0x80;   // wake up every 50ms (20X/sec) 

    // WKTCL = 0x8F;
    // WKTCH = 0x81;   // wake up every 200ms (5X/sec), spreadsheet gives 0x018F, the 0x80 is WKT ENABLE
#endif
}

inline void sleepUntilTimeToWakeup() {
#ifdef SLEEPY
    // GET READY TO SLEEP AGAIN -----
    P3M1 &= ~0x7F; // all pins on P3 go to sleep right now, except ADC:P3.3
    P3M0 &= ~0x7F;
    P3 |= 0xFF;

    P5M1 &= ~0xCF; // all pins on P5 go to sleep except LED:P5.5, BATTMON: P5.4
    P5M0 &= ~0xCF;
    //P5 |= 0xDF;

    enterPowerDownMode();
#else        
    SYS_Delay(25); // 40X/sec
#endif        
}

// ===============================================================================
// MAIN ==========================================================================
// ===============================================================================
void main()
{
    SYS_SetClock();  // Set system clock. Removed because system clock is already set by STC-ISP X86

    initJumperRead();  // read the jumper value J1/J2 (analog value)
    initRemoteVolumeControl();
    initBatteryMonitorAndLED();
    initSleepControl();

    // before we get going, service these once
    serviceBatteryMonitorAndLED(); // service once to set LED

    // this takes a while...
    showFirmwareVersion();

    // after running at 12dB for a second, now go to RVC volume
    serviceRemoteVolumeControl(true);  // service once to force init volume as per RVC

#ifdef DEBUG_OUTPUT
    initUART();
#endif

    uint8_t batteryCounter = 0;

    // MAIN LOOP -----------------
    while(1)
    {
        // WAKE UP!
        if (batteryCounter++ & 0x03 == 0x03) {
            // Running the wakeups at 20X/sec now, so let's call the battery 
            //   monitor only every 4th time, so that it gets called only every 200ms.
            // There are 10 slots, so the cycle time for battery animations
            //   is back down to every 2 seconds.
            serviceBatteryMonitorAndLED();
        }

        serviceRemoteVolumeControl(false);  // service this one 20X/sec, so no lag

        // BACK TO SLEEP...
        sleepUntilTimeToWakeup();  // 20X/sec
    }
}

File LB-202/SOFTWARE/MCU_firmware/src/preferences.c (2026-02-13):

#include "globals.h"

#include "preferences.h"
#include "fw_hal.h"

#ifdef INCLUDE_PREFERENCES

// State
static uint16_t s_next_write_offset = 0;
static bool s_initialized = false;

// =========================================================
// Helper to read a byte
static uint8_t ReadByte(uint16_t addr) {
  IAP_SetEnabled(HAL_State_ON);

  IAP_CmdRead(addr);
  if (IAP_IsCmdFailed()) {
    IAP_ClearCmdFailFlag();
#ifdef DEBUG
    // UART1_TxString("ReadByte: IAP Read Failed at ");
    // UART1_TxHex(addr >> 8);
    // UART1_TxHex(addr & 0xFF);
    // UART1_TxString("\r\n");
#endif    
    IAP_SetEnabled(HAL_State_OFF);
    return 0xFF; // Return 0xFF on failure (erased state)
  }
  uint8_t data = IAP_ReadData();
  IAP_SetEnabled(HAL_State_OFF);
  return data;
}

// =========================================================
void Pref_Dump() {
#ifdef DEBUG
  IAP_SetEnabled(HAL_State_ON);
  UART1_TxString("Preferences EEPROM Dump:\r\n");

  // dump preferences for debug
#define NUM_DUMP_ROWS 8  
  for (uint8_t i = 0; i < NUM_DUMP_ROWS; i++) {
    for (uint8_t j = 0; j < 16; j++) {
      uint16_t addr = PREF_START_ADDR + (i << 4) + j;
      if (j == 0) {
        UART1_TxHex(addr >> 8);
        UART1_TxHex(addr & 0xFF);
        UART1_TxChar(':');
      }
      UART1_TxHex(ReadByte(addr));
      if (j < 15) {
        UART1_TxChar(' ');
      } else {
        UART1_TxString("\r\n");
      }
    }
  }
    IAP_SetEnabled(HAL_State_OFF);
#endif
}

// =========================================================
void Pref_Init() {
  IAP_SetEnabled(HAL_State_ON);

  // Write default value to first slot
  IAP_WriteData(PREF_DEFAULT_VALUE); // must have bit 7 = 0 (indicates valid entry)
  IAP_CmdWrite(PREF_START_ADDR);

  if (IAP_IsCmdFailed()) {
    IAP_ClearCmdFailFlag();
#ifdef DEBUG
    // UART1_TxString("IAP Write Failed during Pref_Init\r\n");
#endif  
  }

  s_next_write_offset = 1; // Next write goes to slot 1
  s_initialized = true; 
  IAP_SetEnabled(HAL_State_OFF);
}

// =========================================================
void Pref_Read(Preferences_t *prefs) {
  uint16_t i;
  Preferences_t temp;

  IAP_SetEnabled(HAL_State_ON);

  // Scan backwards to find the latest valid entry (valid_marker == 0)
  // We start from the last byte of the sector
  #ifdef DEBUG
    // UART1_TxString("SCANNING FOR PREFS...\r\n");
  #endif
  for (i = PREF_SECTOR_SIZE; i > 0; i--) {
    uint16_t addr = PREF_START_ADDR + (i - 1);
    temp.value = ReadByte(addr);
#ifdef DEBUG
    // UART1_TxHex(addr >> 8);
    // UART1_TxHex(addr & 0xFF);
    // UART1_TxChar(':');
    // UART1_TxHex(temp.value);
    // UART1_TxString(" vm:");
    // UART1_TxHex(temp.valid_marker);
    // UART1_TxString("\r\n");
#endif
    // Check if valid_marker bit is 0 (valid entry)
    if (temp.valid_marker == 0) {
      s_next_write_offset = i; // Next write goes after this one
      s_initialized = true;
      IAP_SetEnabled(HAL_State_OFF);
      *prefs = temp;
#ifdef DEBUG
      // UART1_TxString("returning...\r\n");
#endif
      return;
    }
  }

  // No valid entry found, sector is empty or invalid
#ifdef DEBUG
  // UART1_TxString("sector empty/invalid...\r\n");
#endif
  s_next_write_offset = 0;
  s_initialized = true;
  IAP_SetEnabled(HAL_State_OFF);

  prefs->value = PREF_DEFAULT_VALUE;
}

// =========================================================
bool Pref_Write(const Preferences_t *prefs) {
  Preferences_t new_prefs;
  Preferences_t current_prefs;
  bool result;
  Preferences_t temp_prefs;

  // Copy and ensure valid_marker is 0
  new_prefs = *prefs;
  new_prefs.valid_marker = 0;

  // Initialize if needed (to find s_next_write_offset)
  if (!s_initialized) {
    Pref_Read(&temp_prefs);
  }

  IAP_SetEnabled(HAL_State_ON);

#ifdef DEBUG
  // UART1_TxString("Pref_Write: next_offset=");
  // UART1_TxHex(s_next_write_offset);
  // UART1_TxString(", new_value=");
  // UART1_TxHex(new_prefs.value);
  // UART1_TxString("\r\n");
#endif  

  // Check current value to avoid unnecessary writes
  if (s_next_write_offset > 0) {
    current_prefs.value = ReadByte(PREF_START_ADDR + s_next_write_offset - 1);
    current_prefs.valid_marker = 0;  // Ensure it's treated as valid
  } else {
    current_prefs.value = PREF_DEFAULT_VALUE;
  }

  if (current_prefs.value == new_prefs.value) {
#ifdef DEBUG
    // UART1_TxString("Pref_Write: value unchanged, no write needed.\r\n");
#endif    
    result = true; // Nothing to do
    goto cleanup;
  }

  // Check if sector is full
  if (s_next_write_offset >= PREF_SECTOR_SIZE) {
#ifdef DEBUG
    // UART1_TxString("Pref_Write: sector full, erasing...\r\n");
#endif
    // *** ADD THIS: Cycle IAP after erase ***
    IAP_SetEnabled(HAL_State_OFF);
    IAP_SetEnabled(HAL_State_ON);

    IAP_CmdErase(PREF_START_ADDR);
    if (IAP_IsCmdFailed()) {
      #ifdef DEBUG
        // UART1_TxString("Pref_Write: IAP Erase Failed\r\n");
      #endif
      IAP_ClearCmdFailFlag();
      result = false;
      goto cleanup;
    }

    // *** ADD THIS: Cycle IAP after erase ***
    IAP_SetEnabled(HAL_State_OFF);
    IAP_SetEnabled(HAL_State_ON);

    s_next_write_offset = 0;
  }

  // Re-enable IAP before write (ReadByte disabled it)
  IAP_SetEnabled(HAL_State_OFF);
  IAP_SetEnabled(HAL_State_ON);

  // Write new value
  IAP_WriteData(new_prefs.value);
  IAP_CmdWrite(PREF_START_ADDR + s_next_write_offset);

  if (IAP_IsCmdFailed()) {
#ifdef DEBUG
    // UART1_TxString("Pref_Write: IAP WriteData Failed\r\n");
#endif    
    IAP_ClearCmdFailFlag();
    result = false;
    goto cleanup;
  }

  s_next_write_offset++;
  result = true;

cleanup:
  IAP_SetEnabled(HAL_State_OFF);

  Pref_Dump(); // debug dump

  return result;
}

#endif // INCLUDE_PREFERENCES

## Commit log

2024-03-17 Added unit cost spreadsheet
    Shows V1 and V2 costs. LibreOffice format.
    [Unit Cost.ods]
2024-03-20 Battery Life plot
    Based on Wavypo USB Rechargeable battery (from AMZN), and AMZN Basics Alkaline battery (also from AMZN).
2024-03-24 Posted V2 files
    Updated the README, posted the V2 board files. Moved the cost file into the V2 folder.
    [BOM_Board2_PCB2_2024-02-03_EDITED.csv, PickAndPlace_PCB2_2024-02-03.csv, V2 unit cost.ods]
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2024-03-24 Commited firmware files
    This is everything that is currently implemented. Does NOT include the Remote Volume Control firmware yet. That's in a separate file that I need to merge into this one, once it's been tested.
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2024-03-24 Update README.md
    Added info from the cut sheet to the README file. Added a picture.
2024-03-29 Adding files for the prototype enclosure
    Lightburn files for laser-cut top/bottom/back/front, Fusion and STL files for the side panels.
    [BOM_Board2_PCB2_2024-02-03_EDITED_withPinCount.csv, sidePanel_V2 Body4.stl, sidePanel_V2 v9 Fusion.f3d]
2024-03-29 Update README.md
    Info on enclosure files. Clarified that BOM from EasyEDA needs to be hand-edited.
2024-04-02 Add LTspice files
    Both the .asc/asy (model) files and their PDF (printable) equivalents are now publically available.
2024-04-05 Commit V3 designs
    Enclosure (5052 Al, 2 pieces), Main PCB, and XLR PCB are now submitted for fabrication at Fabworks and JLCPCB respectively.
    [BOM_Board1_PCB1_2024-03-31_FABBED.csv, BOM_Board2_mixer project v2.2_2024-04-04_FABBED.csv, PickAndPlace_PCB1_2024-03-31_FABBED.csv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]
2024-04-09 pics and a spacer
    The laser-cut spacer compensates for the fact that the sheet metal is only 0.040", which is too thin to hold the switch in place.
2024-04-15 Updated battery life plot
    Now includes the results from the Tencent Lithium 9V battery test.
2024-04-15 Data sheets for the key components on the main board
    For easy access.
2024-04-15 Stable version of the firmware
    Firmware is not final, but it now supports the remote volume control (with ZERO pops!), so it's time to check in a version that basically works. There is more polishing to do here, certainly, but thi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
2024-04-16 Updated the battery life plot
    High and low water marks are now shown (as implemented in the latest FW).
2024-04-16 Tweaked low battery warning
    Low battery warning starts flashing the LED at about 7.2V now, and the LED will be on less and less down to about 6.0V when it's on only 1/10 of the time. At that point, battery life will be a handfu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
2024-04-16 Documented sources for most parts
    Remainder of parts are sourced from (and assembled by) JLCPCB.
2024-04-16 Battery test files
    Including the R script to process the data from pushdata.io (where the raw data was pushed by the ESP32 I had monitoring the battery voltage during the battery tests).
2024-04-16 Clarified licenses
    With LICENSE.txt files in a couple more places, just to be sure.
2024-04-22 Pics of the laser engraving experiments
    See Issue #5 for description and discussion of the results.
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2024-05-06 Pic of testing the top of the enclosure
    FIber laser engraved in 2 separate engrave operations (left and right halves).
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2024-05-10 Pics of V3 powder-coated enclosure
    And, a modified power switch spacer. Note that the top-level visible grain should go up/down, rather than right/left on these. Otherwise, they are more likely to splinter.
2024-05-10 Update README.md
    Added latest pics, latest battery test results, and added more info to the specs section.
2024-05-10 Laser engraving files, latest bottom+side panels
    No longer using the "bottom only" file, but it's still here in the "old/" directory.
    [V3 Enclosure BOTTOM v4_FABBED.f3d, V3 Enclosure BOTTOM v4_FABBED.step, V3 U-shaped bottom + side panels v5.f3z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]
2024-07-14 Update cutsheet with lastest pic and details
    [V3 unit cost.ods]
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2024-07-21 Updated cost spreadsheet
    [V3 unit cost.ods]
2024-09-21 Add V4 fabrication and cost data
    [BOM_Board2_PCB2.4_2024-08-26.csv, Kit Contents LB-102.ods, PickAndPlace_PCB2.4_2024-08-26.csv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]
2024-09-21 More updates
    [BOM_Board2_PCB2.4_2024-08-26.csv, V3 unit cost.ods]
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2024-10-04 #19: sudden drop in volume in NORMAL mode fixed
    SLEEPY low-power mode causes ADC weirdness.
    [main.c]
2024-11-13 Update files for latest build (as of 2024.11.12)
    V4 is the first batch of 20 devices. This is what was built.
    [BOM_Board1_PCB1_2024-03-31_FABBED.csv, BOM_Board2_PCB2.4_2024-08-26.csv, PickAndPlace_PCB1_2024-03-31_FABBED.csv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]
2024-11-16 Added small PCBs to simplify wiring
    Remote Volume Control board, Music IN board (with switch), XLR OUT board, and Music L/Voice R OUT board.
    [BOM_Board1_PCB1_2024-11-15 (1).csv, BOM_Board1_PCB1_2024-11-15.csv, PickAndPlace_PCB1_2024-11-15.csv]
2024-12-31 New Remote Volume Board
    makes wiring up the RVC simpler and faster.
    [BOM_Board1_PCB1_2024-11-15.csv, PickAndPlace_PCB1_2024-11-15.csv]
2024-12-31 Remove obsolete cost spreadsheet
    It's way out of date now.
    [V4 unit and kit cost.ods]
2024-12-31 Update firmware to handle RVC better
    The RVC curve now has 5 sections: 2 guard bands around each end (for tolerances), a MUTE section (-64dB = mute), and two sloped sections (gentle for the first 3/4, aggressive for the last 1/4. This is very much like a Hilton curve, except it has the aggressive attenuation down to mute at the end.
    [main.c]
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2026-02-13 Publish entire electrical and mechanical design
    [BOM_Board1_PCB1_2025-11-20 (1).csv, BOM_Board1_PCB1_2026-02-06.csv, BOM_PCB3.0_PCB3.0_2026-02-06.csv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]
2026-02-13 Publish side panel designs
    [LEFT ENDCAP V18.step, RIGHT ENDCAP V9.step]
2026-02-13 Reorganize and separate LB-102 from LB-202 files
    [BOM_Board1_PCB1_2024-03-31_FABBED.csv, BOM_Board1_PCB1_2024-11-15 (1).csv, BOM_Board1_PCB1_2024-11-15.csv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]
2026-02-17 Check in Test Fixture files
    This test board is driven by a USB-to-Serial dongle via a JST-SH connector, that provides +5V and GND in addition to RxD, TxD, and RESET. Firmware not yet written, so this is just the hardware.
    [BOM_Board1_PCB1_2026-02-16.csv, PickAndPlace_PCB1_2026-02-16.csv]
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
